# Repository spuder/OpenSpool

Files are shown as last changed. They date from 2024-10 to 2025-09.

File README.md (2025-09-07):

<p align=center>
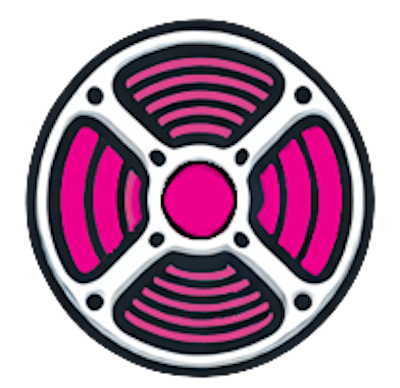
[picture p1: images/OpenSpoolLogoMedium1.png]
    
</p>

# OpenSpool
**Your filament wants to be free**


   

---

# 📖 [OpenSpool.io](https://openspool.io)

Checkout the official documentation on [https://openspool.io](https://openspool.io) 👈

---

<p align="center"> 
    Centered GIF 
</p>

Adhere NFC stickers on all your filament. Build an ESP32 OpenSpool reader and place it next to your printer. 
Touching the filament to the reader will automatically update your Bambu Printer filament settings. 
Almost as seamlessly as if you were using Bambu filament with an AMS. 

## 🖨️ Protocol

| Protocol  | Read | Write | Type |
| --- | --- | --- | --- |
| OpenSpool | ✅ | ✅ | NTAG 215/216 |
| TigerTag | 🚧 In progress | 🚧 In progress | NTAG 213 | 
| Bambu | 🚧 In progress | ❌ | MiFare Classic 1k |
| OpenTag3D | 🚧 In progress | 🚧 In progress | NTAG 213/215/216  |
| Creality  | 🗓️ Planned | 🗓️ Planned | MiFare Classic 1k |
| PrusaRFID | ❓ | ❓ | ❓ |
| Elegoo | 🔍 Researching | 🔍 Researching | ❓ | 
| Anycubic | 🔍 Researching | 🔍 Researching | ❓ | 

### 🧬 OpenTag3D Protocol

Many 3d printer filament companies are uniting around an open standard called `OpenTag3D`. It planned to be finalized in early-mid 2025. OpenSpool will support OpenTag formatted tags as soon as it is finalized. See [here](https://opentag3d.info) for more information.

### 🧬 OpenSpool Protocol

OpenSpool aims to use the simplest possible protocol for RFID tags. All you need is a [NTAG215/216](https://a.co/d/5ojDUNk) 

#### NDEF Record

Example record stored on NFC tag. 

```
type = `application/json`  
payload = 
{
    "protocol": "openspool",
    "version": "1.0",
    "type": "PLA",
    "color_hex": "FFAABB",
    "brand": "Generic",
    "min_temp": "220",
    "max_temp": "240"
}
```

<p align=center>
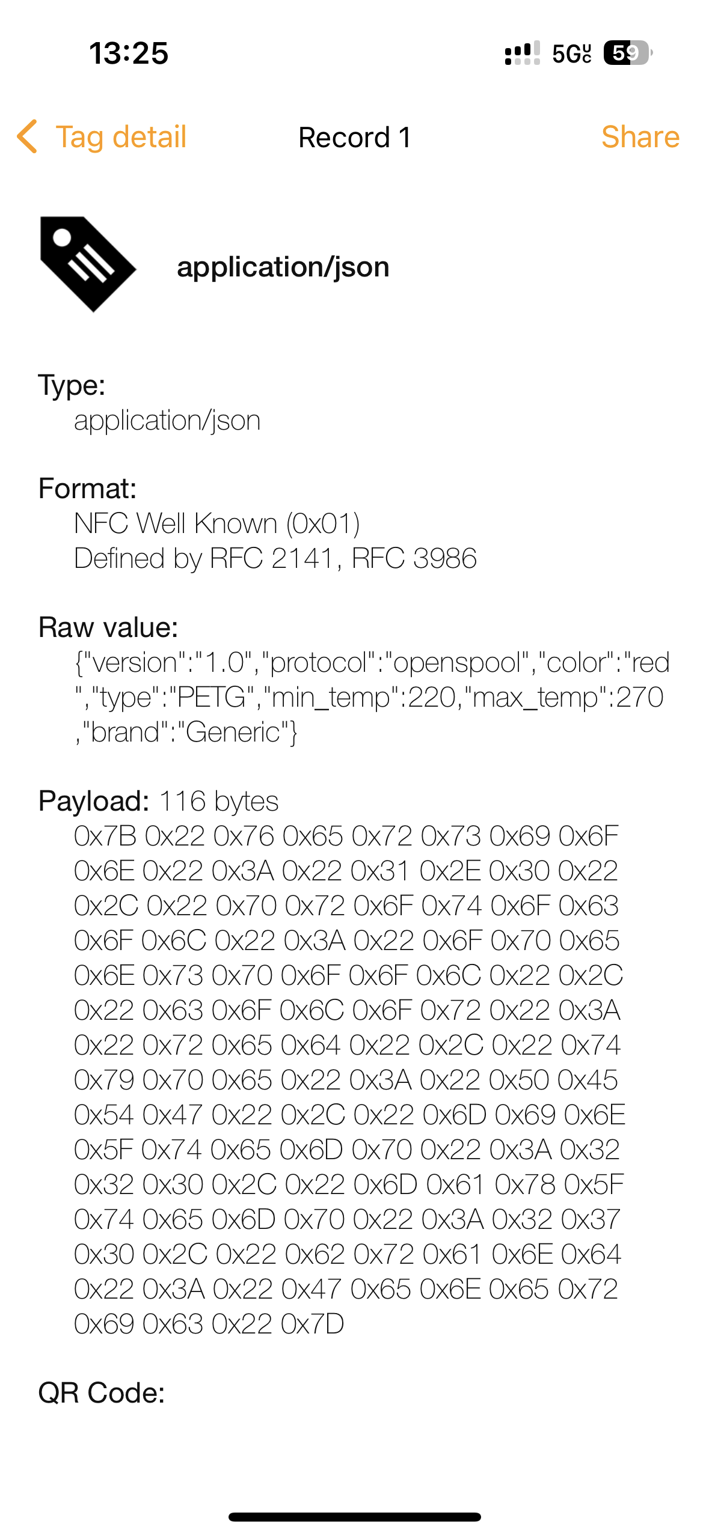
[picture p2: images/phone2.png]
    
</p>

#### Web Preview

Spool information can be seen using your phone.

<p align=center>
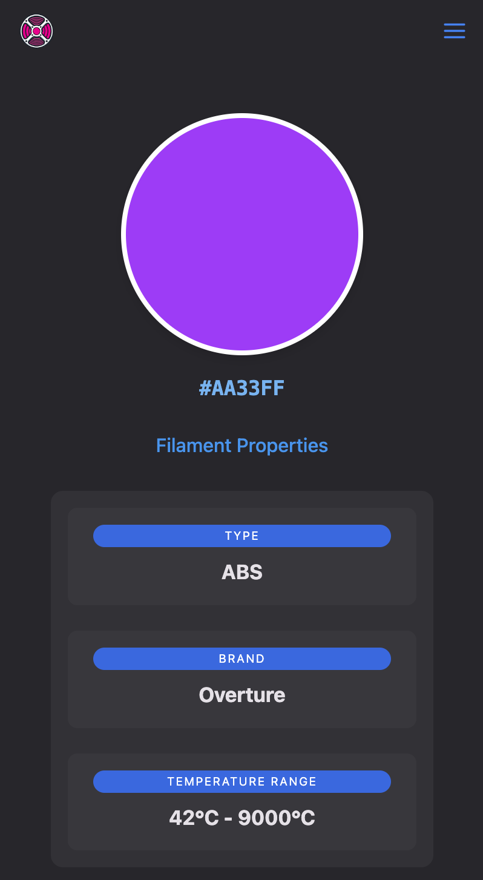
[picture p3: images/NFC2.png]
    
</p>

```
https://openspool.io/tag_info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
```

## 🐼 Integrations

Currently, OpenSpool works with Bambu printers over MQTT. Other integrations are planned. Pull Requests welcome

| Integration | Supported |
| --- | --- |
| Bambu | ✅ |
| OctoPrint | 🚧 In Progress |
| Prusa Connect | 🗓️ Planned |
| SpoolMan | 🗓️ Planned |
| Klipper / Moonraker | 🗓️ Planned |
| Anker | ❔ |

**Bambu**
Bambu X1C printers running `1.08.05.00` or newer must enable `LAN Mode` and `Developer Mode` for the OpenSpool reader to work. [Additional information](https://forum.bambulab.com/t/firmware-01-08-05-00-authorization-control-is-here/152239) on bambu's blog. 

All other Bambu Printers and X1C printers running firmware older than `1.08.05.xx` do not need to enable Developer Mode. 

## 🔧 Hardware

The OpenSpool schematics will always be free. If you don't want to source the parts yourself, you can [buy a kit on tindie.com](https://www.tindie.com/products/36746/).




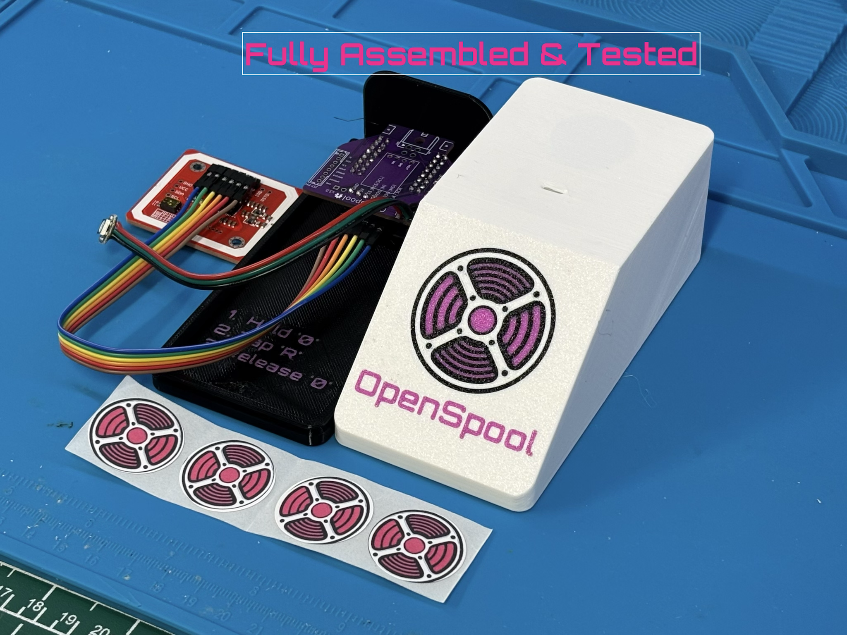
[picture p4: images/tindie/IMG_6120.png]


### Bill of Materials

| Image | Hardware | Link 1 | Link 2 |
| - | - | - | - |
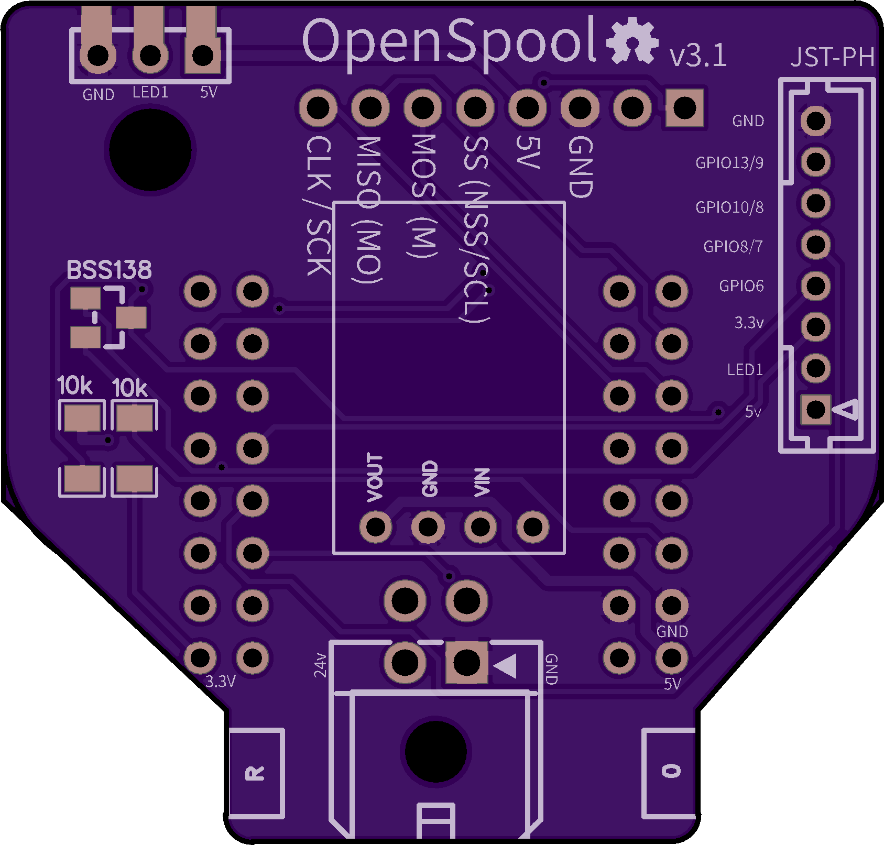
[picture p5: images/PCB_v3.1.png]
|  | OpenSpool Mini PCB v3.1 * | [Gerber Files](./hardware/openspool-mini/v3.1) | |
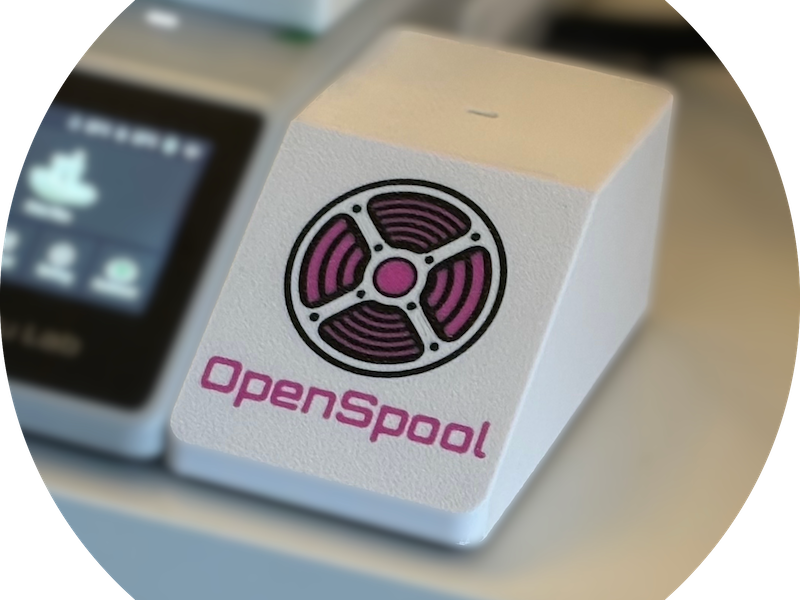
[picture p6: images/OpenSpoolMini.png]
|  | OpenSpool Mini Enclosure (3D Printed) | [MakerWorld](https://makerworld.com/en/models/944499-openspool-mini#profileId-910780) | |
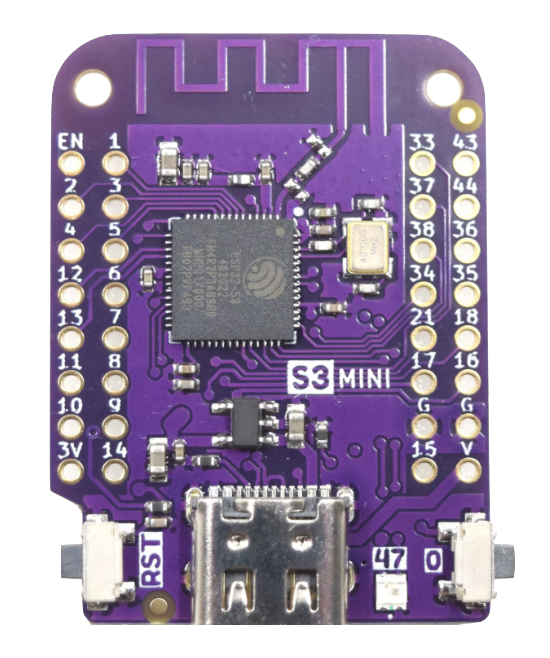
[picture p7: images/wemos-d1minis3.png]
|  | Wemos D1 Mini s3 |  | [AliExpress](https://www.aliexpress.us/item/3256805262904443.html?gatewayAdapt=glo2usa) |
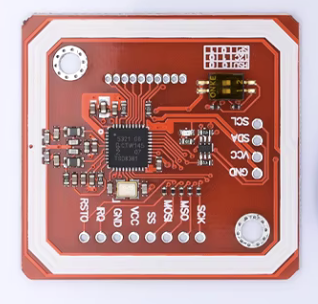
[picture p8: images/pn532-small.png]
|  | PN532 (Small)| [Amazon](https://amzn.to/4eoBz8s) | [AliExpress](https://www.aliexpress.us/item/3256805787598774.html) |
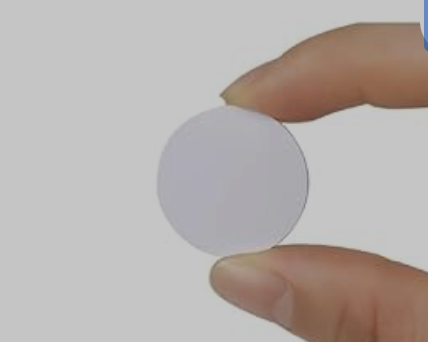
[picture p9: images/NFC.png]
|  | NTAG 215/216 (13.56Mhz NFC Tags >500 bytes) | [Amazon](https://amzn.to/4epJzpO) | |
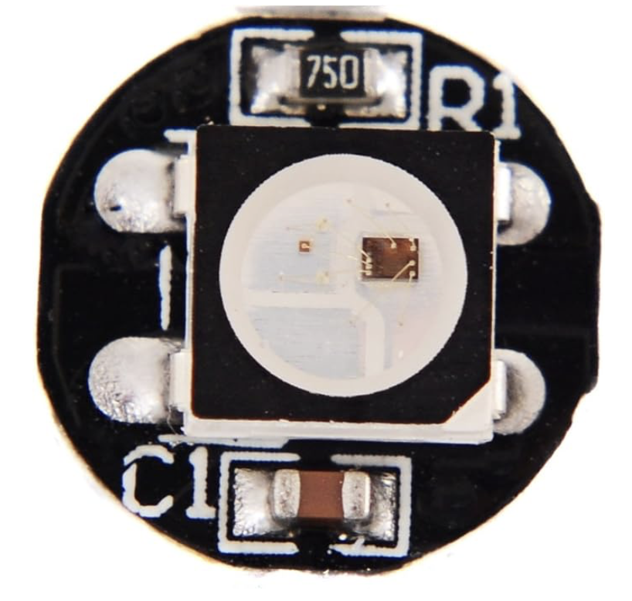
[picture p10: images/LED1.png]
|  | WS2812B LED | [Amazon](https://amzn.to/40FFOt5) | |
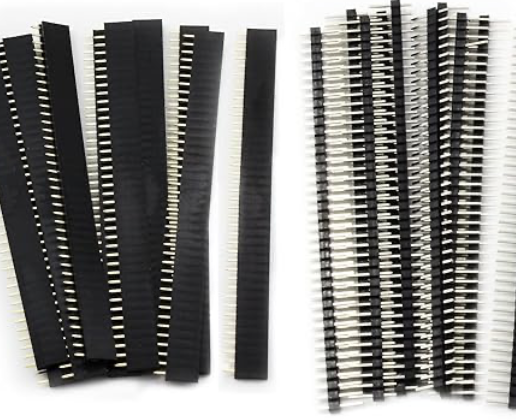
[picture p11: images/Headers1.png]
|  | 2.54mm Straight Headers | [Amazon](https://amzn.to/4en6138) | |
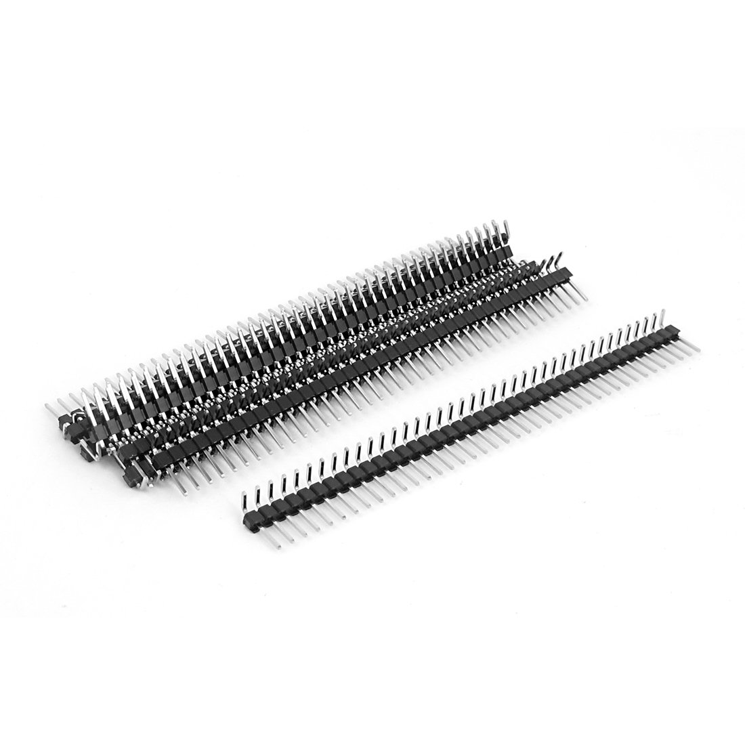
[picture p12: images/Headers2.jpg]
|  | 2.54mm Right-Angle Headers | [Amazon](https://a.co/d/8wWGSP4)  | |
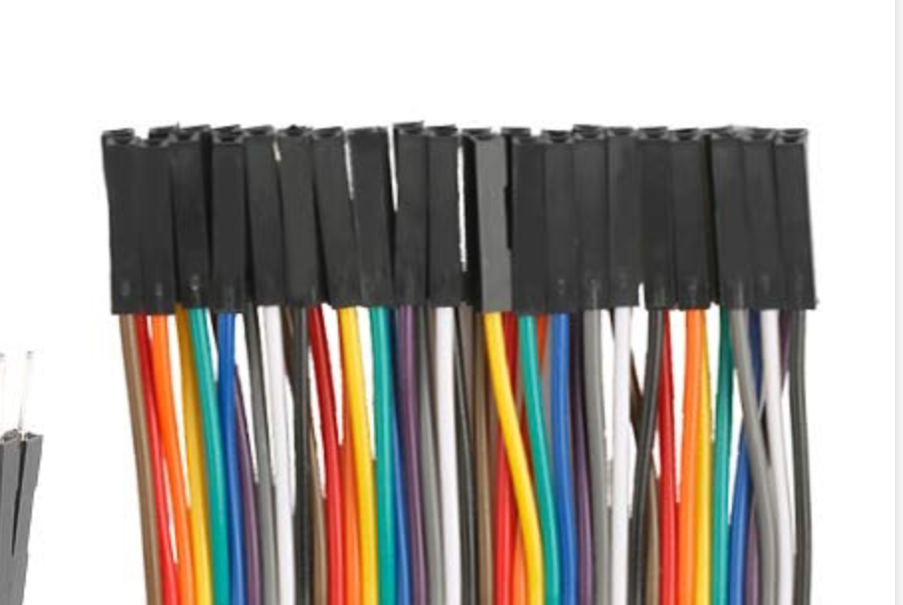
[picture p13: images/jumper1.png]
|  | Female-Female jumper wire | [Amazon](https://amzn.to/3AMwRDM) | |
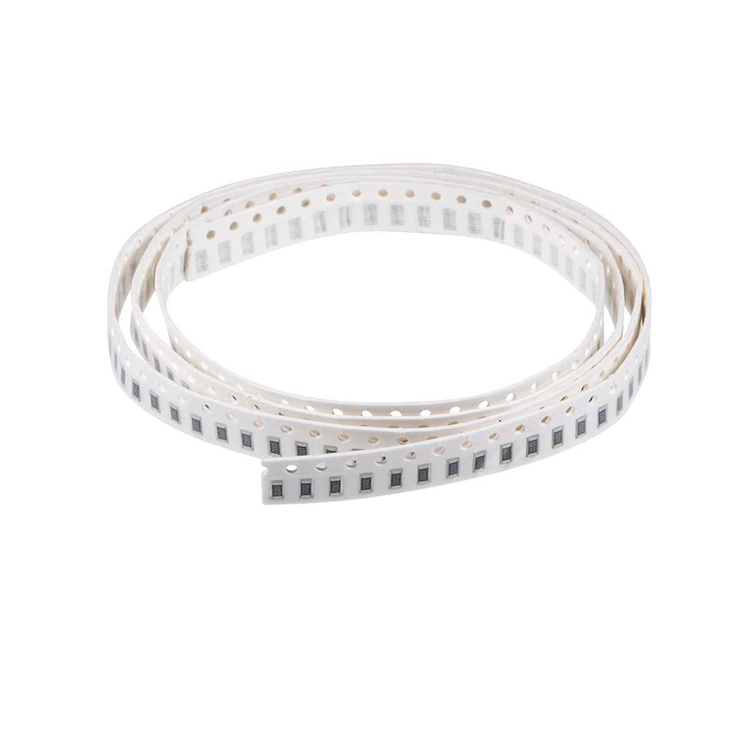
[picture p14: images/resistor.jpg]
|  | 1206 10k SMD Resistor * | [Amazon](https://a.co/d/if5dfrw)  | |
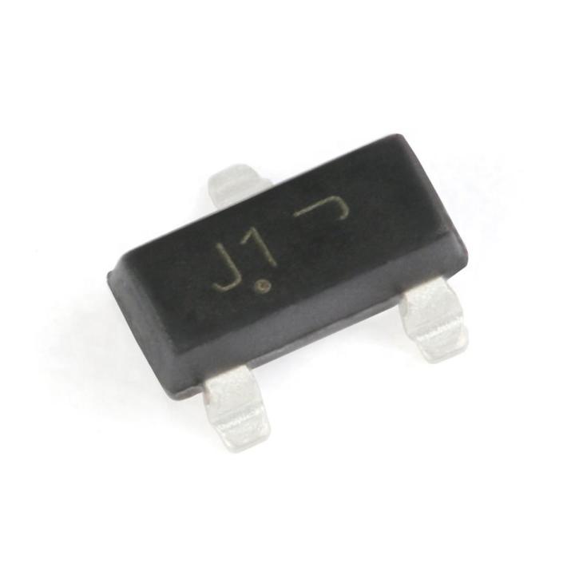
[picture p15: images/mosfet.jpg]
|  | BSS138 MOSFET * | [Amazon](https://a.co/d/3Gm1ZOv) | |

If you are unable to find a Wemos D1 Mini `s3`, you can still buy an `s2`, as it is pin compatable. However, be advised the `s2` has less memory and may experience occasional disconnects from the printer.

| Image  | Hardware  | Link 1  | Link 2 |
| --- | --- | --- | --- |
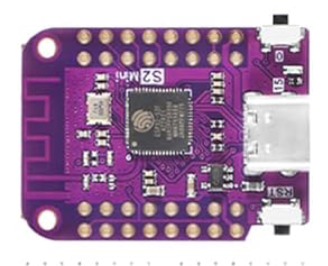
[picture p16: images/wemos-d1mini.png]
|  | Wemos D1 Mini S2 (Beware of Fakes!) | [Amazon](https://amzn.to/4fqq9m7) | [AliExpress](https://www.aliexpress.us/item/3256802958877264.html) |

---

It is recommend to assemble OpenSpool using the custom PCB. You can send the Gerber files included in this repository to a PCB fabricator, such as [OSH Park](https://oshpark.com/).

#### Without Custom PCB

OpenSpool can be assembled without fabricating the custom PCB. In place of the MOSFET and resistor, you will need the following components:

| Image | Hardware | Link 1 | Link 2 |
| - | - | - | - |
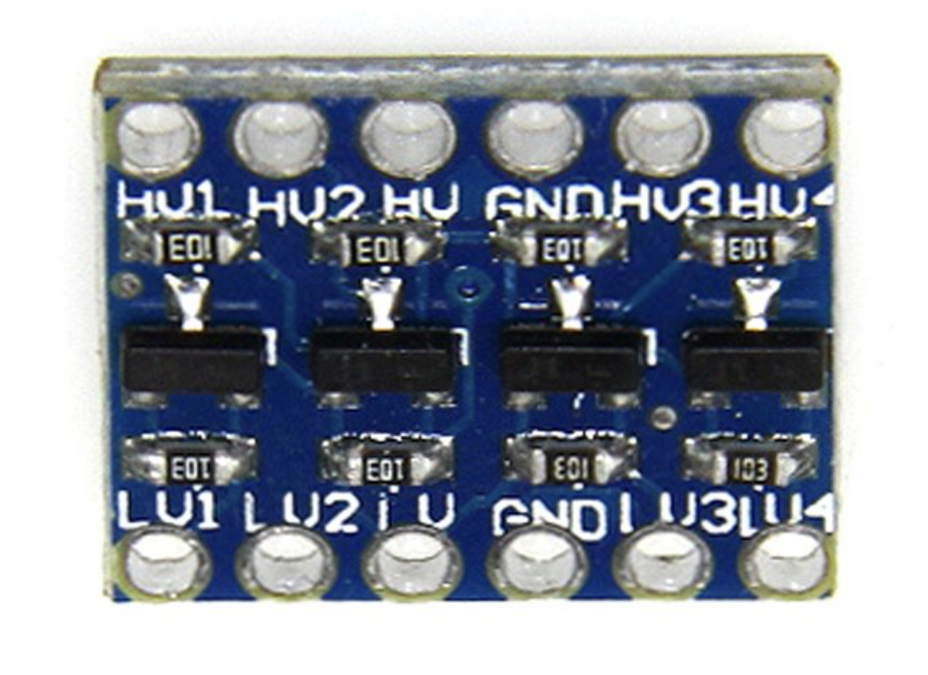
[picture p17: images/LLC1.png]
|  | 3.3v - 5v Logic Level Converter | [Amazon](https://amzn.to/3UMfMkp) | |
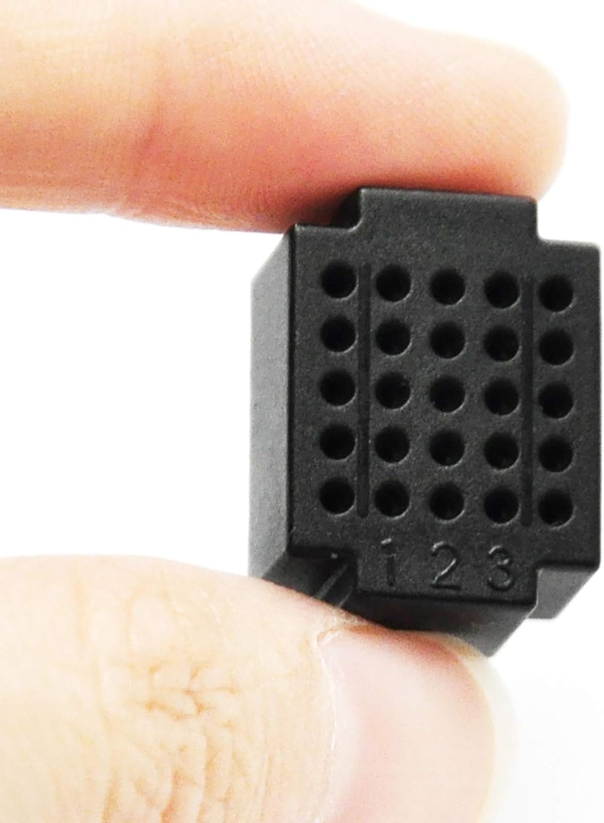
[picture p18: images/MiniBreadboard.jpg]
|  | Mini Breadboard | [Amazon](https://a.co/d/cF1jjVI) | |

You can use any breadboard or splicing tool to connect the wires, however the linked mini breadboard is recommended as it is small enough to fit inside the enclosure.

## 🛠️ Assembly

Once you have all of the parts, you can begin assembly.

### With Custom PCB

1. Solder the following components onto the PCB:
    1. Two 10k resistors
    2. One BSS138 MOSFET
    3. Four sets of 8 straight headers, into the two pairs of columns on the top of the PCB
    4. One set of 8 right-angle headers into the row of vias just below the OpenSpool logo on the BACK side of the PCB
    5. Three right-angle headers in the top-left corner of the PCB
2. Solder eight right-angle headers onto the top side of the PN532
3. Solder three straight headers onto the LED. Make sure to solder them onto the side with the "Din" pin
4. Place the Wemos D1 onto the headers and solder it on. The top of the Wemos D1 should face up, with the USB-C port facing the bottom of the PCB
5. Use jumper wires to connect both the PN532 and the LED to their respective headers
6. Flip the toggle switches on the PN532 to enable SPI mode (see image below)

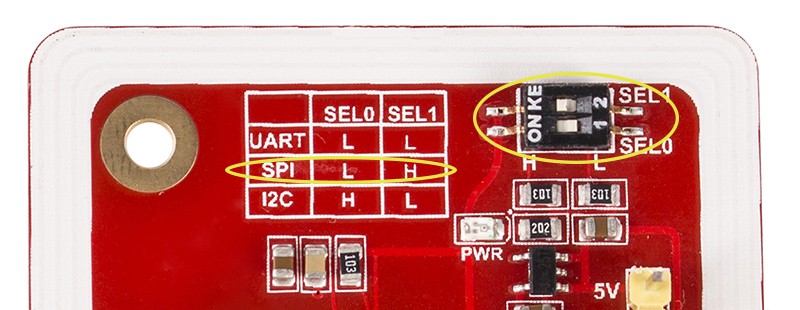
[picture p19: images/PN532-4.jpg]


### Without Custom PCB

If you are not using the custom PCB, you will need to connect the wires to each pin manually. Below is the wiring diagram:

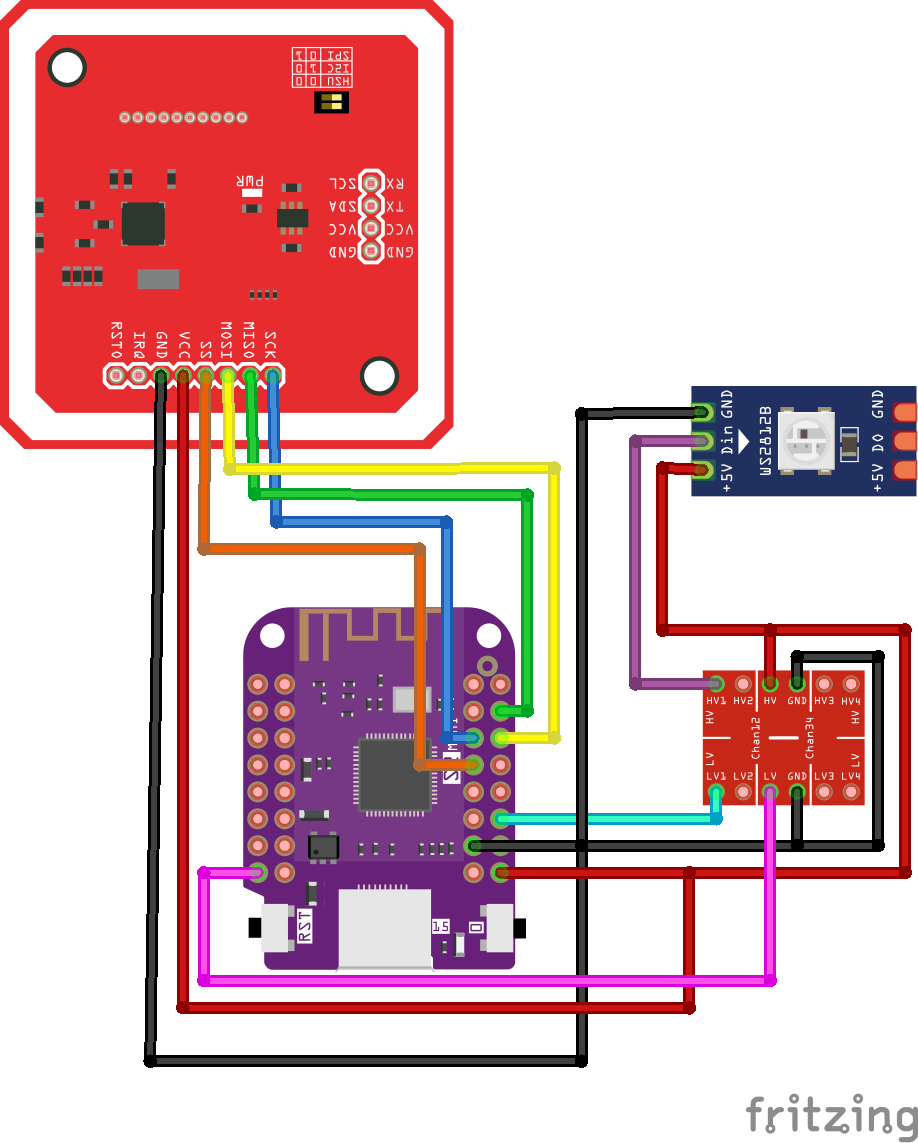
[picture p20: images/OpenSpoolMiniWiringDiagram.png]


## 🤖 Firmware

The recommended method to install firmware is by navigating to [openspool.io](https://openspool.io) in Chrome/Edge and using the web based programming tool. 

Alternatively the firmware can be installed with `make` commands as shown below. 

### OSX/Linux

```
brew install esphome

git clone https://github.com/spuder/OpenSpool
cd OpenSpool/firmware
```

Press and hold the D0 button while pressing the reset button on the Wemos D1 Mini.  
A new USB serial device will appear. 

```bash
ls /dev/cu*
```

Upload firmware and restart

```bash
USB_ADDRESS=/dev/cu.usbmodemXXXXX make lolin_s2_mini
```

or

```bash
USB_ADDRESS=/dev/cu.usbmodemXXXXX make lolin_s3_mini
```

## 🛜 First Time Configuration

A new Wi-Fi network will appear called `OpenSpool`, join the network, navigate to [192.168.4.1](http://192.168.4.1), insert your Wi-Fi credentials and reboot. 

You can then navigate to the web interface at `openspool-xxxxxx.local` or IP address. 

## 🎛️ Configuration

On first boot, you will need to specify your 3d printer IP Address, Serial Number and LAN Access Code. 

Do not put your printer into LAN Only Mode, it is not required. 

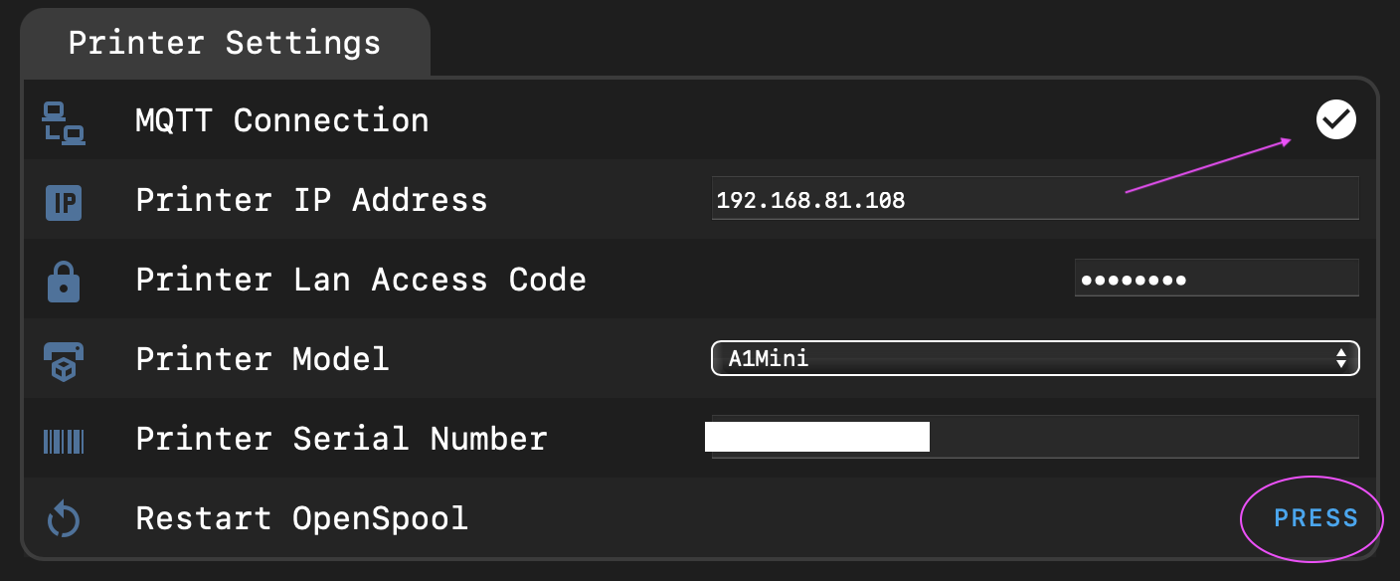
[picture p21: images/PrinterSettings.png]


After changing these 3 settings, you will need to reboot the ESP32. 
Upon successful connection to the 3d printer, you will observe a checkmark next to MQTT in the web interface.

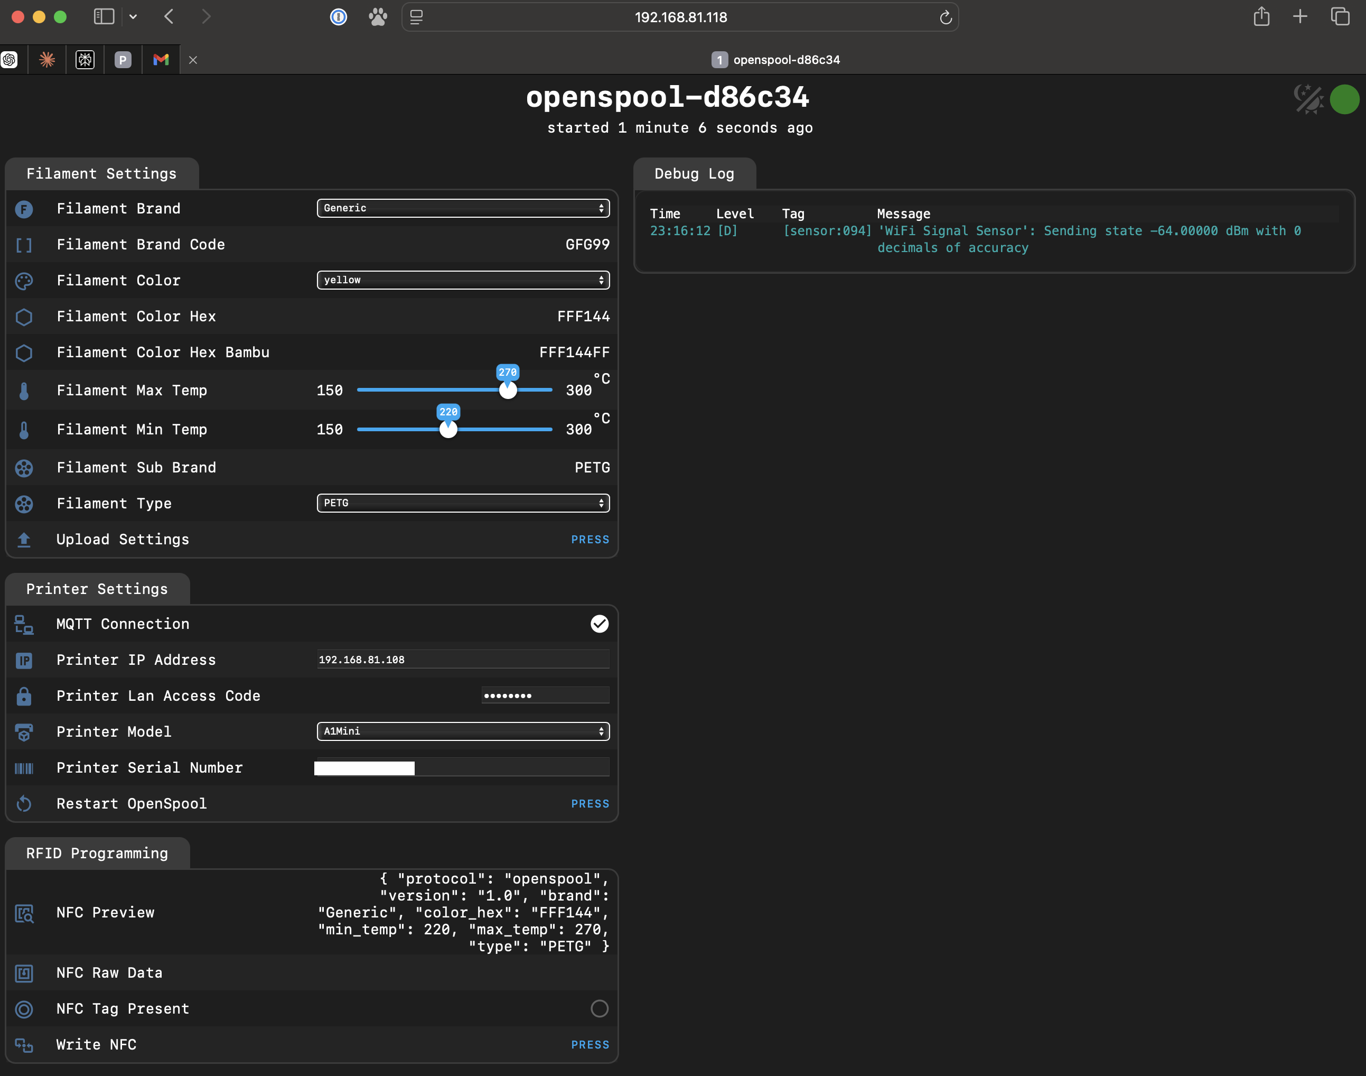
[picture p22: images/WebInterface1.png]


## Factory Reset

Press and hold the D0 button for 10 seconds. 
This will erase Wi-Fi credentials and Bambu access credentials from esp32. 

# 🔧 Troubleshooting

### LED is breathing blue
This means the OpenSpool is hosting a wireless access point called 'OpenSpool'. Connect to it then navigate to [192.168.4.1](http://192.168.4.1) to configure Wi-Fi. 

### LED is solid white
OpenSpool has successfully joined the Wi-Fi network and is ready to scan for RFID tags

### NFC Tags aren't reading reliably

If using the red NP5332 reader (smaller model), it detects tags best on the corners of the antenna. 

If using the blue PN532 reader (larger model), it detects tags best directly in the center of the antenna.   

Be sure you aren't using a [counterfeit PN532](https://forum.dangerousthings.com/t/success-pn532-is-not-easy-to-work-with/1108/10)

### MQTT Disconnects

The A1/P1 have a limit of 4 mqtt connections. If more than 4 connections are reached clients may be asked to disconnect. 

If a client attempts to write invalid data any mqtt topic, the printer will ask the client to disconnect. 
All ESPhome resources must use `state_topic:` with a null value to prevent ESPhome from broadcasting on any topic. 

### TLS Errors

Reach out to the discord for help to verify that the Root Certificate is correct. 

### Advanced Troubleshooting

Use the [MQTTX client](https://mqttx.app) to observe the messages that OpenSpool and Bambu Printer are sending. 

```bash
mqttx sub -t 'device/$SERIAL_NUMBER/report' -u bblp -P $LAN_ACCESS_CODE --mqtt-version 3.1.1 -h $IP_ADDRESS -p 8883 -l mqtts --insecure
```

## 🎥 Demo

(https://youtube.com/watch?v=ah7dm-dtQ5w)
(https://youtube.com/shorts/pWnvJc-8KLI?si=9-C1rhqrvL1i5CpR)
(https://www.youtube.com/shorts/kvVpRKFNU9k)

# 👥 Contributors

<!-- readme: contributors -start -->
<table>
	<tbody>
		<tr>
            <td align="center">
                <a href="https://github.com/spuder">
                    spuder
                    <br />
                    <sub><b>Spencer Owen</b></sub>
                </a>
            </td>
            <td align="center">
                <a href="https://github.com/raihei">
                    raihei
                    <br />
                    <sub><b>raihei</b></sub>
                </a>
            </td>
            <td align="center">
                <a href="https://github.com/EmberLightVFX">
                    EmberLightVFX
                    <br />
                    <sub><b>Ember Light</b></sub>
                </a>
            </td>
            <td align="center">
                <a href="https://github.com/queengooborg">
                    queengooborg
                    <br />
                    <sub><b>Queen Vinyl Da.i'gyu-Kazotetsu</b></sub>
                </a>
            </td>
            <td align="center">
                <a href="https://github.com/Tnthr">
                    Tnthr
                    <br />
                    <sub><b>Tnthr</b></sub>
                </a>
            </td>
            <td align="center">
                <a href="https://github.com/phillipthelen">
                    phillipthelen
                    <br />
                    <sub><b>Phillip Thelen</b></sub>
                </a>
            </td>
		</tr>
		<tr>
            <td align="center">
                <a href="https://github.com/thijstriemstra">
                    thijstriemstra
                    <br />
                    <sub><b>Thijs Triemstra</b></sub>
                </a>
            </td>
            <td align="center">
                <a href="https://github.com/thomasjpatterson">
                    thomasjpatterson
                    <br />
                    <sub><b>secprepper</b></sub>
                </a>
            </td>
		</tr>
	<tbody>
</table>
<!-- readme: contributors -end -->

# 📜 Certifications

<p align="center">
    <a href="https://certification.oshwa.org/us002704.html">
        
    </a>
</p>
<p align="center">
    <a href="https://certification.oshwa.org/us002704.html">
        
    </a>
</p>
<p align="center">
    <a href="https://certification.oshwa.org/us002704.html">OSHWA Certification: US002704</a>
</p>

<p align="center">
    <a href="https://devices.esphome.io/devices/OpenSpool">
        
    </a>
</p>
<p align="center">
    <a href="https://devices.esphome.io/devices/OpenSpool">ESPHome Device Listing</a>
</p>

# 🪪 License

<p align="left">
    <a href="https://oshwa.github.io/certification-mark-generator/facts">
        
    </a>
</p>

# Donations

All contributions to the project are welcome. Skills needed:

- Software Development
- Photography
- Videography
- Documentation
- Electrical Design
- Testing/Integration

You can also donate to support research and development costs

"Buy Me A Coffee" (https://www.buymeacoffee.com/openspool)


https://oshwlab.com/owenspencer/openspool-mini

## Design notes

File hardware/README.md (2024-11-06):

## Fritzing Library Credit

PN532: https://domoticx.com/module-pn532-rfid-nfc-transciever/

Wemos D1 Mini S2: https://forum.fritzing.org/t/esp32-s2-mini-part/18737/2

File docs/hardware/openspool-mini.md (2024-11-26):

---
layout: default
title: OpenSpool-Mini
parent: Hardware
nav_order: 1
---

# OpenSpool Mini

<p align=center>
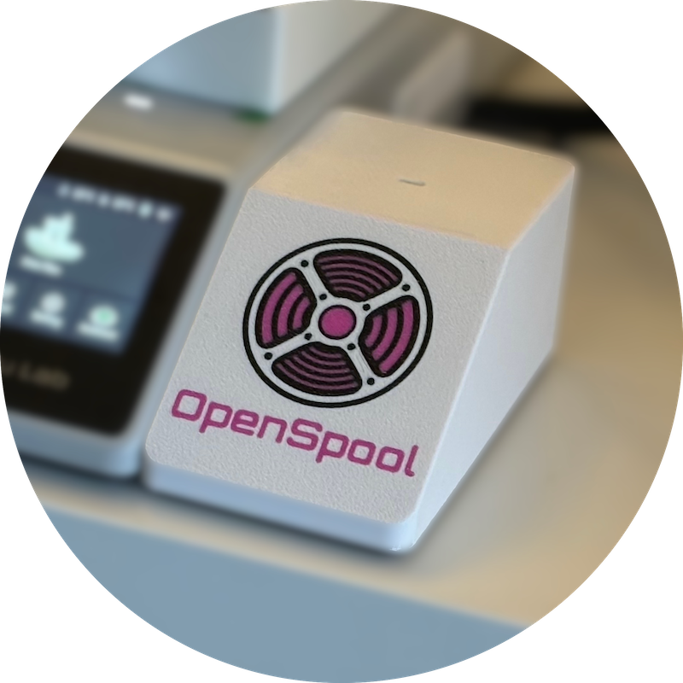
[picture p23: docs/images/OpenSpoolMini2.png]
    
</p>

## Links

| --- | --- |
| 3MF/STL Files | <span class="label label-yellow">Coming soon</span> | 
| Fusion360 CAD Files | <span class="label label-yellow">Coming soon</span>

## Wiring Diagram

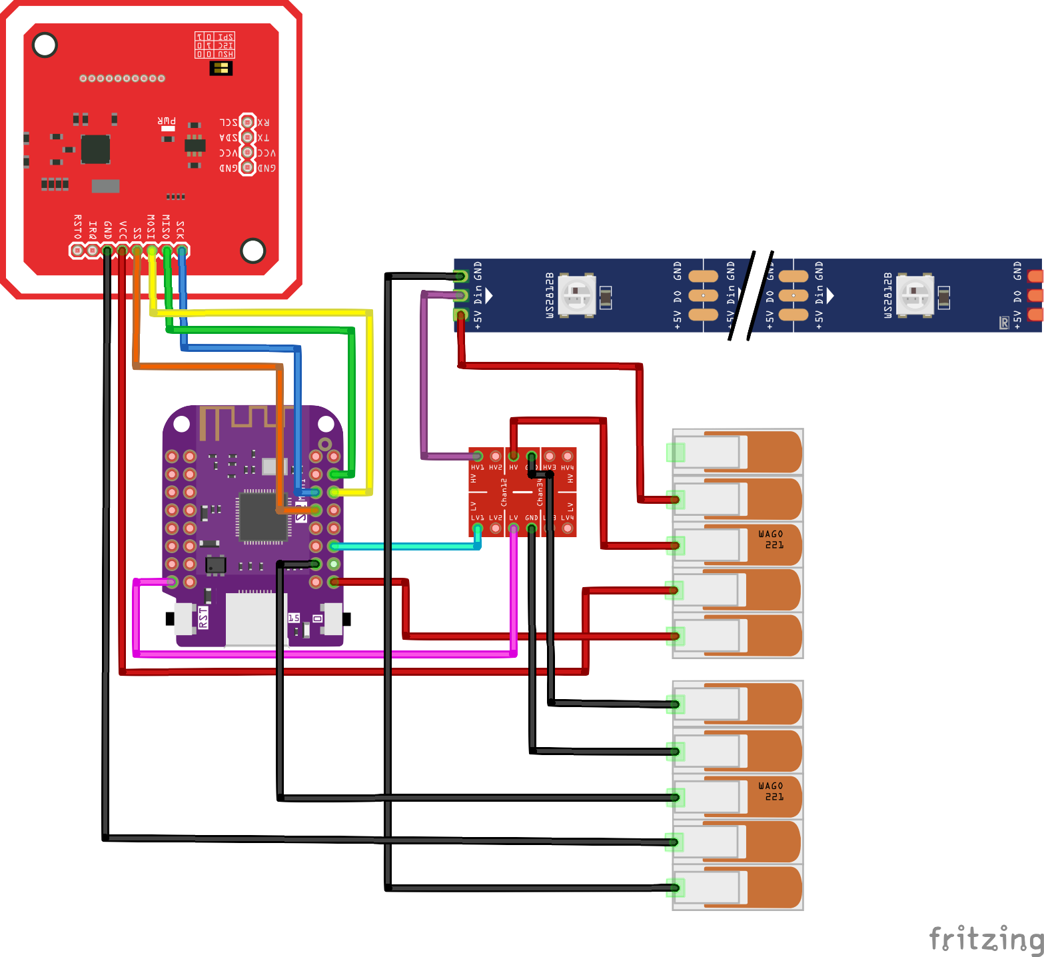
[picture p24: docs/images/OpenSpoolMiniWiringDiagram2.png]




## Assembly Video: 

Coming soon
{: .label .label-yellow }

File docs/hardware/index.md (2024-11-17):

---
title: Hardware
has_children: true
has_toc: true
nav_order: 3
---

<div class="image-container">
    <div class="image-item">
        <a href="{{ '/hardware/openspool-mini' | relative_url }}">
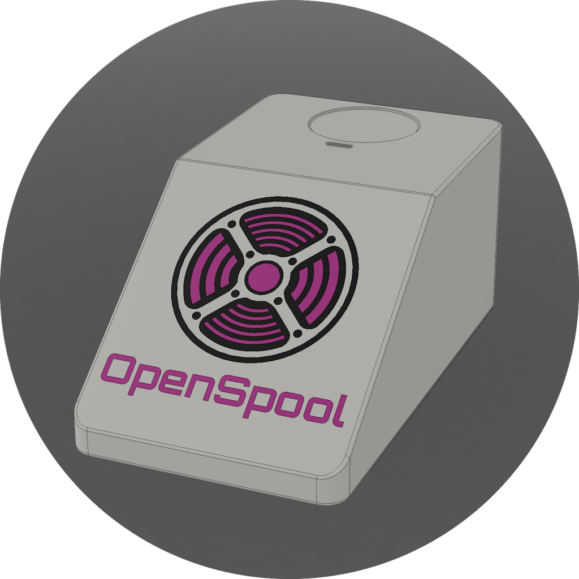
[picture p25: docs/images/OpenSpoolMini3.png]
OpenSpoolMini2
            
        </a>
        <a href="{{ '/hardware/openspool-mini' | relative_url }}">
            <button type="button" name="button" class="btn">OpenSpool Mini</button>
        </a>
    </div>
    <div class="image-item">
        <a href="{{ '/hardware/openspool-ams' | relative_url }}">
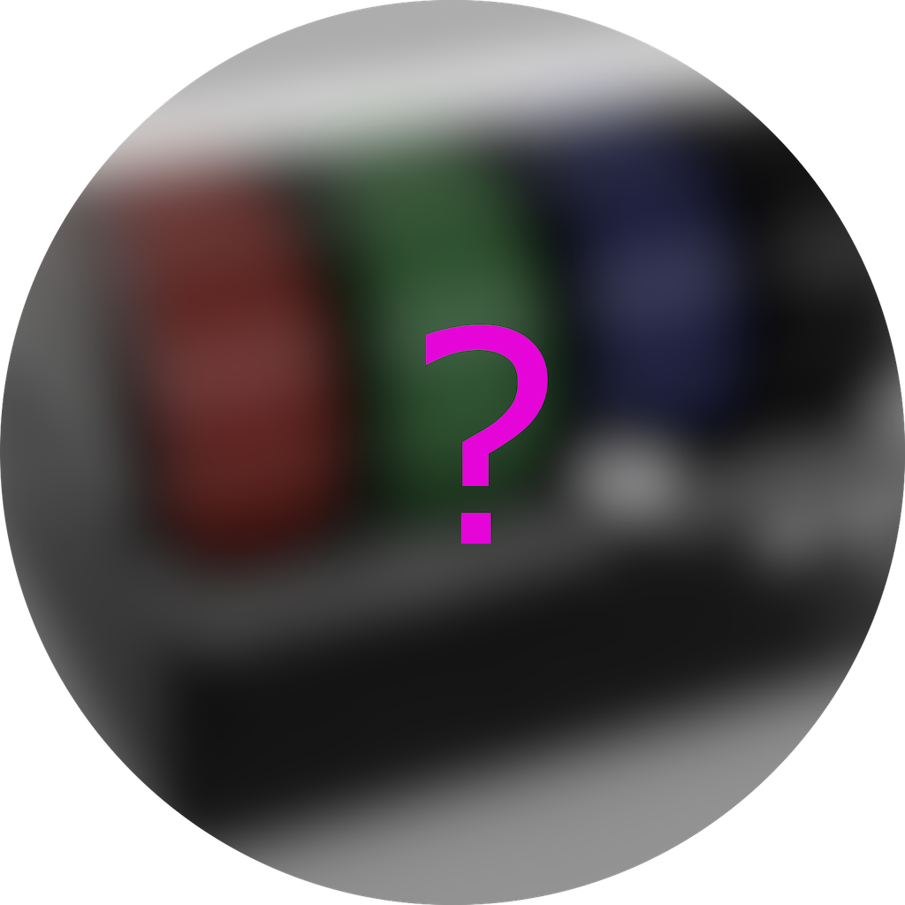
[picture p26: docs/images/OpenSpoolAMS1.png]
OpenSpoolAMS1
            
        </a>
        <a href="{{ '/hardware/openspool-ams' | relative_url }}">
            <button type="button" name="button" class="btn">OpenSpool AMS</button>
        </a>
    </div>
</div>

<style>
.image-container {
  display: flex;
  justify-content: center;
  align-items: flex-start;
  gap: 20px;
}

.image-item {
  display: flex;
  flex-direction: column;
  align-items: center;
}

.image-item img {
  max-width: 100%;
  height: auto;
  object-fit: cover;
  object-position: center;
}

.btn {
  margin-top: 10px;
}
</style>

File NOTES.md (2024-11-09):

#PN532

https://forum.dangerousthings.com/t/success-pn532-is-not-easy-to-work-with/1108

https://stackoverflow.com/questions/43563378/how-do-i-read-passive-nfc-rfid-units-with-pn532

Beware some PN532 are clones and don't work as well

https://forum.dangerousthings.com/t/success-pn532-is-not-easy-to-work-with/1108/10

# Filament Mappings
WolfWithSword identified these mappings
```
// "func": "// Bambu spools are not needed for translation if they have the rfid tags
// but this can be used to overwrite them for HA displaying only
// This only overwrites the tray_type and tray_sub_brands, if you want other fields overwritten you can add them
// e.g.  tray_diameter, tray_weight, temps etc

var PolyLite_PLA = {
    \"tray_info_idx\": \"GFL00\", 
    \"tray_type\": \"PLA\",
    \"tray_sub_brands\": \"PolyLite PLA\"
}

var PolyTerra_PLA = {
    \"tray_info_idx\": \"GFL01\",
    \"tray_type\": \"PLA\",
    \"tray_sub_brands\": \"PolyTerra PLA\"
}

var Bambu_ABS = {
    \"tray_info_idx\": \"GFB00\",
    \"tray_type\": \"ABS\"
}

var Bambu_PACF = {
    \"tray_info_idx\": \"GFN03\",
    \"tray_type\": \"PA-CF\"
}

var Bambu_PC = {
    \"tray_info_idx\": \"GFC00\",
    \"tray_type\": \"PC\"
}

var Bambu_PLA_Basic = {
    \"tray_info_idx\": \"GFA00\",
    \"tray_type\": \"PLA\",
    \"tray_sub_brands\": \"PLA Basic\"
}
var Bambu_PLA_Matte = {
    \"tray_info_idx\": \"GFA01\",
    \"tray_type\": \"PLA\",
    \"tray_sub_brands\": \"PLA Matte\"
}

var Support_G = {
    \"tray_info_idx\": \"GFS01\",
    \"tray_type\": \"Support\",
    \"tray_sub_brands\": \"Support G\"
}

var Support_W = {
    \"tray_info_idx\": \"GFS00\",
    \"tray_type\": \"Support\",
    \"tray_sub_brands\": \"Support W\"
}

var Bambu_TPU_95A = {
    \"tray_info_idx\": \"GFU01\",
    \"tray_type\": \"TPU\",
    \"tray_sub_brands\": \"TPU 95A\"
}

var Generic_ABS = {
    \"tray_info_idx\": \"GFB99\",
    \"tray_type\": \"ABS\",
    \"tray_sub_brands\": \"ABS\"
}

var Generic_ASA = {
    \"tray_info_idx\": \"GFB98\",
    \"tray_type\": \"ASA\",
    \"tray_sub_brands\": \"ASA\"
}

var Generic_PA = {
    \"tray_info_idx\": \"GFN99\",
    \"tray_type\": \"PA\",
    \"tray_sub_brands\": \"PA\"
}

var Generic_PACF = {
    \"tray_info_idx\": \"GFN98\",
    \"tray_type\": \"PA-CF\",
    \"tray_sub_brands\": \"PA-CF\"
}

var Generic_PC = {
    \"tray_info_idx\": \"GFC99\",
    \"tray_type\": \"PC\",
    \"tray_sub_brands\": \"PC\"
} 

var Generic_PETG = {
    \"tray_info_idx\": \"GFG99\",
    \"tray_type\": \"PETG\",
    \"tray_sub_brands\": \"PETG\"
}
var Generic_PLA = {
    \"tray_info_idx\": \"GFL99\",
    \"tray_type\": \"PLA\",
    \"tray_sub_brands\": \"PLA\"
}
var Generic_PLACF = {
    \"tray_info_idx\": \"GFL98\",
    \"tray_type\": \"PLA-CF\",
    \"tray_sub_brands\": \"PLA-CF\"
}
var Generic_PVA = {
    \"tray_info_idx\": \"GFS99\",
    \"tray_type\": \"PVA\",
    \"tray_sub_brands\": \"PVA\"
}
var Generic_TPU = {
    \"tray_info_idx\": \"GFU99\",
    \"tray_type\": \"TPU\",
    \"tray_sub_brands\": \"TPU\"
}

var Bambu_PETCF = {
    \"tray_info_idx\": \"GFT00\",
    \"tray_type\": \"PET-CF\"
}

var Bambu_PLA_Impact = {
    \"tray_info_idx\": \"GFA03\",
    \"tray_type\": \"PLA\",
    \"tray_sub_brands\": \"PLA Impact\"
}

var Bambu_PLA_Metal = {
    \"tray_info_idx\": \"GFA02\",
    \"tray_type\": \"PLA\",
    \"tray_sub_brands\": \"PLA Metal\"
}

var filament_library = {
    \"GFU99\": Generic_TPU,
    \"GFS99\": Generic_PVA,
    \"GFL98\": Generic_PLACF,
    \"GFL99\": Generic_PLA,
    \"GFG99\": Generic_PETG,
    \"GFC99\": Generic_PC,
    \"GFN98\": Generic_PACF,
    \"GFN99\": Generic_PA,
    \"GFB98\": Generic_ASA,
    \"GFB99\": Generic_ABS,
    \"GFU01\": Bambu_TPU_95A,
    \"GFS00\": Support_W,
    \"GFS01\": Support_G,
    \"GFA01\": Bambu_PLA_Matte,
    \"GFA00\": Bambu_PLA_Basic,
    \"GFC00\": Bambu_PC,
    \"GFN03\": Bambu_PACF,
    \"GFB00\": Bambu_ABS,
    \"GFL01\": PolyTerra_PLA,
    \"GFL00\": PolyLite_PLA
}

if (msg.payload.print.ams !== undefined) {
    for (var ams of msg.payload.print.ams.ams) {
        for (var tray of ams.tray) {
            if (tray.tray_info_idx !== undefined && tray.tray_info_idx !== \"\") {
                if(filament_library.hasOwnProperty(tray.tray_info_idx)) {
                    var match = filament_library[tray.tray_info_idx];
                    tray.tray_type = match.tray_type;
                    tray.tray_sub_brands = match.tray_sub_brands;
                    if (tray.tray_diameter == \"0.00\") {
                        tray.tray_diameter = \"1.75\";
                    }
                }
            }
        }
    }
}
if(msg.payload.print.vt_tray != undefined) {
    if (msg.payload.print.vt_tray.tray_info_idx != undefined) {
        if (filament_library.hasOwnProperty(msg.payload.print.vt_tray.tray_info_idx)) {
            var match = filament_library[msg.payload.print.vt_tray.tray_info_idx];
            msg.payload.print.vt_tray.tray_type = match.tray_type;
            msg.payload.print.vt_tray.tray_sub_brands = match.tray_sub_brands;
            if (msg.payload.print.vt_tray.tray_diameter == \"0.00\") {
                msg.payload.print.vt_tray.tray_diameter = \"1.75\";
            }
        }
    }
}

node.send(msg);",
```

https://github.com/EmileSpecialProducts/Turtle-ESP-mouse-jiggler

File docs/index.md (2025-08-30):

---
title: Home
layout: home
nav_order: 1
---

# 📟 OpenSpool Firmware Installation



<div class="install-container">
    <script type="module" src="https://unpkg.com/esp-web-tools@8.0.6/dist/web/install-button.js"></script>

    <h2> 🔩 Install the firmware</h2>
    
    <div class="button-row">
        <esp-web-install-button 
            manifest="https://openspool.io/firmware/manifest.json">
        <span slot="unsupported"> <b>Only  /  Supported</b> </span>

        <span slot="not-allowed">🔒 HTTPS Required 🔒 </span>
        </esp-web-install-button>
    </div>

    <div class="instructions">
        <h3>Installation Instructions</h3>
        <p>1. Connect your OpenSpool device via USB</p>
        <p>2. Press & Hold D0 Button</p>
        <p>3. Press RST Button</p>
        <p>4. Release both D0 and RST simultaneously</p>
        <p>5. Click the blue 'Connect' button above</p>
        <p>6. Follow the installation wizard</p>
    </div>
</div>

{: .caution }
If the above step fails, see the [README on github](https://github.com/spuder/OpenSpool) to upload manually with command `make lolin_s2_mini` or `make lolin_s3_mini`. 

# 🛠️ Configuration

Once the firmware is installed, You will need to join the RFID reader to the same network as your 3d printer. 

## 🛜 Wireless Configuration

1. Join the wifi network `OpenSpool`
2. Navigate to [192.168.4.1](http://192.168.4.1)
3. Enter your wifi credentials (take note of the mac address, you will need it to connect)
4. Reboot the RFID Reader

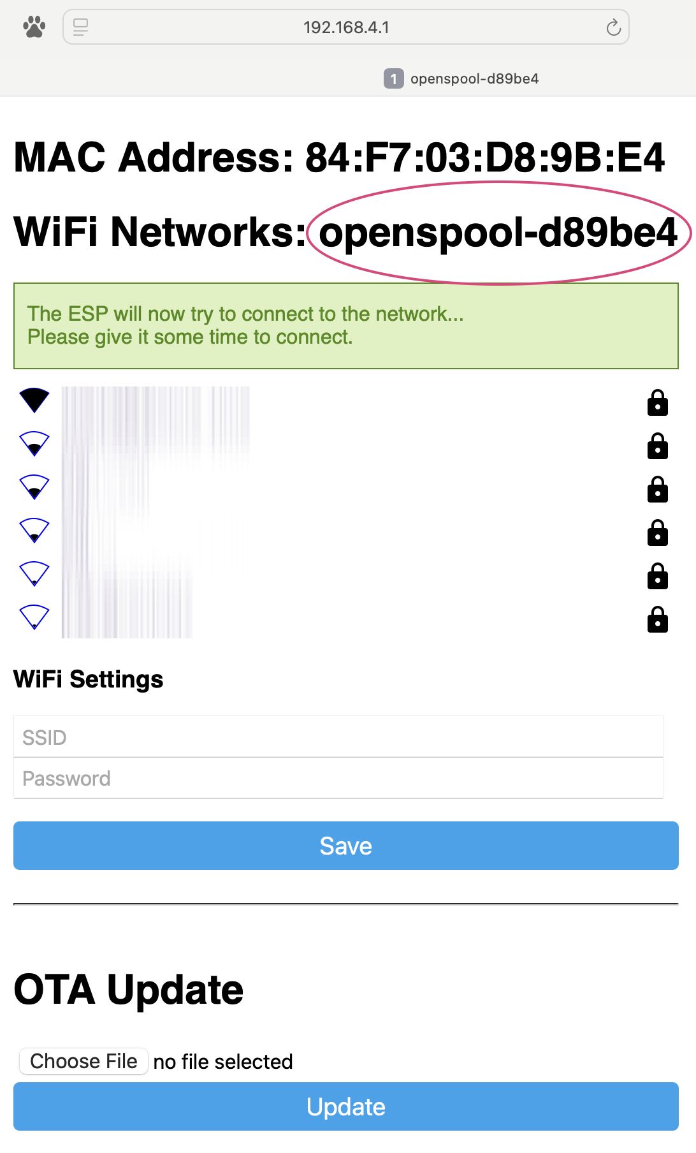
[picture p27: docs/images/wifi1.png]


After reboot connect to http://openspool-d89be4.local (where d89be is your specific mac address)

## 🖨️ Printer Configuration

Once openspool has joined your network, navigate to `openspool-xxxxxx.local`, or ip address (where xxxxxx are the last 6 digits of the mac address).

If you forgot the mac address, or if you computer is unable to resolve `.local` domains. You can always connect via ip address. To find the ip address, consult your router documentation, or search your arp table. Instructions below. 

{: .note-title } 
> Finding IP Address via ARP Tables
>
> Mac/Linux:  `arp -a | grep openspool`  
> Windows: `arp -a` 

Enter your Printer IP, LAN Access Code and Serial Number

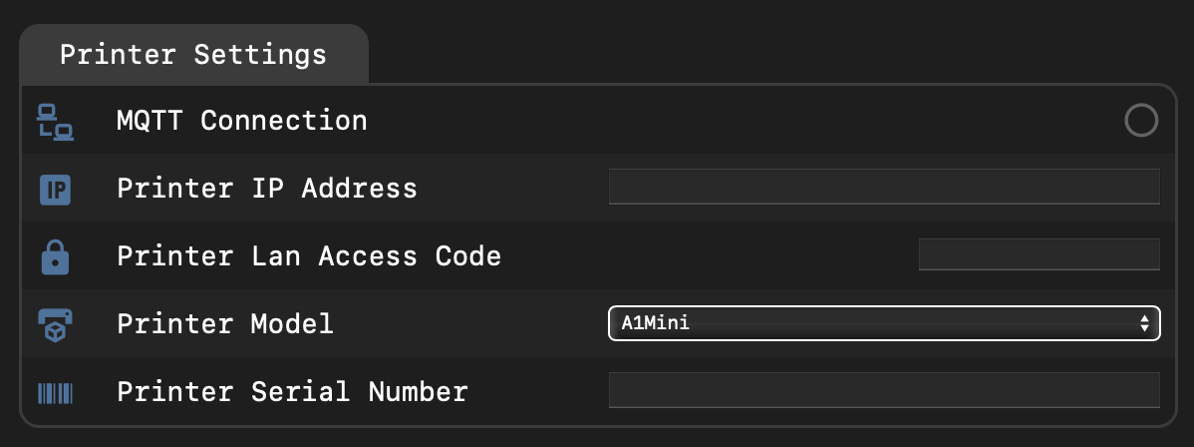
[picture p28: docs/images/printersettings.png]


{: .note-title }
> Security
>
> `Printer IP`, `Lan Access Code` and `Serial Number` are stored locally on the microcontroller and never leave the device. Do not share your Acces Code with anyone.

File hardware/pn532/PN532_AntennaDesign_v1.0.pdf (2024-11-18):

# Changes PN532_Breakout board

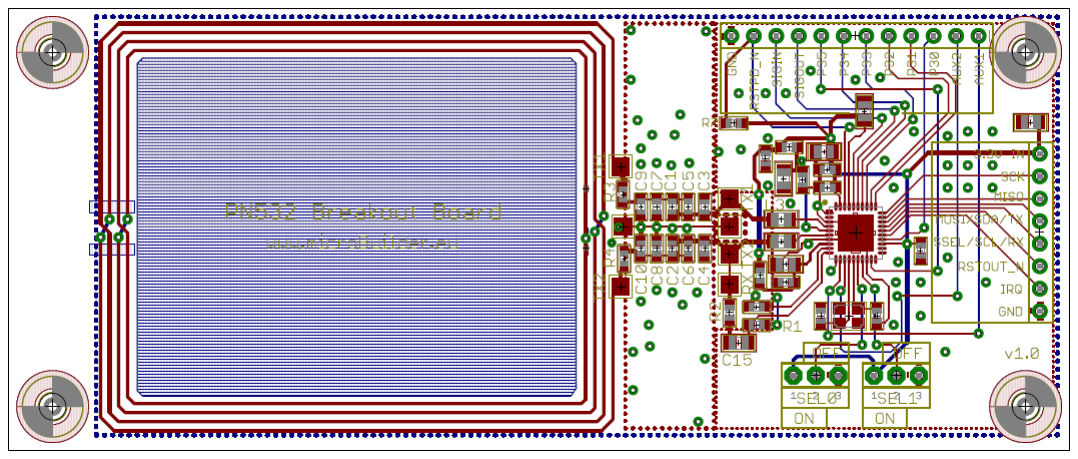
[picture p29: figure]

Document: | Changes PN532_Breakout board
Department / Faculty : | TechnoCentrum - Radboud University Nijmegen
Contact: | René Habraken
Date: | 17 May 2011
Doc. Version: | 1.0

## Contents

### 1. Introduction

The PN532_Breakout board contains the PN532 chip of NXP Semiconductors for contactless communication. Together with the pcb-antenna it forms an NFC reader for the ISO 14443 standard. To increase the communication range of the PN532_Breakout board the antenna had to be matched to the PN532 chip. Apart from that the signal coming back from the tag and picked up by the antenna had to be optimized. This document describes the measurements and improvements done on the PN532_Breakout board at the Techno Centrum of the Radboud University in Nijmegen.

Because the PN532 chip delivers a square wave of 13.56MHz a low-pass filter (see Figure ) follows the output pins to end-up with a clean sine wave. In the reader–antenna setup below, most power is send when the impedance of the antenna is matched to the impedance of the chip. The capacitors C1,2 transform the impedance of the antenna to a 50Ω impedance at the resonance frequency (13.56MHz in this case). In order to receive the modulated signal from the tag the quality-factor (Q-factor) of the antenna should not be too high. This factor is an indication how well the antenna performs at its resonance frequency. Normally it should be as high as possible because most power is radiated in that case. However, it acts like a filter and if the Q-factor is above 30 it cuts off the desired frequencies send back by the tag. Resistors RQ reduce the Q-factor to the optimal value.

The measurements described in this document are done with the Agilent 4396B Network/Spectrum analyzer. Together with the Agilent 16093A option it can be used to measure the impedance of an antenna and the other parameters that are necessary for the calculations. Besides the network analyzer a standard scope is used (Tektronix TDS3052) to measure the return signal from the antenna. Together with a low capacitance probe (Tektronix P6243 1MHz- 1GHz, <1pF) the desired signals could be measured with the necessary precision.

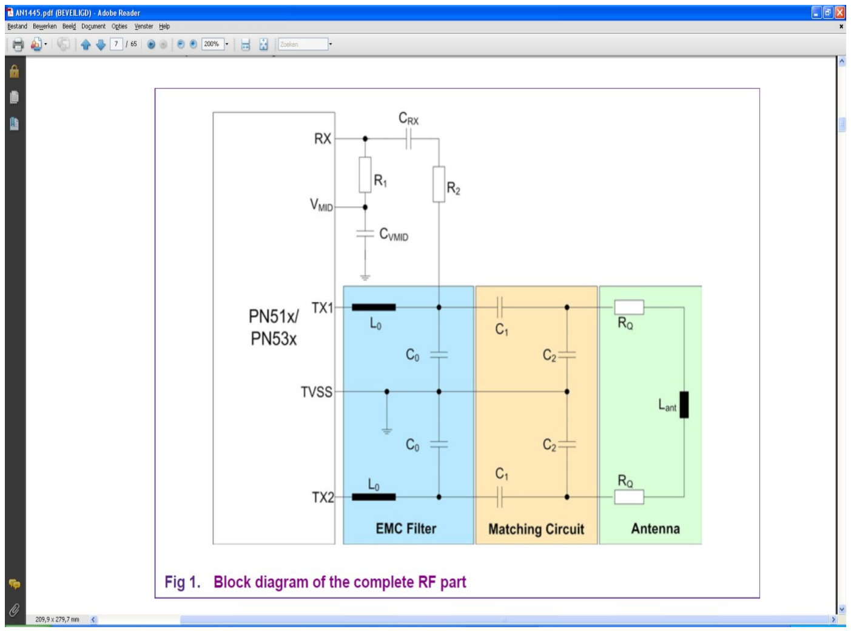
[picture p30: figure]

Figure : Reader-antenna setup

### 2. Matching components

### 2.1 Measurements

To tune the antenna and calculate the correct values for the components the following document is used: NFC Transmission Module Antenna and RF Design Guide (AN144511) from NXP Semiconductors. This document describes in detail the properties of the antenna for the PN532 chip and it comes with a spreadsheet to calculate the correct matching components. It can be found using the following link: http://www.nxp.com/#/page/content=[f=/dynamic/applicationnotes/all/data.xml]

As a start the inductance of the antenna is calculated and it results in an inductance of 1.91μH. Later on this value is confirmed by measurements done with the Agilent network analyzer. To calculate the components of the matching circuit two equivalent antenna circuits must be used. The value for resistor RQ (see: Figure ) follows from figure 2. The values of capacitors C1,2 can be calculated from the parallel circuit of figure 3

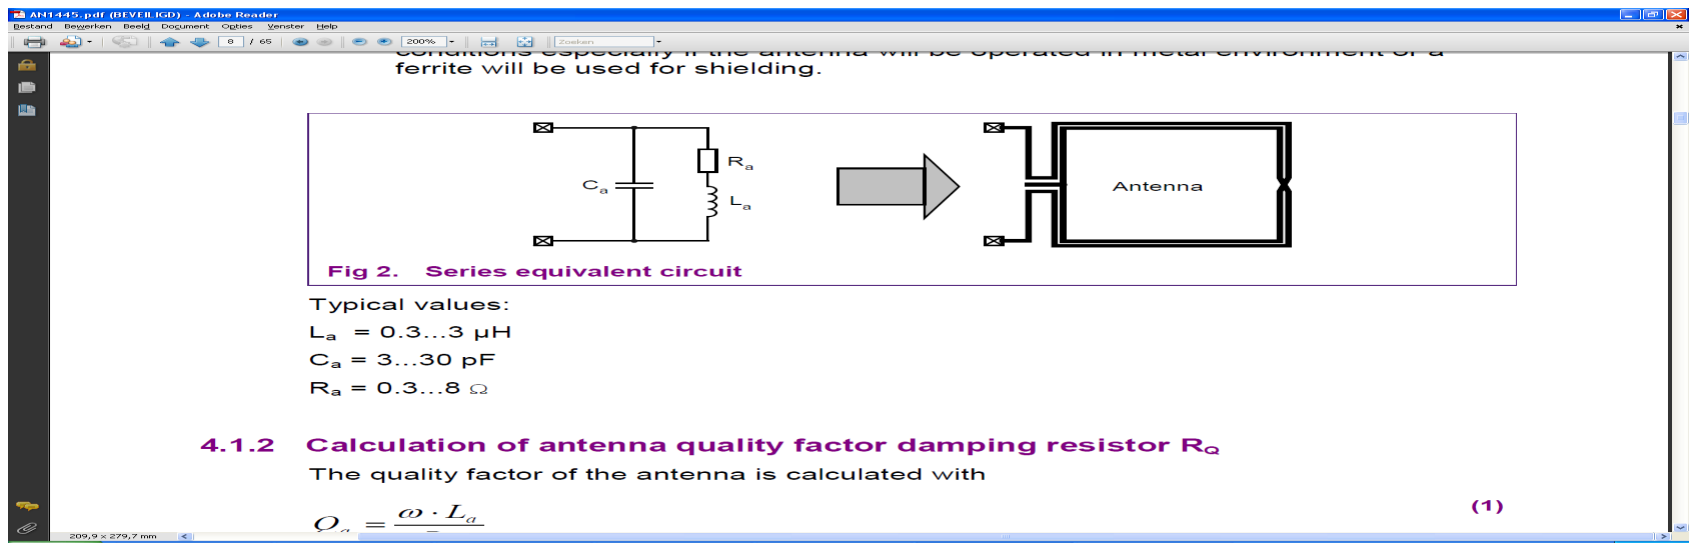
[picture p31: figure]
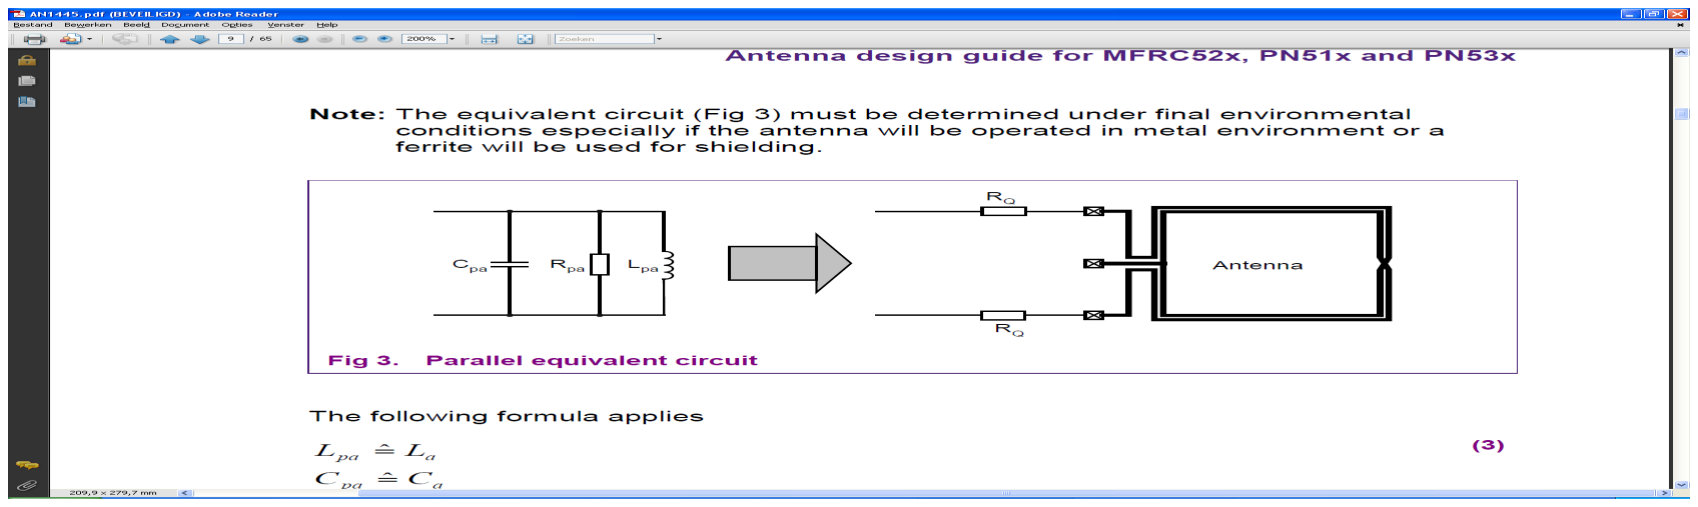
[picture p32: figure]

Figure : Series antenna circuit | Figure : Parallel antenna circuit

The measurements of the parameters that are necessary to obtain the component values are listed below.
Parameter | Value | Comment
La | 1.83μH | Series inductance
Ra | 1.42Ω | Series resistance
Rpa | 19.9kΩ | Resistance at fres
fres | 38.3MHz | Resonance frequency antenna
Table : Measurements without RQ
To reduce the Q-factor of the antenna two resistors (RQ) of 1.5Ω are placed in series with the antenna. The calculation of the final values for the matching network must be done after a second
measurement with the series resistors in place.
Parameter | Value | Comment
Lpa | 1.90μH | Series inductance
Ra | 4.46Ω | Series resistance
Rpa | 18.4kΩ | Resistance at fres
fres | 37.3MHz | Resonance frequency antenna
Table : Measurements with RQ
Using the parameters from Table 2 the component values for the matching circuit are: C0=220pF, C1=24pF and C2=103pF. (see: Figure : Reader-antenna setup). The closest available values in the market for the capacitors are 220pF, 22pF and 100pF respectively. These components should result in a matched antenna–reader system with a resonance frequency of 13.56MHz and a Q-factor of 30 or less. For the results see paragraph: Results Results.

### 2.2 Return signal from antenna

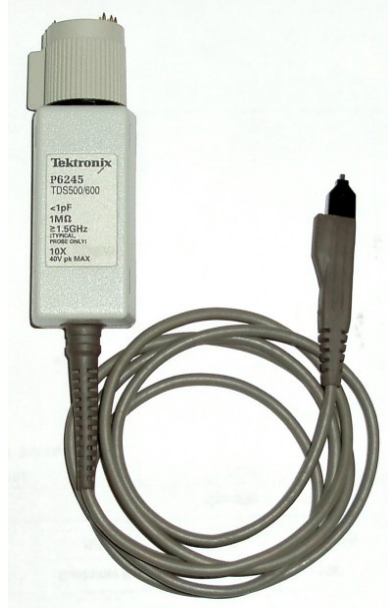
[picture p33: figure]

The chip is protected from an over voltage by means of a voltage divider (see: Figure : Reader-antenna setup). To calculate the necessary ratio the voltage on the antenna is measured with a low capacitance probe. If you use a regular probe the antenna is detuned and the results are not correct. The reason for this effect is mainly because of the added capacitance of the probe. For this purpose the P6243 probe of Tektronix is used with a capacitance of <1pF.

Figure : Tektronix probe
Several other probes are tried including a high frequency probe of Agilent that must be used together with the network analyzer. Also a standard scope probe is used with an added resistor to the probe tip to reduce the capacitance. However these measurements showed to be less stable and straightforward as was the case with the Tektronix probe.

Because the antenna generates an electromagnetic (EM) field continuously, it is important to keep a short connection to ground i.e. close to the point where the measurement is done. If the ground wire is in the EM-field a voltage is induced in the probe and the measurement becomes unreliable. Special care is taken to reduce this problem to a minimum.

According to the datasheet of the PN321 chip the maximum allowed voltage on the receive pin of the chip is AVDD +1V. The (analog) supply AVDD is 3.3V and this results in a maximum allowed voltage of 4.3V on pin RX (see: Figure : Reader-antenna setup). This must be valid for an RF-field that is switched on continuously and for a chip in communication mode. If the antenna is detuned by a tag the voltage increases on pin RX. Also in this situation the voltage may not exceed the 4.3V. To get to an optimal result an iterative process is used to reach the largest communication distance without exceeding the allowed voltage. Resistor R2 is varied from 1kΩ to 2k2Ω and the communication distance is measured. Unfortunately this did not increase the communication distance significantly. A difference from 74mm (2k2) to 77 (1k7) was found varying the resistor. In contrary to the specification with an Urx higher than 4.01V the sine clips and is deformed. Values for R2 of 1k5 or less influence the reading range negatively and should be prevented.

R2 [Ω] | Uc0 [V] | Urx [V] | Urx [V] (detuned)

Com. dist.
[mm]

2 nd | 1k | 4.60 | 2.97 | 4.05 | 75
3 rd | 1k5 | 4.75 | 2.68 | 4.01 | 75
4 th | 1k7 | 4.88 | 2.59 | 3.98 | 77
5 th | 2k | 4.90 | 2.55 | 3.71 | 75
1 st | 2k2 | 4.92 | 2.47 | 3.50 | 74
Table : Determination R2, resistor divider

### 2.3 Results

The most power is sent by the antenna when the input impedance is matched to 50Ω and the reactance is 0Ω at the resonance frequency. This is measured with the Agilent 4396B impedance analyzer and the reflexion coefficients from the antenna are displayed in a so-called Smith chart. Optimal power transfer takes place when the line goes through the middle of the chart at a frequency of 13.56MHz.

With the components, mentioned in the previous paragraphs, in place the following results are measured. At the resonance frequency of 13.56MHz the impedance is 41.8Ω and the reactance is 25.2Ω. (see: Figure Figure ) The reactance is too high for an optimal power transfer, however, if the antenna is detuned by a tag the Smith chart shifts to Figure . The impedance is 56.4Ω at 13.56MHz with a reactance of 1.5Ω.

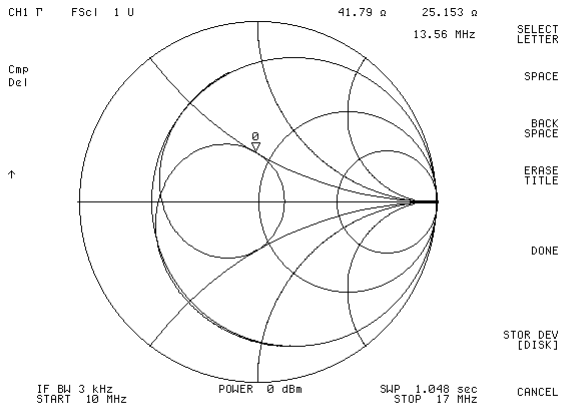
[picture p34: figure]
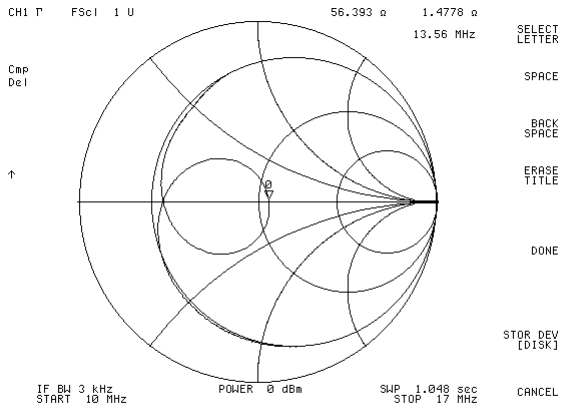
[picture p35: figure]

Figure : Antenna impedance | Figure : Antenna impedance, detuned by tag

Figures 7 and 8 are just for a reference to the original antenna design. Even though the matching is far from optimal communication is still possible but only if the card is practically laying on the antenna.

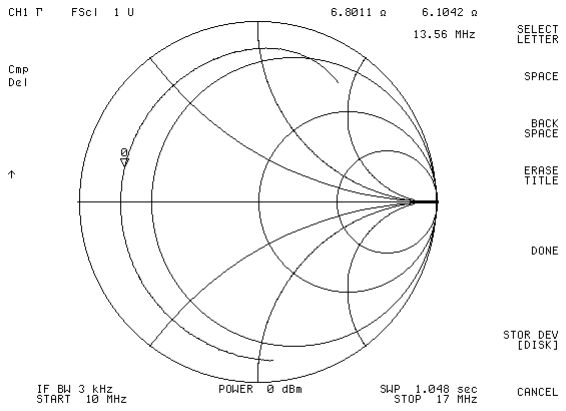
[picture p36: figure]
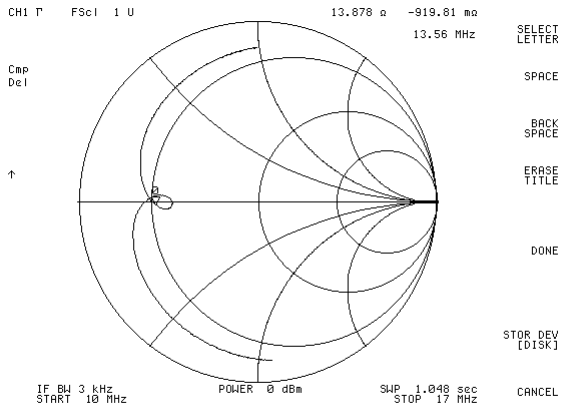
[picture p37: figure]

Figure : Original antenna impedance | Figure : Original antenna impedance, detuned by tag

### 3. Conclusion

Figure : Tag

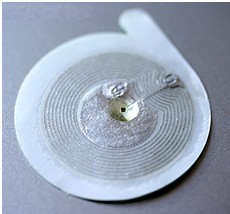
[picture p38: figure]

Several components from the original design are changed to optimize the complete reader-antenna system. This results in a doubled communication range for a standard card and even a factor of 3.8 for a small tag (Figure ).The biggest increase in communication distance results from the change of capacitors C7,8 and resistors R3,4 (see: Figure : Board schematic). The difference in communication range because of the other changed components is not significant and is just a fine tuning of the system. The capacitors C7,8 provide a better matching to the chip in order to deliver more power from the reader to the antenna. (Less power is reflected back.) The addition of R3,4 decreases the quality-factor of the antenna. This results in a better reception of the modulated signal coming from the tag.

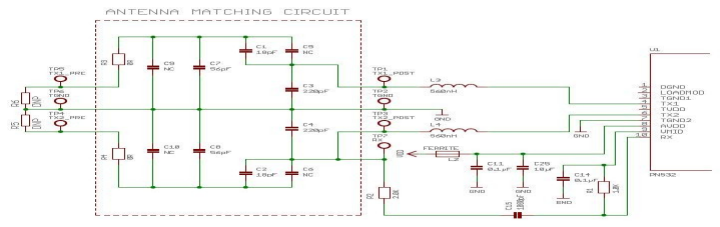
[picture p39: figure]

Figure : Board schematic V1.0
An overview of the changed components from the initial version 1.0 to version 1.5 is listed in Table .
Components | Version 1.0 | Version 1.5
C1 [pF] | 18 | 22
C2 [pF] | 18 | 22
C7 [pF] | 56 | 100
C8 [pF] | 56 | 100
R2 [Ω] | 2k | 1.7k
R3 [Ω] | 0 | 1.5
R4 [Ω] | 0 | 1.5
Table : Changed components
A comparison in range and parameters between the two versions can be found below.
Results | Version 1.0 | Version 1.5

Com. Range | Card | 38[mm] | 77[mm]
| Tag | 13[mm] | 50[mm]
Max. field strength | | <1[A/m] | 1[A/m]>max. field<1.5[A/m]
Q-factor antenna | | Unknown | 20.40
Table : Final results

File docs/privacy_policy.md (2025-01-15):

---
title: Privacy Policy
layout: default
permalink: /privacy_policy
---

# Privacy Policy

**Effective Date:** Jan 14, 2025

Thank you for using OpenSpool! Your privacy is important to us. This Privacy Policy explains how we handle your information when you use our software.

## Data Collection
OpenSpool does not collect, store, or process any personal data or identifiable information from its users. The software operates entirely on your device and does not transmit data to external servers or third-party services.

## Data Usage
Since we do not collect or store any data, there is no user data to use, analyze, or share.

## Third-Party Services
If the software integrates with third-party services (e.g., APIs or plugins), any data handled by those services is subject to their respective privacy policies. We encourage you to review the privacy policies of any third-party services you choose to use with OpenSpool.

## Open Source Nature
OpenSpool is open source, meaning its source code is publicly available and can be reviewed, modified, or contributed to by anyone. This transparency ensures that you can verify how the software operates and confirm that it does not collect or store data.

## User Responsibility
As an open-source project, OpenSpool provides tools that run locally on your device. You are responsible for maintaining the security and privacy of your device and any data you choose to process with the software.

## Changes to This Privacy Policy
We reserve the right to update this Privacy Policy to reflect changes in the software or legal requirements. Any updates will be clearly posted in the project's repository or official website.

## Contact Us
If you have any questions or concerns about this Privacy Policy, feel free to contact us:
- [https://github.com/spuder/openspool]

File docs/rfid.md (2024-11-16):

---
layout: default
title: RFID Tags
nav_order: 2
---

<p align=center>
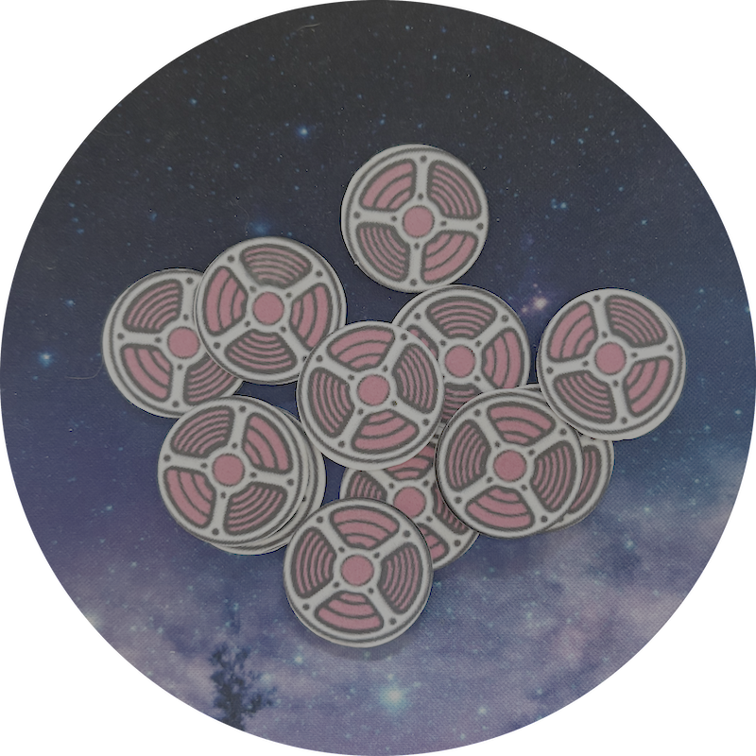
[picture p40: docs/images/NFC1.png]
    
</p>

# RFID Tags

At the heart of OpenSpool are the `NFC/RFID` tags that you will place on every spool you want to automate. The OpenSpool hardware works with a wide variety of High-Frequency tags (13.56Mhz)

{: .note-title }
> NFC vs RFID
> 
> `NFC` is to `RFID` like `Bluetooth` is to `Radio`.  
> All NFC Tags are RFID tags, but not all RFID tags are NFC tags. 

### Tag Selection

Purchase NTAG 215 or 216

[NTAG 215 - Amazon](https://a.co/d/5ojDUNk)  
[NTAG 215 - Aliexpress](https://www.aliexpress.us/item/3256806144939092.html)  

| Tag | Bytes | Supported |  
| --- | --- | --- |
| NTAG 213 | 144 bytes | ❌ | 
| NTAG 215 | 504 bytes | ✅ |  
| NTAG 216 | 888 bytes | ✅ | 

## Protocol

OpenSpool NFC tags create an NDEF message on the tag. NDEF messages are human readable and can be viewed from your phone.

[iPhone - NFC Tools app](https://apps.apple.com/us/app/nfc-tools/id1252962749)  
[Android - NFC Tools app](https://www.google.com/url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)  

The NDEF message is a single record of type `application/json`

```json
{
    "protocol": "openspool",
    "version": "1.0",
    "type": "PLA",
    "color_hex": "FFAABB",
    "brand": "Generic",
    "min_temp": "220",
    "max_temp": "240"
}
```

`color_hex` = 6 digit hex color. For best results it needs to be one of [the predefined values](https://github.com/bambulab/BambuStudio/blob/733531b1c68e755da991c9503a09c2206c2e4984/src/slic3r/GUI/AMSMaterialsSetting.cpp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) in bambu slicer.   
`type` = One of [the predfined values](https://github.com/bambulab/BambuStudio/blob/733531b1c68e755da991c9503a09c2206c2e4984/src/libslic3r/PrintConfig.cpp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) in bambu slicer.  
`brand` = One of `Generic`, `Overture` `PolyLite`, `eSun`, `PolyTerra`. The full list can be found [in bambuslicer](https://github.com/bambulab/BambuStudio/tree/master/resources/profiles/BBL/filament). If a filament is defined that is not in this list, it will be assumed to be `Generic`.  

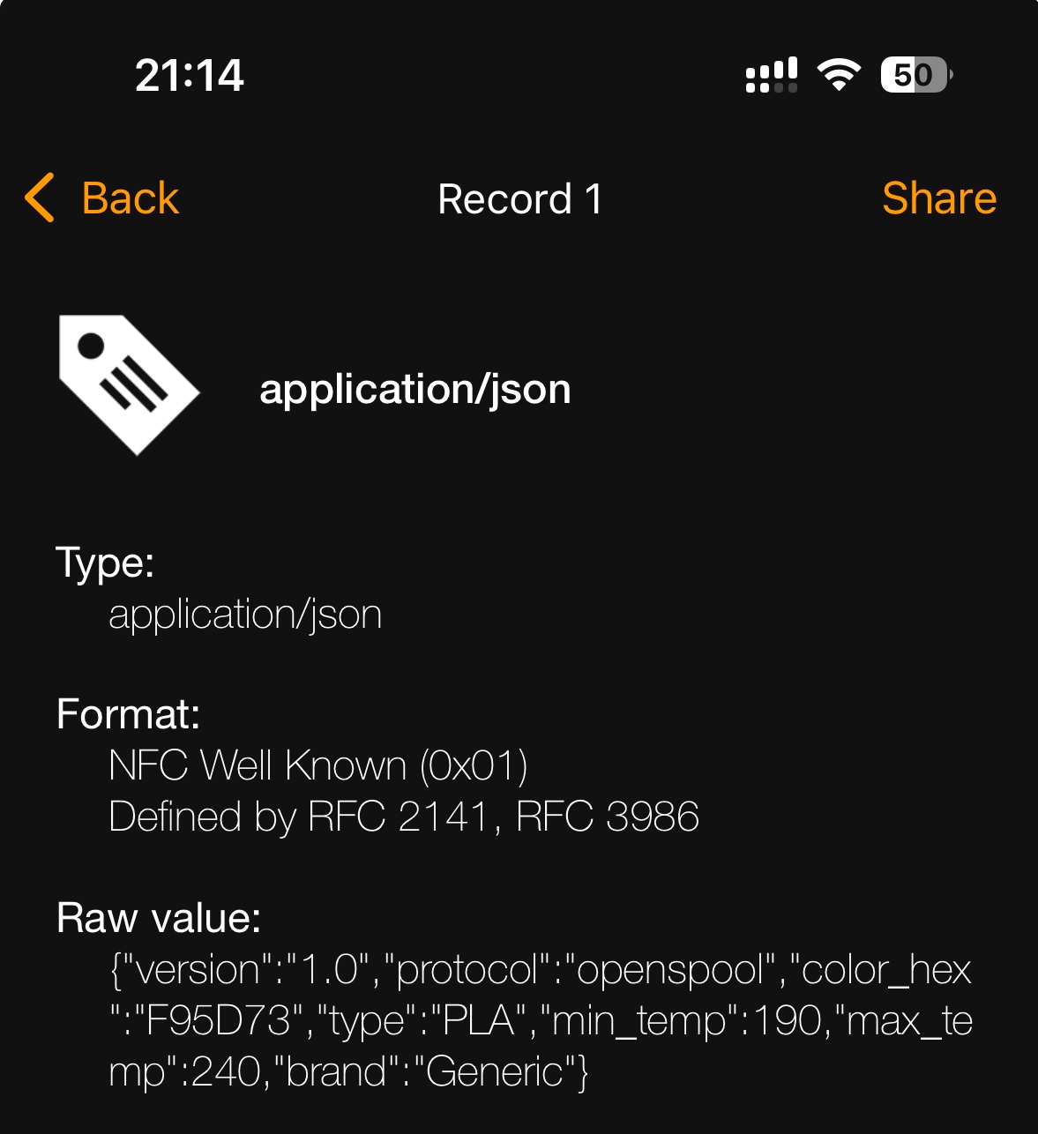
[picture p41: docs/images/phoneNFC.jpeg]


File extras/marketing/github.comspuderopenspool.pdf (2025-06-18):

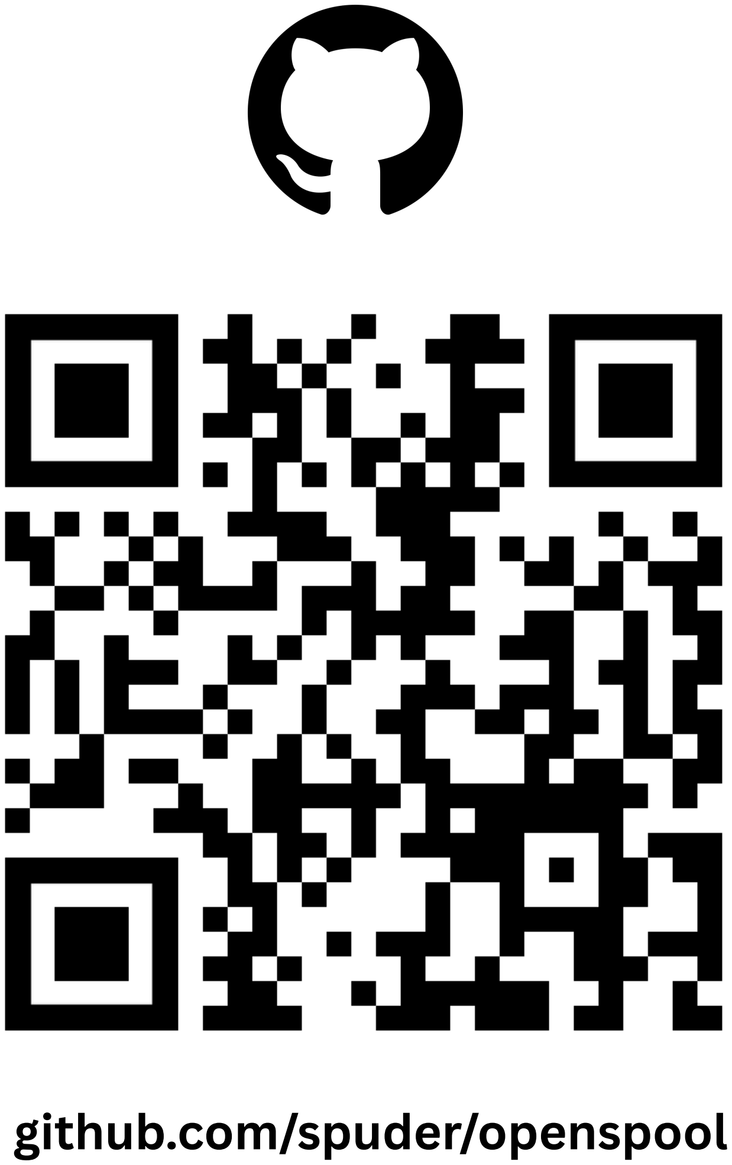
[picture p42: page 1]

github.com/spuder/openspool

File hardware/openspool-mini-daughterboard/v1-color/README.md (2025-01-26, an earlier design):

# V1 has a defect

The 3rd led is shorted because the ground pad got mistakenly filled with the signal wire

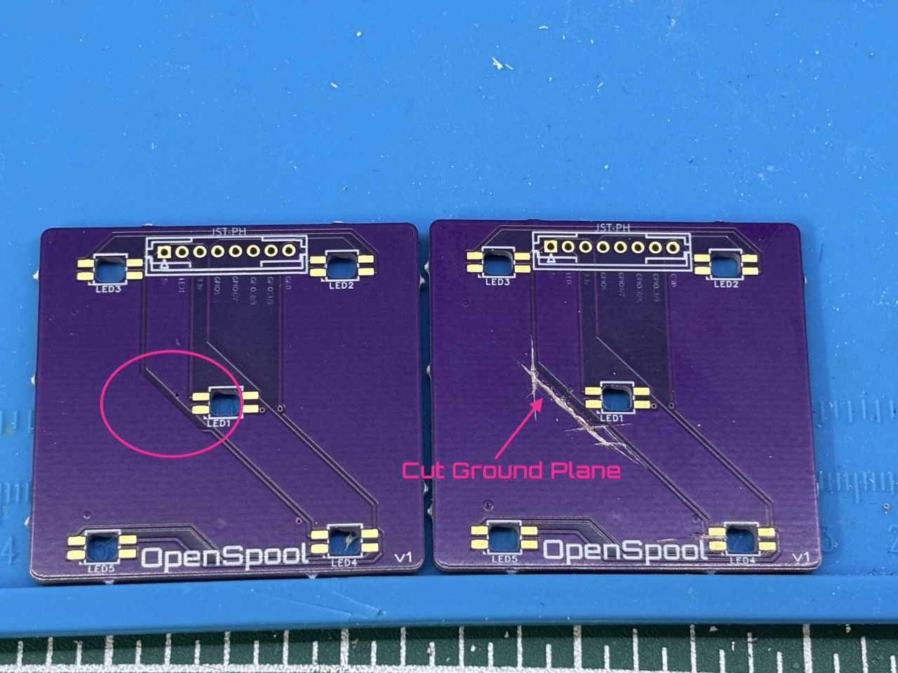
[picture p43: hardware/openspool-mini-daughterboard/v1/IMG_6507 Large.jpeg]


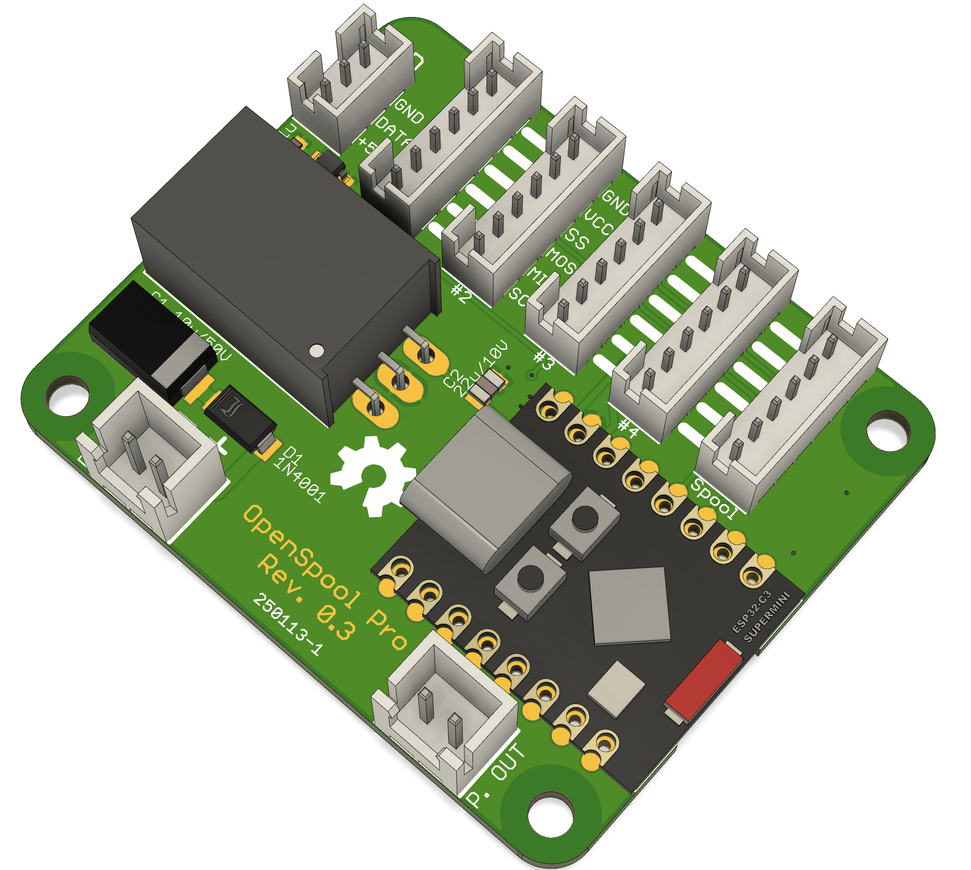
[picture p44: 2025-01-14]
hardware/openspool-pro/v0.3/Screenshot_2025-01-13_at_10.35.16_PM.png

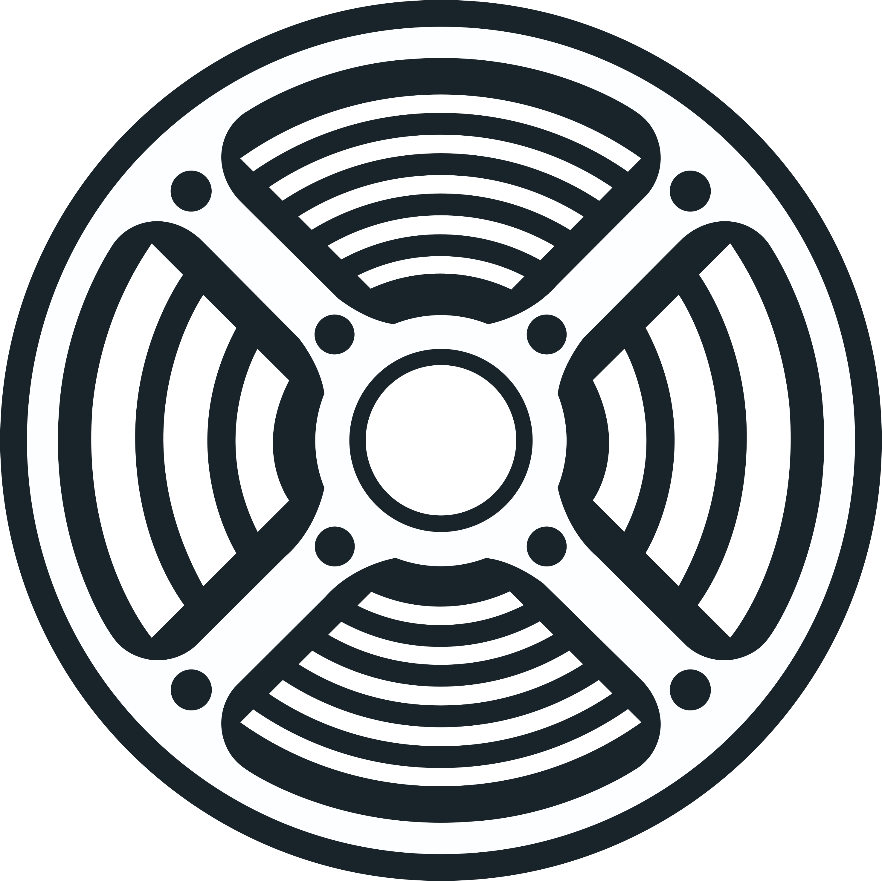
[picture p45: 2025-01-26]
images/openspool-transparent.png

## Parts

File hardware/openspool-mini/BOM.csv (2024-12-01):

Part Name | Quantity | Description | Link 1 | Link 2
Wemos D1 Mini S3 | 1 | ESP32-S3 Development Board | N/A | aliexpress.us/item/3256805262904443.html
PN532 Small | 1 | NFC/RFID Reader Module Compact Version | amazon.com (AMZ: 4eoBz8s) | aliexpress.us/item/3256805787598774.html
NTAG 215/216 | 1+ | 13.56Mhz NFC Tags >500 bytes | amazon.com (AMZ: 4epJzpO) | N/A
WS2812B LED | 1 | Addressable RGB LED | amazon.com (AMZ: 40FFOt5) | N/A
2.54mm Headers | 1 set | Pin Headers for Connections | amazon.com (AMZ: 4en6138) | N/A
Logic Level Converter | 1 | 3.3v to 5v Bi-directional Converter | amazon.com (AMZ: 3UMfMkp) | N/A
Jumper Wires F-F | 8 | Female to Female Jumper Cables | amazon.com (AMZ: 3AMwRDM) | N/A

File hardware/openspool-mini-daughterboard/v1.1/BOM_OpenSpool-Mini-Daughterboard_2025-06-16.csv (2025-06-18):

ID | Name | Designator | Footprint | Quantity | Manufacturer Part | Manufacturer | Supplier | Supplier Part | Price
1 | B8B-PH-K-S-(LF)(SN) | U5 | CONN-TH_B8B-PH-K-S-LF-SN | 1 | B8B-PH-K-S(LF)(SN) | JST | LCSC | C157974 | 0.081
2 | XL-6028RGBW-WS2812B | LED1,LED2,LED3,LED4,LED5 | LED-SMD_4P_XL-6028RGBW-WS2812B | 5 | XL-6028RGBW-WS2812B | XINGLIGHT(成兴光) | LCSC | C42163197 | 0.085
3 | Button-SMD-4x4x1.5 | B1,B2,B3,B4 | SW-SMD_4P-L5.2-W5.2-P3.70-LS6.5 | 4 | 4*4*1.5Copper head,260G, 0.25mm, | BBJ | LCSC | C71830

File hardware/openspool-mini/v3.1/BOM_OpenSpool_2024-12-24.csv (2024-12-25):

ID | Name | Designator | Footprint | Quantity | Manufacturer Part | Manufacturer | Supplier | Supplier Part | Price
1 | N-MOS+DIODBSS138(SOT23-3) | BSS138 | SOT23 | 1
2 | 10k | R1,R2 | R1206 | 2

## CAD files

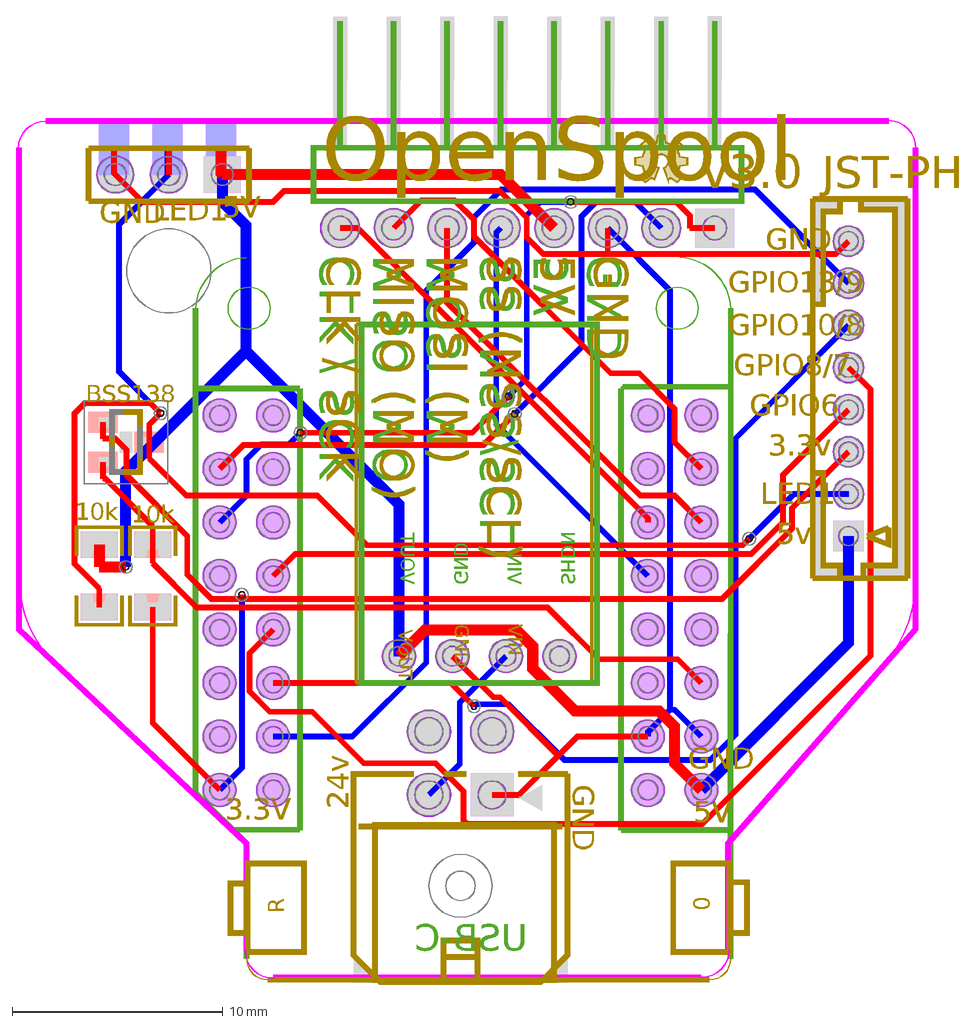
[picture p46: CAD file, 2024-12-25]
hardware/openspool-mini/v3.1/PCB_OpenSpool_2024-12-24.dxf
CLK / SCK
MISO (MO)
MOSI (M)
SS (NSS/SCL)
5V
GND
USB-C
LED1
OpenSpool
v3.0
3.3V
VOUT
VIN
5v
3.3v
GPIO6
GPIO8/7
GPIO10/8
GPIO13/9
JST-PH
24v
R
0
BSS138
SHDN
10k

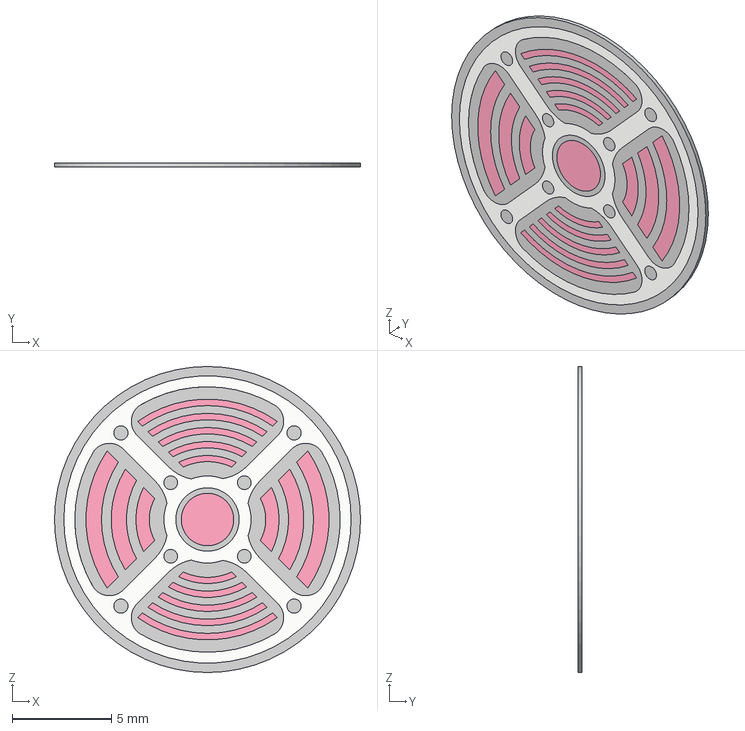
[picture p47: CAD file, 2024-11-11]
images/Logo v11.step
15.4 x 0.2 x 15.4 mm

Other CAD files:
hardware/openspool-pro/v0.3/OpenSpool Pro - v0.3 - 250113.f3d

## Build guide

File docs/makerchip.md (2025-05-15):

---
title: Maker Chip
layout: default
permalink: /makerchip
nav_exclude: true
---

## 🎉 Congratulations! 🎊 

### 🌟 You have acquired an exclusive OpenSpool Maker Chip! 🌟 

<div style="display: flex; justify-content: center; align-items: center;">
  <div class="tenor-gif-embed" data-postid="14441126" data-share-method="host" data-aspect-ratio="0.796875" data-width="300px"><a href="https://tenor.com/view/awesome-you-are-awesome-gif-14441126">Awesome You Are Awesome GIF</a>from <a href="https://tenor.com/search/awesome-gifs">Awesome GIFs</a></div>
</div>
<script type="text/javascript" async src="https://tenor.com/embed.js"></script>

#### 🏆 Welcome to the OpenSpool Maker community! 🚀

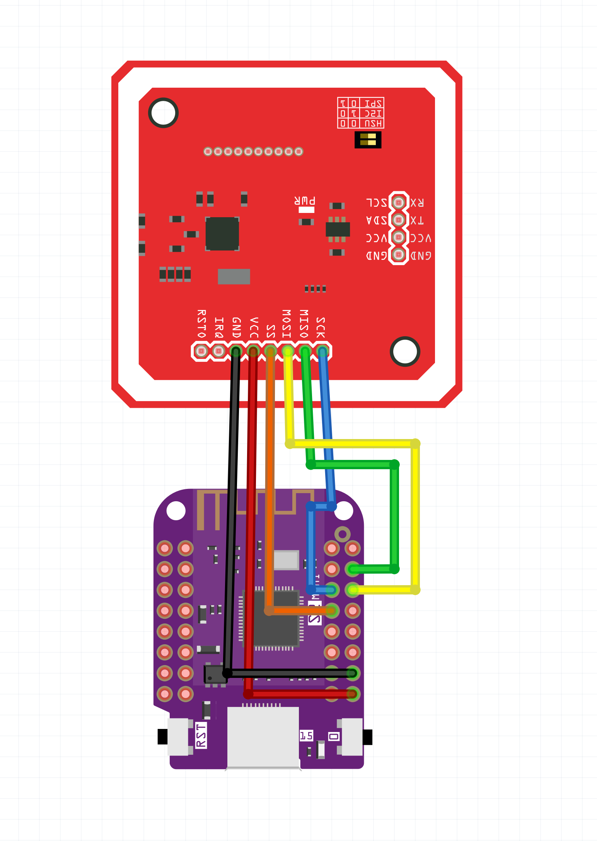
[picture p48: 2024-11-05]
images/WiringDiagram2.png

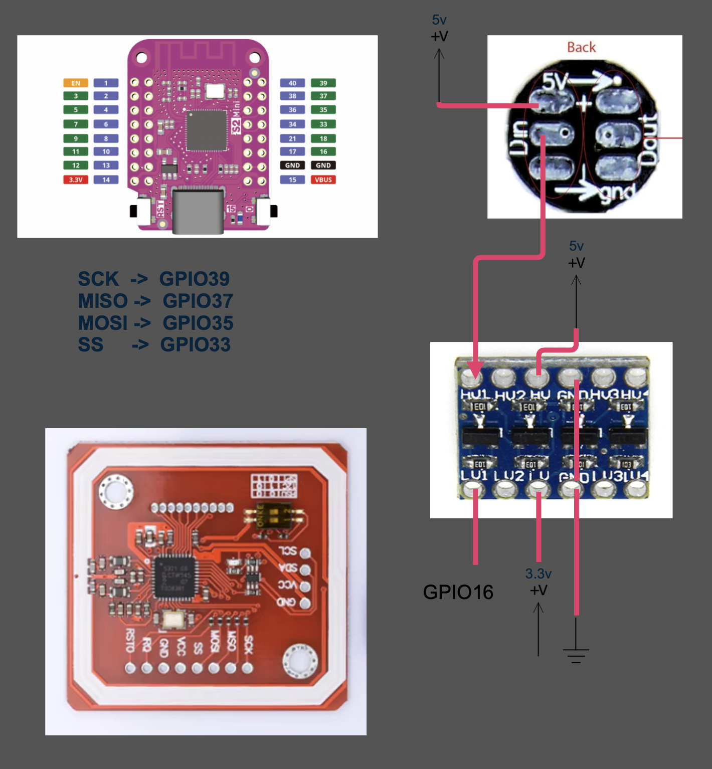
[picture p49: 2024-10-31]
images/WiringDiagram1.png

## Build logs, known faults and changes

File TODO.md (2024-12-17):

- [ ] Polylite manufacture codes
- [ ] Setup static page with improv-serial
    See dutch developer site for example
    ```
    <esp-web-install-button manifest="https://raw.githubusercontent.com/DutchDevelop/BLLEDController/main/firmware/manifest.json" install-supported=""></esp-web-install-button>
    ```

- [x] OpenSpool listed on improv website https://www.improv-wifi.com
- [x] Setup static tag validator page
- [x] Fix error when writing tags, worked in 0.1.41, but broken in master
- [x] Add BambuRFID creator button
- [x] Add openspool-xxxx.local creator button
- [x] Fix wifi blinking blue
- [x] Enable OTA updates on D1 mini
- [x] Add breathing animation
- [x] Add rainbow breathing
- [ ] Add magenta blinking
- [ ] Increase all 512 json docs to 1024 in prep for OpenTag standard
- [ ] MQTT reboots afeter x minutes if not connected
- [x] Add esp32-s3 support to manifest.json

# Hardware

- [x] Add 3mm offset to led light pipe
- [x] Print final version of mini
- [ ] Upload mini to MakerWorld so I start earning points
- [x] Make PCB v2 for mini
- [ ] Make PCB for Pro/AMS
- [ ] Test aluminum Tape
- [ ] Test RFID antennas

# Social

- [ ] Share on tiktok
- [ ] Share RFID Tag video
- [ ] Send 10 units to youtubers
- [ ] Host on etsy shop
- [ ] Host on tindie.com

# Pipeline
- [ ] Create releases with .bin files so people can install old versions

# Bug
- [x] Fix app crashing when writing tags
  - 0.1.36 ✅ (with and without mqtt)
    note: it did take a couple of tries and the tag needed to be on the reader when pushing the write button
  - 0.1.42 ❌ broken because I started trying to pass object into script
  - Upgrade esp-web-tool to latest once this is fixed: https://github.com/esphome/esp-web-tools/issues/515#issuecomment-2525463852

# Features

- [ ] Add nominal diameter to protocol
- [ ] Add 'weight' data to nfc tag
- [ ] Read bambu tags
- [ ] Read creality tags
- [ ] Support simultanious RFID tags on pn532

# Misc
- [ ] Enable status LED on s3 boards when mqtt connected
- [ ] Bambu support
- [ ] Octoprint support
- [ ] Klipper support

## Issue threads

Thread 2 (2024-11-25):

AMS?

officiallymarky, 2024-11-25:
Does this have the ability to work with an AMS and different slots?
I'm wondering if this could be integrated to a system like the Python AMS.

spuder, 2024-11-25:
Prototype is currently in the works for AMS.

ser-attachments/assets/c3e97f24-3913-42aa-bcdb-ac4aa30701e8)

andysmithfal, 2024-11-25:
Interesting! I was imagining a separate unit to scan the material and select which AMS slot you're loading it into, but a fully integrated solution would be really tidy.

spuder, 2024-11-25:
The openspool mini is done but I have a few software bugs to finalize before I upload it to makerworld

koffienl, 2024-12-04:
Looks really promising. Just ordered the hardware parts. Can't wait for the AMS adapter :)

raihei, 2025-01-03:
Looks great.

A second/alternate solution came to my mind, which needs less hardware and installation in AMS:
Just 5 (touch) buttons on the mini to select, in which AMS slot (5th button for manual feeding) the spool will be put in. You can maybe even use only one button and press it multiple times to select the desired slot.

Workflow:
- Select desired slot by touching the corresponding button on the mini. -> LED confirmation (n flashes for the selected slot)
- Scan the spool -> LED will turn green and then pulse in a special color (e.g. yellow) until spool is installed and button is pressed again (or timeout after ~60-120 seconds)
- Put the spool into the AMS (or the manual feed)
- Press the corresponding button again to confirm, after AMS has finished loading -> LED confirmation
- Spool data will be transfered to the printer.

I don't have many experience with esphome, would that be even possible?

mytechguyri, 2025-01-08:
Would be great to develop something that works with Python and Hydra AMS as well.

koffienl, 2025-01-09:
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

I hope that this would only be an extra option. If I have to do all these manual steps I could just use the screen of my pandatouch.
I was in the understanding that for a AMS 2 readers would be enough, but looking at the render I would need 4?
The ESP should already be aware of which slot is being load based on the MQTT info.

This weekend my buddy and I will attempt to assemble the components for the AMS, excited to wait how it will turn out.

spuder, 2025-01-09:
> I was in the understanding that for a AMS 2 readers would be enough

Bambu only uses 2 readers. The 2 readers are enough if the spools are placed perfectly, as it can figure out which slot is being loaded.

The problem arrises when two adjacent spools both have an RFID tag next to the reader. Bambu does something clever and moves the motors until one of the RFID tags disappears. You may notice this occasionally when loading your AMS.

Since we don't have the ability to control the motors directly, using 4 readers is a compromise.
Also while the PN532 is physically capable of reading 2 tags at once, the esphome library doesn't support that yet.

raihei, 2025-01-09:
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

Ah, that makes perfect sense. I was already wondering, why you planned to use 4 readers.

koffienl, 2025-01-11:
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

Where can I find wiring schematics to build the AMS version with 4 readers?

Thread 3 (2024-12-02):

Brand field

mytechguyri, 2024-12-02:
I see the current specification says "brand = One of Generic, Overture PolyLite, eSun, PolyTerra. The full list can be found [in bambuslicer](https://github.com/bambulab/BambuStudio/tree/master/resources/profiles/BBL/filament). If a filament is defined that is not in this list, it will be assumed to be Generic"

Is there any way this can pass the brand defined in the tag regardless, instead of Generic, so that if the end user has a filament profile defined for that brand, Bambu Studio can match to it?.... i.e. I have a custom filament profile configured in Bambu Studio for Flashforge PETG   So if I load a filament of type PETG and brand Flashforge.... if that gets passed instead of "generic", it could select the correct filament profile?   Or is this a limitation of the Bambu firmware, and it not accepting anything but Generic, Overture, Polylike, eSun, and PolyTerra via the MQTT protocol?

spuder, 2024-12-02:
The brand gets mapped to an internal number that bambu printers expect in the mqtt message. For example Generic PLA has a code like GA99 but Bambu PLA is something like B398

So for now filament must be one of those predefined values so the codes can be looked up in a table.

You do bring up a good point about user defined fields. As of right now there isn't a way to sync openspool with any slicer. But if there were, being able to provide a specific filament would be useful.

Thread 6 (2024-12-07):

Both 5V and 3V are hooked up?

RobThree, 2024-12-07:
I'm confused. Why is **both** 3V and 5V hooked up to the ESP32-S3 in [your diagram](https://github.com/spuder/OpenSpool/blob/26bc6550290323e55f7e9be442d46adbeaa9df4e/images/OpenSpoolMiniWiringDiagram2.png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)?

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

Isn't it enough to hook up just 5V? It would save a levelshifter (or even a 4-levelshifter module that could be a single levelshifter module).

spuder, 2024-12-07:
The level shifter is only for the data line of the led. Since the LED needs 5v logic but the esp32 GPIOs only provide 3.3v some LEDS are unreliable with the lower voltage.

On the PCB version, the 4 line shifter has been replaced with a single transistor and 2 resistors.
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

RobThree, 2024-12-07:
> The level shifter is only for the data line of the led. Since the LED needs 5v logic but the esp32 GPIOs only provide 3.3v some LEDS are unreliable with the lower voltage.

I wasn't asking what the levelshifter is for. In the diagram you're hooking up **both** 5V (bottom right) and 3V (bottom left) to the Wemos D1, See the arrows. That doesn't make sense. And _that_ makes the "second" levelshifter redundant.

RobThree, 2024-12-07:
Wait, wait, wait... I'm a dumbass....

You're correct. You need to get the 3V from somewhere. It's coming FROM the Wemos TO (feed) the levelshifter....

Jeez. My bad.

spuder, 2024-12-07:
The quad level shifter is overkill.
The single level shifters I found on amazon were actually more expensive than the quads so I linked the cheaper versions.

Here is the schematic I'm using. It seems to work, but if it can be improved I'll gladly change it.

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

Closed 2024-12-07.

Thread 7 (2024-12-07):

Integrate with Bambu Farm - Track weight of Spool

lcava000, 2024-12-07:
It would be nice to integrate Open Spool with the Bambu Farm solution (https://github.com/TFyre/bambu-farm)

In addition to this, I find it very convenient to also manage how many grams of filament remain per spool in Open mode.

If you need a hand, or for the assembly of kits for Italy I am here! Thanks for your fantastic work

spuder, 2024-12-07:
Thanks for the link. I've not heard of Bambu-farm before.

Several people have asked about keeping track of remaining filament. The actual implementation requires some research (for example should metadata be stored on the tag or in a database?, is the slicer or the printer the source of truth for remaining grams?). These questions will be evaluated and this feature will be added to the backlog.

Everything is growing quite quickly. I'll keep you in mind for growing internationally. Thank you.

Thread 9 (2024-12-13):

support for spoolman

thijstriemstra, 2024-12-13:
would love to use this with my spoolman-powered printers.

I'm ordering parts and hopefully be able to use it in 2025.. 😀

thijstriemstra, 2024-12-13:
see https://www.printables.com/model/798929-elechouse-pn532-v3-nfc-holder-for-voron-for-spoolm for some useful info and software utilities

spuder, 2024-12-13:
Thanks for sharing! I'll look into how they are doing it.

cbrherms, 2024-12-16:
It could also be useful if an adding could be made for qr code scanning, for those of us who print labels?

alessiobrendt, 2025-03-31:
news for this request?

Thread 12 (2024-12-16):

FR: Spool SN field

GunbleR, 2024-12-16:
Havent tried yet, may be usefull to add optional serial number to tag to differanciate between old and new simmilar spools.
Mainly for spool managers if they decide to implement support for it

spuder, 2024-12-16:
Thanks for the idea.

As I don't have much experience with spool-man or any other databases, what might this look like?

Is a serial number unique per spool or unique per rfid tag?

The tags already have a UID that could be used.

AA-BB-CC-DD (mifare classic)
AA-BB-CC-DD-EE-FF (ultralight/NTAG)

bofh69, 2024-12-18:
In Spoolman you create a filament and then from the filament you can create one or more spools. Each filament and each spool get their own ID (just an integer right now). When you use Spoolman with OctoPrint or Klipper & Moonraker you need to tell them which spool is in use by using Spoolman's spool ID. They then use it to report the filament usage to Spoolman.

Spoolman has a REST API that can do almost everything the web interface can do. You can configure Spoolman with custom fields for both its filament and spool records as needed.

With nfc2klipper, I first create new spools in Spoolman, then create the tags from Spoolman's data. The tags only contain the filament and spool IDs. The filament ID is used in my gcode to verify the right filament is used and ask me to change spool if the wrong filament is loaded (thus I can change to new spools with the same material and the verification still passes).

If you create the tags first, you can lookup the filament id in Spoolman (or create it if missing with the data from the tag. You would need to find the vendor/manufacturer too for that), then create a spool and there use a custom field for the UID.

You can't search in Spoolman via custom fields, but you can get all spools matching a certain filament name, material, vendor/manufacturer, or simply get all spools and then search for it in that way.

thijstriemstra, 2025-02-04:
Duplicate of #9

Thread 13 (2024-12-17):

3DFilamentProfiles.com as source

domwrap, 2024-12-17:
I thought I found somewhere the data feed you were using for the source input to choose brand/filament but now can't find it.

Would love to see integration from https://3dfilamentprofiles.com/ which has profiles for most filaments (and is where a lot of use to print QR codes for filament storage and organization) so could be used to populate the options on the tag config screen. Even if Bambu doesn't currently recognize or have profiles for many of them, this could at least be used as the source data to write the tags, and when reading the tag and updating the Bambu printer re-map it at that stage if necessary.

Absolutely love this project, following along closely and will probably be trying to build a kit in the new year. Kudos. 👍

spuder, 2024-12-18:
Thanks for sharing https://3dfilamentprofiles.com/. This is a great resource. People have asked me if there is a centralized location for profiles and this likely is the best location.

As far as pulling this resource automatically into openspool it might be a bit tricky as the esp32 needs a significant amount of PSRAM to establish https connections. An esp32-s3 should be able to do it, but an esp32-s2 likely won't.

There is also the issue that bambu uses an internal mapping of hex values and color names. If providing a value that isn't in their predefined list, it will show a blank color on the screen.

OpenSpool plans to expand out to printers outside of bambu, so for non bambu printers this likely will be very useful..

markcarroll, 2024-12-20:
Hi @spuder I am the developer of the 3D Filament Profiles site.  Let me know if you want to discuss best path to integration.

spuder, 2024-12-21:
👋 Hi @markcarroll Thanks for reaching out.

Yes I would be interested in discussing more how we could use your site as a single source of truth for filaments.
The esp32 has only 320k of ram so trying to parse the entire database might not be feasible.

Is there a way to export the "My Spools" feature to a json file or pull from a rest api?

I envision a text box on the openspool web interface where a user could enter an apikey or credential. It then downloads that users "My Spools" selection and adds them to a dropdown box they could choose from.

huizebruin, 2024-12-21:
Hello @spuder and @markcarroll .

Why not to make a combination of three.
i am no programmer, but i think this would bee the best to do, because the memory inside a esp32 isnt very big.

The openspool connected to spool manager and thisone gets also the data form 3dfilamentprofiles?
becase the spoolman has also a api https://donkie.github.io/Spoolman/#operation/
i dont no if this is possible but than you have a big and strong setup i think.

https://github.com/Donkie/Spoolman and https://github.com/Disane87/spoolman-homeassistant
thatone works also inside home assistant as a addon,and works with [OctoPrint](https://octoprint.org/) and [Klipper](https://www.klipper3d.org/)/[Moonraker](https://moonraker.readthedocs.io/en/latest/). for connecting to your printer.

markcarroll, 2024-12-21:
@huizebruin I am working on HA and printer integration to 3DFP's My Spools too, but don't want to go off topic here.

@spuder what if I put a link on the 3DFP filament details page that downloads the data you need to create a tag?  Or I can give you an API that gives you that same data. Given the size of the database now, doing the choosing on the web site end would probably be more efficient.  Or maybe we can go to the filament selector page and then do a callback with the JSON.

Without one of your devices I am not super clear on how the mechanics of your side works.  Given some more insight into your system I can happily help work out a good integration. You can get me on Reddit: u/SirThunderCloud or Discord: @sir.thunder.cloud if you want to chat.

koffienl, 2025-01-22:
I was thinking, how about an API link from the 3dfilaments filament details website to the openspool GUI on the ESP?
You open a specific filament on the 3dfilaments site and where the QR code is there is also a link to callback to the OpenSpool GUI to POST or GET the info in JSON.
The GUI opens, with all the necessary info and all you have to do is click write tag.
Alternative you could do it through the openspool.io site, but a quick search tell me writing NFC on mobile through a website has some security issues.

Roving-Ronin, 2025-01-22:
Why not use the OpenSpool application, it has an API you can call that sends back info from its OpenspoolDB (filaments.json).
Easy as to add new filaments via its GitHub.

DocJ-GA, 2025-05-17:
I am working on a spoolman to orcaslicer console app that syncs spoolman spools to orcaslicer filaments.  I would love to look at developing an addon to spoolman to sync extra settings from 3dfilamentprofiles to spoolman via an api.

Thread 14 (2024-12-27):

MQTT limit

demonkazuya, 2024-12-27:
Is there a way we can have this integrated with home assistant? I read that the machine can handle a certain amount of MQTT. I think the reason why I get disconnected is because I have several devices connected (Home Assistant, Xtouch). Not sure if that's the reason for disconnection. I know this is too much of an ask, but it would be great it can be added. Thanks!

spuder, 2024-12-27:
I see you are having disconnects. When you do get a disconnect are there any messages in the logs?

What processor are you using? esp32-s2 or esp32-s3?

What printer type? (A1 Mini, A1, P1P, P1S, X1)

If running the s2, note that it has less memory than the s3 so disconnects are a side effect. Consider upgrading to an s3 board.

I've not yet confirmed but supposedly certain printers allow less MQTT subscribers than others. (Allegedly the limit is 4, but higher on the X1 models).

As far as HomeAssistant, it should be possible to setup as a MQTT Bridge where HA talks to the printer and all your devices talk to HA.

demonkazuya, 2024-12-27:
it's random actually. I'm using the S2.. will try to use S3 and test. It's random actually was not able to have the logs. My printer is a P1S

Also thank you for the suggestion will look at the MQTT bridge to see if that would help. Thanks!

Will keep you posted with the testing

demonkazuya, 2024-12-27:
Here are the logs

`01:10:06
[W]
[mqtt:340]
MQTT Disconnected: TCP disconnected.
01:10:06
[I]
[mqtt:250]
Connecting to MQTT...
01:10:21
[V]
[mqtt.idf:121]
Event dispatched from event loop event_id=7
01:10:21
[V]
[mqtt.idf:124]
MQTT_EVENT_BEFORE_CONNECT
01:10:22
[V]
[mqtt.idf:121]
Event dispatched from event loop event_id=0
01:10:22
[E]
[mqtt.idf:162]
MQTT_EVENT_ERROR
01:10:22
[E]
[mqtt.idf:164]
Last error code reported from esp-tls: 0x8017
01:10:22
[E]
[mqtt.idf:165]
Last tls stack error number: 0x7f00
01:10:22
[E]
[mqtt.idf:166]
Last captured errno : 0 (Success)
01:10:22
[V]
[mqtt.idf:121]
Event dispatched from event loop event_id=2
01:10:22
[V]
[mqtt.idf:133]
MQTT_EVENT_DISCONNECTED
01:10:22
[I]
[main:764]
Disconnected from printer!
01:10:22
[W]
[mqtt:340]
MQTT Disconnected: TCP disconnected.
01:10:22
[I]
[mqtt:250]
Connecting to MQTT...
01:10:36
[V]
[mqtt.idf:121]
Event dispatched from event loop event_id=7
01:10:36
[V]
[mqtt.idf:124]
MQTT_EVENT_BEFORE_CONNECT
01:10:36
[V]
[mqtt.idf:121]
Event dispatched from event loop event_id=0
01:10:36
[E]
[mqtt.idf:162]
MQTT_EVENT_ERROR
01:10:36
[E]
[mqtt.idf:164]
Last error code reported from esp-tls: 0x8017
01:10:36
[E]
[mqtt.idf:165]
Last tls stack error number: 0x7f00
01:10:36
[E]
[mqtt.idf:166]
Last captured errno : 0 (Success)
01:10:36
[V]
[mqtt.idf:121]
Event dispatched from event loop event_id=2
01:10:36
[V]
[mqtt.idf:133]
MQTT_EVENT_DISCONNECTED
01:10:36
[I]
[main:764]
Disconnected from printer!
01:10:36
[W]
[mqtt:340]
MQTT Disconnected: TCP disconnected.
01:10:36
[I]
[mqtt:250]
Connecting to MQTT...
01:10:51
[V]
[mqtt.idf:121]
Event dispatched from event loop event_id=7
01:10:51
[V]
[mqtt.idf:124]
MQTT_EVENT_BEFORE_CONNECT
01:10:52
[V]
[mqtt.idf:121]
Event dispatched from event loop event_id=0
01:10:52
[E]
[mqtt.idf:162]
MQTT_EVENT_ERROR
01:10:52
[E]
[mqtt.idf:164]
Last error code reported from esp-tls: 0x8017
01:10:52
[E]
[mqtt.idf:165]
Last tls stack error number: 0x7f00
01:10:52
[E]
[mqtt.idf:166]
Last captured errno : 0 (Success)
01:10:52
[V]
[mqtt.idf:121]
Event dispatched from event loop event_id=2
01:10:52
[V]
[mqtt.idf:133]
MQTT_EVENT_DISCONNECTED
01:10:52
[I]
[main:764]
Disconnected from printer!
01:10:52
[W]
[mqtt:340]
MQTT Disconnected: TCP disconnected.
01:10:52
[I]
[mqtt:250]
Connecting to MQTT...
01:11:06
[V]
[mqtt.idf:121]
Event dispatched from event loop event_id=7
01:11:06
[V]
[mqtt.idf:124]
MQTT_EVENT_BEFORE_CONNECT
01:11:06
[V]
[mqtt.idf:121]
Event dispatched from event loop event_id=0
01:11:06
[E]
[mqtt.idf:162]
MQTT_EVENT_ERROR
01:11:06
[E]
[mqtt.idf:164]
Last error code reported from esp-tls: 0x8017
01:11:06
[E]
[mqtt.idf:165]
Last tls stack error number: 0x7f00
01:11:06
[E]
[mqtt.idf:166]
Last captured errno : 0 (Success)
01:11:06
[V]
[mqtt.idf:121]
Event dispatched from event loop event_id=2
01:11:06
[V]
[mqtt.idf:133]
MQTT_EVENT_DISCONNECTED
01:11:06
[I]
[main:764]
Disconnected from printer!
01:11:06
[W]
[mqtt:340]
MQTT Disconnected: TCP disconnected.
01:11:06
[I]
[mqtt:250]
Connecting to MQTT...`

so I notice it connects on start up but does this after sometime

Maxklos, 2025-03-10:
Hey, I get the same error and OpenSpool won't connect to my printer:

> A1Mini
> ESP32-S3

```18:19:06[I][mqtt:250]Connecting to MQTT...
18:19:06[V][mqtt.idf:121]Event dispatched from event loop event_id=7
18:19:06[V][mqtt.idf:124]MQTT_EVENT_BEFORE_CONNECT
18:19:06[V][mqtt.idf:121]Event dispatched from event loop event_id=0
18:19:06[E][mqtt.idf:162]MQTT_EVENT_ERROR
18:19:06[E][mqtt.idf:164]Last error code reported from esp-tls: 0x8017
18:19:06[E][mqtt.idf:165]Last tls stack error number: 0x7f00
18:19:06[E][mqtt.idf:166]Last captured errno : 0 (Success)
18:19:06[V][mqtt.idf:121]Event dispatched from event loop event_id=2
18:19:06[V][mqtt.idf:133]MQTT_EVENT_DISCONNECTED
18:19:06[I][main:781]Disconnected from printer!
18:19:06[W][mqtt:340]MQTT Disconnected: TCP disconnected.
```

The A1Mini is connected to the Bambu App & Home Assistant nothing else.

serkan887, 2025-03-14:
Same here. p1s connected just homeassistant, and esp32-s2 board.

`21:56:47
[I]
[mqtt:250]
Connecting to MQTT...
21:57:02
[V]
[mqtt.idf:121]
Event dispatched from event loop event_id=7
21:57:02
[V]
[mqtt.idf:124]
MQTT_EVENT_BEFORE_CONNECT
21:57:02
[V]
[mqtt.idf:121]
Event dispatched from event loop event_id=0
21:57:02
[E]
[mqtt.idf:162]
MQTT_EVENT_ERROR
21:57:02
[E]
[mqtt.idf:164]
Last error code reported from esp-tls: 0x8017
21:57:02
[E]
[mqtt.idf:165]
Last tls stack error number: 0x7f00
21:57:02
[E]
[mqtt.idf:166]
Last captured errno : 0 (Success)
21:57:02
[V]
[mqtt.idf:121]
Event dispatched from event loop event_id=2
21:57:02
[V]
[mqtt.idf:133]
MQTT_EVENT_DISCONNECTED
21:57:02
[I]
[main:781]
Disconnected from printer!
21:57:02
[W]
[mqtt:340]
MQTT Disconnected: TCP disconnected.
21:57:02
[I]
[mqtt:250]
Connecting to MQTT...`

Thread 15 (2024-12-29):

Would it be possible to use the I2C interface instead of the SPI interface?

pzw001, 2024-12-29:
Hello,

I am very interested in your project, and am currently looking at the creation of a PCB which will include everything needed in a nice organized manner. My goal would be at this moment to use the project for my 2 AMS units, so I would need 8 (4 if I can get them to read at both sides ;-) ) or 9 (5) readers. I see that the current solution is to use designated IO pins for the CS signals, which is the easiest / quickest way. But there might be easier options using the I2C interface instead. (Especially with 8 or more readers connected). The goal I set for myself is to get the PCB to fit in one of the openings in the AMS enclosure, so it looks like a nice finished unit.

I would be happy to share my PCB design with the community, once all the possible issues have been resolved.

It might be best to discuss this in an email message instead. Please let me know.

Thanks
Paul

spuder, 2024-12-29:
Hi thanks for reaching out.

So I understand you have 2 AMS and you want to design a PCB that supports 8 readers.

Your help would be greatly appreciated. Here is the current status:

PCB

I have a hand soldered prototype that supports 5 readers. It uses a more powerful esp32-s3. I've also sourced the exact molex connectors that the AMS uses so it could be powered from the 24v from the printer instead of USB.
Designs are in EasyEda. I can invite you to the project.

3d prints

There is an experimental 3d printed insert that fits inside an AMS. It uses DuPont connectors but likely it should be changed to JST connectors. Appropriate cables would need to be sourced

SPI/i2c

I2c is a good idea, however it's not feasible for the project for a couple of reasons.
1. Every pn532 that is sourced has a hard coded 0x42 address with no way to change it without a hardware multiplexer.
2. Clock stretching
I tried for many days to get i2c working with no luck. I found lots of several of people having the same problems. Those who did get it working found it unreliable. The pn532 uses clock stretching which the Esphome library doesn't support.

Since the p1/x1 support up to 17 spools, the preferred design will probably be to have 1x esp32 _per AMS_ and use a CANBUS or wireless link between them, where one of them. Since the P1 (and possibly the x1) have a limit of 4 mqtt clients. More prototypes are needed.

You can reach me in the discord channel as user @spuder and we can chat more if you like.

spuder, 2024-12-29:
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

spuder, 2024-12-29:
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

koffienl, 2025-01-01:
> ![image](https://private-user-images.githubusercontent.com/242382/399180060-76f0ffc1-7729-49f7-b4bf-a2c6b0e53558.jpeg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)

Any chance this would be available for download any time soon?

ManuelW77, 2025-02-01:
> Since the p1/x1 support up to 17 spools, the preferred design will probably be to have 1x esp32 _per AMS_ and use a CANBUS or wireless link between them, where one of them is the dedicated mqtt client since the P1 (and possibly the x1) have a limit of 4 mqtt clients.

You can use a simple mqtt proxy for that. the proxy connects to the printer and copys the channels read/write. So you can connect as many clients you want to the proxy.

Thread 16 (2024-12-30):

Component pn532 is marked FAILED

CyberFreek, 2024-12-30:
Hi, I am trying to setup an OpenSpool Mini and purchased the components and connected everything as per the diagram on the site. My issue is that it seems to be giving me an error related to the PN532 RFID reader, but it doesn't really say what the error is for. Is there any  way I can get a more detailed error?

There is a solid red led illumined on the PN532, but I have no indication what it means.

I am using a Wemos D1 Mini s3.

Here are my logs -

```
ESP-ROM:esp32s3-20210327
Build:Mar 27 2021
rst:0x15 (USB_UART_CHIP_RESET),boot:0x8 (SPI_FAST_FLASH_BOOT)
Saved PC:0x4037bd4e
SPIWP:0xee
mode:DIO, clock div:1
load:0x3fce2810,len:0x178c
load:0x403c8700,len:0x4
load:0x403c8704,len:0xc10
load:0x403cb700,len:0x2dc0
entry 0x403c88fc
I (26) boot: ESP-IDF 5.3.1 2nd stage bootloader
I (27) boot: compile time Dec 14 2024 20:33:11
I (27) boot: Multicore bootloader
I (27) boot: chip revision: v0.1
I (27) boot.esp32s3: Boot SPI Speed : 80MHz
I (27) boot.esp32s3: SPI Mode       : DIO
I (28) boot.esp32s3: SPI Flash Size : 4MB
I (28) boot: Enabling RNG early entropy source...
I (28) boot: Partition Table:
I (28) boot: ## Label            Usage          Type ST Offset   Length
I (29) boot:  0 otadata          OTA data         01 00 00009000 00002000
I (29) boot:  1 phy_init         RF data          01 01 0000b000 00001000
I (29) boot:  2 app0             OTA app          00 10 00010000 001c0000
I (30) boot:  3 app1             OTA app          00 11 001d0000 001c0000
I (30) boot:  4 nvs              WiFi data        01 02 00390000 0006d000
I (31) boot: End of partition table
I (31) esp_image: segment 0: paddr=00010020 vaddr=3c0e0020 size=46724h (288548) map
I (83) esp_image: segment 1: paddr=0005674c vaddr=3fc9a600 size=04918h ( 18712) load
I (87) esp_image: segment 2: paddr=0005b06c vaddr=40374000 size=04fach ( 20396) load
I (92) esp_image: segment 3: paddr=00060020 vaddr=42000020 size=d6b28h (879400) map
I (250) esp_image: segment 4: paddr=00136b50 vaddr=40378fac size=11640h ( 71232) load
I (276) boot: Loaded app from partition at offset 0x10000
I (276) boot: Disabling RNG early entropy source...
I (277) cpu_start: Multicore app
I (286) cpu_start: Pro cpu start user code
I (286) cpu_start: cpu freq: 160000000 Hz
I (286) app_init: Application information:
I (286) app_init: Project name:     openspool
I (286) app_init: App version:      2024.11.3
I (287) app_init: Compile time:     Dec 14 2024 20:32:23
I (287) app_init: ELF file SHA256:  ad730b13f...
I (287) app_init: ESP-IDF:          5.3.1
I (287) efuse_init: Min chip rev:     v0.0
I (287) efuse_init: Max chip rev:     v0.99
I (287) efuse_init: Chip rev:         v0.1
I (288) heap_init: Initializing. RAM available for dynamic allocation:
I (288) heap_init: At 3FCA39B8 len 00045D58 (279 KiB): RAM
I (288) heap_init: At 3FCE9710 len 00005724 (21 KiB): RAM
I (289) heap_init: At 3FCF0000 len 00008000 (32 KiB): DRAM
I (289) heap_init: At 600FE100 len 00001EE8 (7 KiB): RTCRAM
I (290) spi_flash: detected chip: generic
I (290) spi_flash: flash io: dio
W (291) rmt(legacy): legacy driver is deprecated, please migrate to `driver/rmt_tx.h` and/or `driver/rmt_rx.h`
I (293) sleep: Configure to isolate all GPIO pins in sleep state
I (293) sleep: Enable automatic switching of GPIO sleep configuration
I (294) main_task: Started on CPU0
I (295) main_task: Calling app_main()
I (407) main_task: Returned from app_main()
[I][logger:171]: Log initialized
[C][safe_mode:079]: There have been 2 suspected unsuccessful boot attempts
[I][app:029]: Running through setup()...
[V][app:030]: Sorting components by setup priority...
[D][template.select:014]: Setting up Template Select
[D][template.select:017]: State from initial: ABS
[W][main:304]: Unknown temperatures for ABS:
[D][template.select:014]: Setting up Template Select
[D][template.select:017]: State from initial: Basic
[W][main:304]: Unknown temperatures for ABS:
[D][template.select:014]: Setting up Template Select
[D][template.select:017]: State from initial: Generic
[D][template.select:014]: Setting up Template Select
[D][template.select:017]: State from initial: beige
[D][main:126]: Color beige
[D][template.select:014]: Setting up Template Select
[D][template.select:029]: State from restore: X1C/X1E
[D][template.text:016]: Setting up Template Text Input
[D][text:016]: 'Printer IP Address': Sending state 192.168.1.177
[D][main:114]: Missing Bambu Credentials, skipping mqtt connect
[D][template.text:016]: Setting up Template Text Input
[D][template.text:016]: Setting up Template Text Input
[D][text:013]: 'Printer Lan Access Code': Sending state [redacted]
[I][main:082]: Missing Bambu Credentials, skipping mqtt connect
[I][pn532_spi:015]: PN532Spi setup started!
[I][pn532_spi:020]: SPI setup finished!
[C][pn532:018]: Setting up PN532...
[W][pn532:022]: Error sending version command, trying again...
******************************************************[E][pn532:024]: Error sending version command********************************
******************************************************[E][component:119]: Component pn532 was marked as failed.*****************
******************************************************[E][component:164]: Component pn532 set Error flag: unspecified*************
[W][component:157]: Component wifi set Warning flag: scanning for networks
[I][wifi:540]: - 'Skynet' [redacted]▂▄▆█
[I][wifi:540]: - 'Skynet' [redacted]▂▄▆█
[I][wifi:313]: WiFi Connecting to 'Skynet'...
[I][wifi:617]: WiFi Connected!
[C][web_server:100]: Setting up web server...
[C][mqtt:037]: Setting up MQTT...
[I][app:062]: setup() finished successfully!
[W][component:170]: Component wifi cleared Warning flag
[I][app:100]: ESPHome version 2024.11.3 compiled on Dec 14 2024, 20:32:17
[I][app:102]: Project spuder.openspool version 1.14.0
[C][logger:185]: Logger:
[C][logger:186]:   Level: VERBOSE
[C][logger:188]:   Log Baud Rate: 115200
[C][logger:189]:   Hardware UART: USB_SERIAL_JTAG
[C][logger:193]:   Level for 'sensor': INFO
[C][logger:193]:   Level for 'pn532': DEBUG
[C][logger:193]:   Level for 'pn532_spi': DEBUG
[C][logger:193]:   Level for 'spi': INFO
[C][logger:193]:   Level for 'nfc': DEBUG
[C][logger:193]:   Level for 'i2c': INFO
[C][logger:193]:   Level for 'mqtt': DEBUG
[C][logger:193]:   Level for 'mqtt.component': DEBUG
[C][logger:193]:   Level for 'mqtt.client': DEBUG
[C][logger:193]:   Level for 'wifi': INFO
[C][logger:193]:   Level for 'wifi_esp32': INFO
[C][logger:193]:   Level for 'esp-tls': DEBUG
[C][logger:193]:   Level for 'esp-tls-mbedtls': DEBUG
[C][logger:193]:   Level for 'http_client': INFO
[C][logger:193]:   Level for 'http_request': INFO
[C][logger:193]:   Level for 'scheduler': INFO
[C][logger:193]:   Level for 'text_sensor': INFO
[C][logger:193]:   Level for 'esp32_rmt_led_strip': INFO
[C][logger:193]:   Level for 'debug': INFO
[C][logger:193]:   Level for 'web_server': DEBUG
[C][logger:193]:   Level for 'light': INFO
[C][logger:193]:   Level for 'api': INFO
[C][logger:193]:   Level for 'improv_serial': VERBOSE
[C][logger:193]:   Level for 'json': INFO
[C][logger:193]:   Level for 'esp32.preferences': INFO
[C][logger:193]:   Level for 'esp-idf': DEBUG
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
CyberFreek, 2025-01-02:
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

I used this diagram: https://github.com/spuder/OpenSpool/blob/main/images/OpenSpoolMiniWiringDiagram2.png

I took a look at that YAML file and the pins look correct.

Ha!  Well I guess i was overcomplicating what it takes to check the crystal!

Here's the original PN532:
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

And here is the second one:
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

Both of which indicate 27.120 mhz. It was a good thought though!

I did notice something else though, even though I enter my Bambu credentials, I noticed this in that same logfile above:
[D][main:114]: Missing Bambu Credentials, skipping mqtt connect

When I go back and check, they appear to be saved in there correctly, it doesn't seem to be trying them for some reason. Also, in this screenshot, it doesn't show MQTT as enabled - nor can I click on the circle to enable it.
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

Do you have any idea what might be going on here? I wouldn't think this is related to the PN532, but I'm not 100% sure.

Thanks again for the assistance!

spuder, 2025-01-02:
Is the serial number populated? That is also required for MQTT connections.

There might be an ordering dependency that mqtt won't succeed if mqtt is failing. I've not tested that. I would first focus on getting past the `Component pn532 is marked FAILED` error.

It seems unlikely that you got 2 counterfeit PN532 in a row. I have 100 of them in stock, I'll sell you a verified working one at cost if you want as I would really like to see you have a working kit.

CyberFreek, 2025-01-03:
> Is the serial number populated? That is also required for MQTT connections.
>
Actually, I did not have the serial number entered. I did add it and reboot and appears to be looping. plus, the MQTT Connection is still uncheckable as seen below...
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

> There might be an ordering dependency that mqtt won't succeed if mqtt is failing. I've not tested that. I would first focus on getting past the `Component pn532 is marked FAILED` error.
>

Much of this is new ground for me and being in IT for as many decades as I have I have come to learn that sometimes completely unrelated things are connected. I figured if that error was a simple fix, it wouldn't hurt to resolve it - but if you think their might be some dependency on the PN532 loading correctly then we can put that one on the back burner for now.

> It seems unlikely that you got 2 counterfeit PN532 in a row. I have 100 of them in stock, I'll sell you a verified working one at cost if you want as I would really like to see you have a working kit.

Yea, my gut tells me the same thing - that it is highly unlikely that both PN532's are bad - especially since the second one I tried seems to be something of a brand - at least enough to have a website with downloadable manuals [here](https://www.elechouse.com/elechouse/images/product/PN532_module_V3/PN532_%20Manual_V3.pdf).

Still, if your gut is telling you that this feels more like a PN532 issue than a S3-mini issue, then sure I don't mind giving one of yours a try. How should I contact you for payment, address, etc?

CyberFreek, 2025-01-04:
BTW, I just noticed you posted to model out on Makerworld and you are already getting some love, which is awesome!

spuder, 2025-01-04:
If you join the discord and message me I'll send you a board.

https://discord.gg/4EaXHu9CEj

User name is `@spuder`

CyberFreek, 2025-01-09:
So I picked up one of [these](https://www.amazon.com/gp/product/B0CT5DJK7H/ref=ppx_yo_dt_b_asin_title_o00_s00?ie=UTF8&psc=1) from Amazon and realized that the default PIN layout wasn't going to work. So I pulled a copy of the OpenSpool repo, updated a couple of file (in the OpenSpool folder of the ZIP, the Makefile and the YAML that included new GPIO pins as well as support for the WinShare ESP32-S3-Zero card). Then i realized I needed to recompile the firmware.
[esp32-s3-zero.zip](https://github.com/user-attachments/files/18354433/esp32-s3-zero.zip)
So then I fired up a docker container with ESPHome on it and updated the PlatformIO.ini file in the root of the docker image as well as the new board JSON in the .PlatformIO folder located in the home folder and was able to successfully compile and flash the firmware!

It turns out the PN532 board were all fine. The issue was with the S3-Mini. I'm not sure if I just burned it with the soldering iron or what but as you can see here, it found my PN532 and I have been able to write and scan NFC tags with it.
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

Honestly, I"m not sure if I did all that the right way or not but it got my board working!

I don't suppose there is some way to integrate these updated files with what's on Openspool.io? That way when new firmware is released it will be a bit easier for me to update.

spuder, 2025-01-09:
Awesome! So glad to hear. Very strange that your board didn't work.

Closed 2025-01-09.

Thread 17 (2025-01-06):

Web Interface facelift

spuder, 2025-01-06:
# Problem
As a user, I want to see an improved web interface
So that interactions with the esphome web UI provides a friction free user experience

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

# Objective

Research feasibility of creating a new web interface theme that runs on the esp32

# Information

The esphome library currently uses the v3 implementation of the web server component

https://esphome.io/components/web_server.html

# Constraints

Requirements:
- Run on an esp32-s3 board with 2-4MB PSRAM
- Have all `includes` compiled into the firmware (no internet required, see [esphome advanced usage docs](https://esphome.io/components/web_server.html#advanced-usage_)

Optional:
- Run on an esp32-s2 board with 0MB PSRAM (early adopters got s2 boards, it would be good to upgrade them if possible)
- Include the OpenSpool Logo (svg/png is included in the `images` folder.

# Resources
- 3rd party esphome web interface: https://esp.veli.ee
- esphome web interface documentation: https://esphome.io/components/web_server.html

# Additional Notes

I previously did research into using a native ESPHOME color picker, however ran into problems because the filament type is an 'led' object with `ColorCapability::BRIGHTNESS` hard coded.

To get a color picker either the web interface javascript would need to be modified, or a custom component would need to be made. See branch [color-picker](https://github.com/spuder/OpenSpool/tree/color-picker)

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

https://discord.com/channels/429907082951524364/524177279270780928/1299942698664333385

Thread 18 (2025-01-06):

Filament color temperatures are not intuitive

spuder, 2025-01-06:
As a user who wants to program a tag
It is confusing that fields which can't be selected (Filament Color Hex) are next to fields that must be selected ( temperature, type)

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

## Requested Changes

Re-group the "Filament Settings" section so that user specified fields are at the top, and informational fields are below

- Filament Brand
- Filament Color
- Filament Max Temp
- Filament Min Temp
- Filament Type

---

- Filament Color Hex
- Filament Color Hex Bambu (maybe just remove this line entirely)

The "Upload Settings Button" and "Write NFC" Buttons should probably be moved to be more intuitive.

raihei, 2025-01-12:
Do you want to create a new group for the the informational fields? I think, moving them down already makes it far more clearer without "wasting" more space for an additional group header. I prefer, to have all 4 drop down menus at the top, and then the sliders for the temperature. It looks more clean, and makes no difference in sense.
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

spuder, 2025-01-12:
> Do you want to create a new group for the the informational fields?

I like your idea. A new group is probably overkill. Simply re-sorting the fields like you have shown would be cleaner if that is possible.

I haven't sorted entities within a group but it looks like the web server component allows sorting by both group and entity.

https://esphome.io/components/web_server.html#entity-sorting

raihei, 2025-01-12:
Thanks.
Yes, that is how I have done it, I have just added a sorting_weight to each entity.
I can create a pull request, if wanted.

spuder, 2025-01-12:
> I can create a pull request, if wanted.

Yes please.

We are going to record a tutorial video this week of how to use the interface, so your timing is perfect. I this gets merged in before the next couple of days then we will include your changes in the video.

spuder, 2025-01-12:
Released in v1.15.0

Closed 2025-01-12.

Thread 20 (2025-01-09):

Enhancement Request:  Pass alpha channel in RGB code to allow for transparent filaments

mytechguyri, 2025-01-09:
I see in the Bambu MQTT API, that they actually support the alpha channel in the MQTT message as shown here

`{
    "print": {
        "sequence_id": "0",
        "command": "ams_filament_setting",
        "ams_id": 0, // Index of the AMS
        "tray_id": 0, // Index of the tray
        "tray_info_idx": "", // Probably the setting ID of the filament profile
        _**"tray_color": "00112233", // Formatted as hex RRGGBBAA (alpha is always FF)**_
        "nozzle_temp_min": 0, // Minimum nozzle temp for filament (in C)
        "nozzle_temp_max": 0, // Maximum nozzle temp for filament (in C)
        "tray_type": "PLA" // Type of filament, such as "PLA" or "ABS"
    }
}`

Sending the alpha channel as 00 instead of FF tells Bambu Studio its actually a transparent filament, which is preferable to clear filament showing as white.

spuder, 2025-01-09:
Great observation.

This is the line of code where transparency is hard coded to `ff`

https://github.com/spuder/OpenSpool/blob/main/firmware/bambu.h#L131

This will need to be changed to a variable for alpha.

I took a quick look at Bambu Studio and I see the way they are handling it is by making a new filament with name 'translucent'.
It appears they currently only support PETG, there is no translucent PLA/ABS for example. Transparent PETG has its own code GFG01

https://github.com/bambulab/BambuStudio/blob/c1b3cc0bf1c6c9be26ffdaa772da5a2716751677/resources/profiles/BBL/filament/Bambu%20PETG%20Translucent%20%40base.json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

mytechguyri, 2025-01-14:
The thing is... I believe BambuStudio accepts the Alpha channel variable... You're passing FF as default according to the logs in the mqtt data...
17:09:16
[I]
[mqtt:148]
Publishing {"print":{"sequence_id":"0","command":"ams_filament_setting","ams_id":255,"tray_id":254,"tray_color":"E27A2BFF","nozzle_temp_min"

which is fine.. but if the end user passes an alpha channel value in the NFC tag, Openspool chokes on it and logs the following error "17:11:28
[E]
[bambu:122]
Invalid color_hex length (expected 6 characters)"

Better  would be... if len = 6  (i.e. E27A2B) then append FF and pass E27A2BFF in the mqtt data
if len = 8 then pass the 8 digits as is in the mqtt data, which should pass the alpha channel value.

There are cases in Bambu Studio where it allows you to select transparent filament, without choosing the "Translucent" type... have you ever seen where the folor shows as a grey and white checkboard?   That's because BambuStudio somehow has a 00 alpha channel value for the color... They don't make it easy to input, but the software does handle it just fine if the value is set to 00

raihei, 2025-01-17:
> There are cases in Bambu Studio where it allows you to select transparent filament, without choosing the "Translucent" type... have you ever seen where the folor shows as a grey and white checkboard? That's because BambuStudio somehow has a 00 alpha channel value for the color... They don't make it easy to input, but the software does handle it just fine if the value is set to 00

Somehow I set it to transparent in the past for my transparent filament, but now I don't know anymore, how I did that. Can you give me a hint, how to set it in BambuStudio?

raihei, 2025-01-20:
@spuder I prepared a commit to include creation of tags with filament color alpha channel, if wanted I can create a pull request

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

spuder, 2025-01-21:
Yes please

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

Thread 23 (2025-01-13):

Support TPU for AMS

spuder, 2025-01-13:
Add support for TPU for AMS

The filament ID  is `GFU02`

## Resources

https://github.com/bambulab/BambuStudio/blob/5780410c2f3af09af5dfea46ac8967cd57645b66/resources/profiles/BBL/filament/Bambu%20TPU%20for%20AMS%20%40base.json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

https://github.com/bambulab/BambuStudio/blob/5780410c2f3af09af5dfea46ac8967cd57645b66/resources/profiles/BBL/filament/Bambu%20TPU%2095A%20HF%20%40base.json

spuder, 2025-01-13:
Fixes in https://github.com/spuder/OpenSpool/pull/25

Closed 2025-01-13.

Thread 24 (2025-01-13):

Proper RFID Programming

usajet, 2025-01-13:
What are the proper steps to program the RFID Tags for Bambu Labs X1C? Just having issues with the programming.

spuder, 2025-01-13:
Sorry to hear you're having trouble programming tags.

Is it unreliable or what is the problem you were finding?

Program a tag you go into the web interface at http://openspool-xxxxxx.local or http://192.168.x.x

Then you need to select the filament type filament color and filament brand and filament temperature range.

After you said that press the right NFC button and then touch tag to the reader. It works best in the corners of the reader, hold it for one to two seconds.

If there's a problem writing, it will light up red and you'll see an error in the logs

usajet, 2025-01-13:
Okay that is what I needed. Wasn't sure. I try to scan the rfid on my phone and no info shows up. I have a android phone.

usajet, 2025-01-13:
Can we add our own filament to the program?

spuder, 2025-01-13:
Currently, it only supports a select, subset of bambu recognized codes. If it's not a filament that is currently recognized just select generic.

There are plans to improve this and pull from other databases, but for now it's only the bambu codes

mytechguyri, 2025-01-14:
If we put a brand (because I use the NFC tags for more than just scanning to the printer, I use them to inventory my filament as well)   So, if I put brand as "Jayo" or "Flashforge" or "Reprapper"... will the device just treat that as generic or will it error because its not one of the defined brands?

spuder, 2025-01-15:
get_bambu_code()

It will return an empty string which the printer will probably ignore (unverified).

Would you be willing to open a feature request to change that behavior? We could make it fall back to `generic` instead of failing silently.

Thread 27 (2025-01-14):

Internal LED pinout is backwards

spuder, 2025-01-14:
The internal led lights up the wrong colors (red and green are swapped)

Also it should probably be hidden from the UI as it is not used

raihei, 2025-01-15:
I was already wondering, for what the internal LED was used, because I couldn't find any references in the sources.
On my board (Waveshare ESP32-S3-Zero) the colors are correct. On which board did you discover that issue?

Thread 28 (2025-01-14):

X1 has wrong temperature

spuder, 2025-01-14:
Feedback from discord

> Seems the "Upload Settings" button is sending some strange data to my X1C.

> I've tried several combinations (but not all) and the most glaring issue is that the Min Temp and Max Temp are all very wrong!
In the webapp, I selected Min to be 190C and the Max to be 240,  Generic PLA, missletoe_green and on the printer display the Min temp comes up as 65470 C and the Max comes up as 65520 C! OUCH!

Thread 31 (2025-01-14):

Suppress url encoding warnings messages in logs

spuder, 2025-01-14:
The user interface repeatedly displays this warning when interacting with the UI.
These warnings should be suppressed. Check esphome documentation for how to do this.

```
[15:17:34][W][web_server_idf:070][httpd]: Only application/x-www-form-urlencoded supported for POST request
[15:17:36][W][web_server_idf:070][httpd]: Only application/x-www-form-urlencoded supported for POST request
```

## Ideas

1. Most likely it could be turned off in the logger.yaml with something like this:

```
logger:
  logs:
    web_server.idf: ERROR
 ```

raihei, 2025-04-11:
With the current esphome version that bug seems to be gone.

For that esphome version it is required to comment out "rmt_channel: 0" in "led-external.yaml" to compile successfully.

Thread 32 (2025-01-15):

Everything seems to be working (I think), but printer is not updated.

mytechguyri, 2025-01-15:
Running 1.16 firmware.... it scans the NFC tag, publishes the change.... nothing changes on the printer
A1 Mini

(you need a support email address :) )
`19:20:06
[D]
[pn532:367]
Mifare ultralight
19:20:06
[D]
[NFC:064]
Payloa
19:20:06
[D]
[NFC:131]
Input strin
19:20:06
[I]
[mqtt:150]
Publishing {"print":{"sequence_id":"0","command":"ams_filament_setting","ams_id":255,"tray_id":254,"tray_color":"FFFFFFFF","nozzle_temp_min":205,"nozzle_temp_max":215,"tray_type":"PLA","setting_id":"","tray_info_idx":"GFL99"}}
19:20:06
[D]
[pn532:200]
Found new tag '04-AD-D4-6C-BB-2A-81'
19:20:06
[D]
[pn532:204]
NDEF formatted records:
19:20:06
[D]
[pn532:206]
application/json
19:20:06
[D]
[pn532:379]
Waiting to read next tag
19:20:06
[W]
[component:237]
Component pn532 took a long time for an operation (198 ms).
19:20:06
[W]
[component:238]
Components should block for at most 30 ms.
19:20:08
[D]
[NFC:128]
Input string is empty`

mytechguyri, 2025-01-15:
A1 Mini with firmware 1.04.00.00

raihei, 2025-01-15:
You can connect to the printer via MQTT Explorer and check what it reports:

https://mqtt-explorer.com/

Please use the settings shown here to connect:

https://forums.homeseer.com/forum/lighting-primary-technology-plug-ins/lighting-primary-technology-discussion/mcsmqtt-michael-mcsharry/1601281-how-to-integrate-bambu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

Password to connect is the access code, can be found in the printer menu.

Wait until a very long report is shown, then you can stop the updating (pause button in the upper bar in MQTT explorer) and on the right side, you can see the contents of the report.

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

spuder, 2025-01-15:
Likely culprit: https://github.com/spuder/OpenSpool/issues/28

The "upload settings" button is intended for debugging and it looks like it is sending the temperature values incorrectly.
The nfc tag works as expected.

mytechguyri, 2025-01-16:
Okay, wasn't sure if it was a problem with my NFC tag or what... so tag is working as expected.... other than its not updating the printer as expected, so there's that.. lol.   just out of curiousity... Are you attempting the updates via local MQTT on the printer, or CLOUD MQTT with Bambu?    If I'm not mistaken, Bambu has essentially disabled local MQTT on cloud connected printers, and requires you send through the Bambu Cloud MQTT server...  Perhaps that's why its not updating?

mytechguyri, 2025-01-16:
Well.... I don't know what I did, but today its working as it should... scan the tag, color changed on the printer.   All i can figure is perhaps (and this is a complete wild ass guess)... Between Bambu Handy, an instance of Bambu Studio, an instance of Orca Slicer,  and the Panda Touch all being connected and operating, we reached the connection limit for the printer?   I dunno, but its working.

spuder, 2025-01-16:
Great! Glad to hear.

We don't know where the limit is yet. It might be 4 MQTT connections, but haven't confirmed that yet. It's entirely possible it was getting rejected.

Closed 2025-01-16.

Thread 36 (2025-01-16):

Firmware Update Introducing New Authorization Control System

koffienl, 2025-01-16:
https://blog.bambulab.com/firmware-update-introducing-new-authorization-control-system-2/

As part of our ongoing commitment to enhance the overall security of our products, we are introducing an authorization and authentication protection mechanism for the connection and control of Bambu Lab 3D printers. This step is a significant security enhancement to ensure only authorized access and operations are permitted.

Critical Operations That Require Authorization
The following printer operations will require authorization controls:

Binding and unbinding the printer.
Initiating remote video access.
Performing firmware upgrades.
Initiating a print job (via LAN or cloud mode).
Controlling motion system, temperature, fans, **AMS settings**, calibrations, etc.

mytechguyri, 2025-01-16:
This is NOT good... Don't update to this new firmware.... I expect its to break Panda Touch, as well as OpenSpool.... and they add another layer to OrcaSlicer, so you can no longer seemlessly send your prints, you have to save the gcode, then use Bambu Connect software to send the gcode to the printer.... Make your dissatisfaction with this known to Bambu (I'm also thinking of lodging a complaint with the FTC about this anti-competitive tactic that Bambu is introducing under the false premise of "security")

spuder, 2025-01-16:
I've already been in contact with Bambu's development group, I'm waiting to hear back.

While this is an unfortunate setback, it's not the end of the road for OpenSpool. There are still multiple paths forward. Some involve software changes, others involve hardware changes.

When Bambu made changes to disable the LAN mode, they took the feedback to heart and backpedaled so that LAN mode is still an option. I'm optimistic they will do the same here.

The list of current options

1. Document users should not update firmware (P1/A1 are not enforcing yet)
2. Leverage Bambu Connect as mqtt proxy. This might be a good option anyway since there is a device limit. By leveraging the Bambu Connect as a REST to MQTT proxy, 3rd party devices might still be supported
3. Work with bambu to get TLS signing certificate pipeline for firmware. This might prevent end users from compiling their own unsigned esphome configs, but there likely will be a path forward here.
4. Resdesign the hardware to plug directly into the AMS interface CANBUS. While tricky, it is doable and would be really hard for them to block.

In the mean time I'm leveraging all the channels I have to talk with Bambu about how this will hurt 3rd party products like OpenSpool, X-Touch, Panda Touch, BLLED, HomeAssistant

mytechguyri, 2025-01-16:
Well, to help them "backpedal" I filed my complaint with the FTC about their anti-competitive tactic disquised as "security" (its already secure through use of the access token system, which is only available on the printer itself... they know this is not about security, its about shutting down third party devices.

FTC Report Number
182500022

xperiments, 2025-01-17:
@spuder Please contact me at xperiments@gmail.com

darkorb, 2025-01-18:
> this anti-competitive tactic that Bambu is introducing under the false premise of "security"

100% this is a false thing from them, there is zero need to do this on LAN. I couldn't care less if they tightend up the cloud side of things (which they probably should do, if what they say about the number of unappreoved requests is true) but targeting local network use is just using insane nonsense arguments like "well your network is also insecure because trojans" sigh. Like, if my network had a trojan and someone wanted to target the printer, they'd just abuse the machine that connect is on (not to mention, they'd rather that they just snaffle your banking/online account creds instead tbh).

You can also open support cases under `Complaints and Suggestions -> Complaints -> Product issues` and see if they listen. Doubt it though.

Schrolli91, 2025-01-20:
There are some clarifications from Bambu Lab now
https://blog.bambulab.com/updates-and-third-party-integration-with-bambu-connect/

spuder, 2025-01-20:
Thanks for the link.

The new developer mode will likely be the best path forward.
We are also looking at a design that uses a different interface. Holding
off on details until a prototype exists.

On Mon, Jan 20, 2025 at 5:41 AM Bastian Schroll ***@***.***>
wrote:

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

luckyzor, 2025-01-22:
Sorry by asking this here, but I cant find any information.
What is the last firmware supported by openspool for a X1C?
Is it the 1.0.8?

I want to know so I can downgrade and lock internet access do the printer.
Thank you

spuder, 2025-01-22:
The latest firmware that came out last week 1.08 breaks the MQTTAPI for X one users.

X one users will either need to downgrade to 107 or wait for the new developer mode that will be coming later this year From bambu labs

akagalford, 2025-01-22:
I'm currently running Openspool 1.17 with Firmware 1.08.02.00 on my X1c and
the NFC scan for updating my 5th spool settings change on my X1c is working
for me. What part is having issues?

On Wed, Jan 22, 2025 at 3:12 PM Spencer Owen ***@***.***>
wrote:

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

luckyzor, 2025-01-22:
> The latest firmware that came out last week 1.08 breaks the MQTTAPI for X1 users.
>
> X1 users will either need to downgrade to 1.07 or wait for the new developer mode that will be coming later this year from bambu labs

I'm using orca slicer and Home assistant with 1.08.02 and thats why I asked this question, because I saw in the "buy kit" page the last firmware supported was 1.07...

luckyzor, 2025-01-23:
> The latest firmware that came out last week 1.08 breaks the MQTTAPI for X1 users.
>
> X1 users will either need to downgrade to 1.07 or wait for the new developer mode that will be coming later this year from bambu labs

Can you confirm this? I really want to use this project.

koffienl, 2025-01-23:
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

As far as I know is the firmware still in Beta.
The beta firmware with the security 'feature' is 01.08.03.00
The latest stable/public firmware version is 01.08.02.00 and does not have this issue.

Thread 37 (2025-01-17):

SUGGESTION:  Revision to data fields, an openspool 1.1 if you will

mytechguyri, 2025-01-17:
What has been created with OpenSpool is so much more than just a way to update color on the printer, its also an easy way to document key data about each filament.   With the custom of re-spooling, or using "universal" spools, the information that was on the original spool is often lost once the cardboard spool ends are peeled off and discarded, making it nearly impossible to go back and buy the same color or shade when you run out, and hex colors aren't at all accurate when you've got things like tri-color silk filaments.  For that reason, I would like to suggest some minor changes to the json data structure, adding a couple key data points, and in addition keeping some consistency with what Bambu Studio uses

version: 1.x
protocol: openspool
color_hex: RRGGBBAA    (add optional alpha channel data to be passed to the host machine, 00 = translucent color FF= solid color)
color_name: vendor's color name, i.e. "Burnt Titanium" or "
type: PLA (types listed in Bambu slicer)
min_temp:
max_temp:
brand: PolyLite (i.e. PolyLite, PolyTerra, Fiberon, Bambu, Flashforge, Voxel, Jayo, Inslogic, Sunlu, eSun, Generic) this is the value passed to the printer allow anything here, the printer should take anything it doesn't recognize as "Generic"
vendor: Polymaker    (This seems redundant, but with brands such as Voxelab, one wouldn't know the actual vendor is Flashforge for example)
serial:  basic, matte, silk, galaxy, glow, marble, HS, HF, Rapid (this is the field name designated in Bambu Studio for this info)
misc: miscellaneous data the end user wishes to record, could be amount on spool, drying temps and times, bed temp, volumetric flow rate, etc.

Obviously one could keep going on what data you wanted to record, but with only 492 bytes on most NFC chips, it obviously has to have some limits,

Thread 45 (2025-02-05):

Feature: Need an indication that Write Tag is finished

Rich-b1, 2025-02-05:
OpenSpool version: 1.18.0

1. Using Sliders and Selections input Filament tag data.
2. Press 'Write NFC" (I suggest this should be something more friendly, perhaps "Create Tag" or "Write Tag")
3. Notice, that unless a user is watching the log window in their browser, there is no indication on the OpenSpool device that the write was performed.

I suggest an LED color or sequence that's different than others. Perhaps two yellow blinks? One at start of the write sequence, and then other blink at the finish of the write sequence, this is to alert the user to wait until the write is finished.

If a failure to write for some reason, perhaps blink yellow-red-yellow?

After the tag is removed, the LED can return to the normal color (white)

Closed 2025-04-08.

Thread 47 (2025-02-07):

Add new matte colors

spuder, 2025-02-07:
Add support for the new Matte colors

https://www.reddit.com/r/BambuLab/comments/1ik2eq8/new_pla_matte_colors/

mytechguyri, 2025-02-19:
Just my two cents on this, but I really don't see the value to spending time on this one.... Okay, Bambu has released a bunch of matte colors.... but Bambu filament already has RFID encoding of those colors, so you're not going to actually use any of these on the Bambu matte color filaments.... and if you're going to use these colors on 3rd party filament, the device already fully supports RGB hex colors, so you can literally configure any color in the rainbow by simply programming the correct RGB color code on the tag.

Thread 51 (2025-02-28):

hardware:  Add a piezo beeper

mytechguyri, 2025-02-28:
one minor annoyance when using the OpenSpool Lite device... when you're scanning a spool of filament, you can't see the green light, because there's a spool of filament in the way.

would be nice to add a piezo beeper to the unit.... green led, 1 beep    red led, 2 beeps.

Then there's some audio feedback to a successful scan.

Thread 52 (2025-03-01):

Support for TigerTag

spuder, 2025-03-01:
Add support for Tiger Tag

https://tigertag.io

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

TigerTag-Project, 2025-07-16:
Hi @spuder ,

Thanks for your interest in integrating TigerTag!

To get started, you can refer to the official TigerTag RFID Guide available here:
📘 https://github.com/TigerTag-Project/TigerTag-RFID-Guide

The most important step is to include the TigerTag ID database, which allows decoding the tag data properly:
📁 https://github.com/TigerTag-Project/TigerTag-RFID-Guide/tree/main/database
This database can be used locally or accessed via a free and anonymous REST API.

We’re fully available to support this integration — feel free to reach out anytime, we’re happy to help!

— TigerTag Team

goeland86, 2025-08-05:
@spuder I'm happy to try and take a crack at implementing this. I have TigerTag NFCs and a USB NFC reader. I'll get my hands on a PN532 as well shortly.

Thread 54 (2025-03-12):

Feature Request

legotrain333, 2025-03-12:
Touchscreen Printer Selection: Add a touchscreen to the NFC reader, allowing users to manually select which printer the filament is being used on. This ensures accurate tracking across multiple machines and prevents mismatched filament usage.

mytechguyri, 2025-06-28:
A touchscreen would be fantastic.... Check out how SpoolEase did it
https://github.com/yanshay/SpoolEase

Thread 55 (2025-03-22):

Connection to A1 MQTT not possible

Ciredm, 2025-03-22:
Hi!
I've big issue to use OpenSpool, I'm unable to connecte to MQTT:

```

[I][mqtt:250]: Connecting to MQTT...
[V][mqtt.idf:121]: Event dispatched from event loop event_id=7
[V][mqtt.idf:124]: MQTT_EVENT_BEFORE_CONNECT
[V][mqtt.idf:121]: Event dispatched from event loop event_id=0
[E][mqtt.idf:162]: MQTT_EVENT_ERROR
[E][mqtt.idf:164]: Last error code reported from esp-tls: 0x8017
[E][mqtt.idf:165]: Last tls stack error number: 0x7f00
[E][mqtt.idf:166]: Last captured errno : 0 (Success)
[V][mqtt.idf:121]: Event dispatched from event loop event_id=2
[V][mqtt.idf:133]: MQTT_EVENT_DISCONNECTED
[I][main:783]: Disconnected from printer!
[W][mqtt:340]: MQTT Disconnected: TCP disconnected.
[I][mqtt:250]: Connecting to MQTT...
[V][mqtt.idf:121]: Event dispatched from event loop event_id=7
[V][mqtt.idf:124]: MQTT_EVENT_BEFORE_CONNECT
[V][mqtt.idf:121]: Event dispatched from event loop event_id=0
[E][mqtt.idf:162]: MQTT_EVENT_ERROR
[E][mqtt.idf:164]: Last error code reported from esp-tls: 0x8017
[E][mqtt.idf:165]: Last tls stack error number: 0x7f00
[E][mqtt.idf:166]: Last captured errno : 0 (Success)
[V][mqtt.idf:121]: Event dispatched from event loop event_id=2
[V][mqtt.idf:133]: MQTT_EVENT_DISCONNECTED
[I][main:783]: Disconnected from printer!
[W][mqtt:340]: MQTT Disconnected: TCP disconnected.

```

I can connect to A1 MQTT directly using MQTT Explorer, access code are correct.
This error seems to be known (https://esp32.com/viewtopic.php?t=28325). Bambu Lab public key is not include in OpenSpool code?

Thanks for your help.

spuder, 2025-03-22:
Sorry to hear it isn't working. OpenSpool has been tested on multiple A1 Mini and P1S.

What MCU (esp32-s2/ esp32-s3) ?
What firmware version of A1 ?

Others have reported occasional issues connecting to printers, but it usally is resolved by disconnecting all MQTT clients and then rebooting the printer.

Lastly double check the serial number and LAN Access code are correct (Including case sensitive).

Ciredm, 2025-03-22:
Hi, thank for your very quick answer!
 I use an ESP32-S2. My A1printer have 01.04.00.00 firmware version.

For access code and LAN access, I've retry lot of time since 3 days (and it is working using MQTT Client to connect to printer).
I've reboot twice my printer, I'l try with my panda knomi disconnected.

spuder, 2025-03-27:
What firmware version are you using?

The esp32-s2 barely has enough memory to establish TLS connections.
Also there are fake esp32-s2 boards which do not have PSRAM which make this problem more pronounced.
Firmware 1.19 removed some features to free up a few bytes on the s2 boards.

While you probably don't want to upgrade, the s3 boards have sufficient memory and are more reliable at connecting. All new openspool boards from the store have switched to the s3 for that reason.

Do you see in the web interface how much heap is available?

I'll borrow an A1 printer to test and see if I can reproduce.

Ciredm, 2025-03-29:
Hi,
I've clean all my config and re-install esphome and openspool yesterday (28/03/25)
ESPHome 2025.3.2 and main branch for openspool git (identified in code  by v1.19.1)

Only change in source code is: led-external.yaml @line 13: commented due to compiling error ESP-IDF 5.
`
$esphome run lolin_s2_mini.yaml
INFO ESPHome 2025.3.2
INFO Reading configuration lolin_s2_mini.yaml...
WARNING The selected ESP-IDF framework version is not the recommended one. If there are connectivity or build issues please remove the manual version.
WARNING GPIO0 is a strapping PIN and should only be used for I/O with care.
Attaching external pullup/down resistors to strapping pins can cause unexpected failures.
See https://esphome.io/guides/faq.html#why-am-i-getting-a-warning-about-strapping-pins
WARNING The selected ESP-IDF framework version is not the recommended one. If there are connectivity or build issues please remove the manual version.
INFO Generating C++ source...
INFO Updating https://github.com/espressif/esp-protocols.git@mdns-v1.8.0
INFO Compiling app...
Processing openspool (board: lolin_s2_mini; framework: espidf; platform: platformio/espressif32@6.9.0)
---------------------------------------------------------------------------------------------------------
HARDWARE: ESP32S2 240MHz, 320KB RAM, 4MB Flash
 - framework-espidf @ 3.50301.0 (5.3.1)
 - tool-cmake @ 3.16.4
 - tool-ninja @ 1.7.1
 - tool-riscv32-esp-elf-gdb @ 12.1.0+20221002
 - tool-xtensa-esp-elf-gdb @ 12.1.0+20221002
 - toolchain-esp32ulp @ 2.35.0-20220830
 - toolchain-riscv32-esp @ 13.2.0+20240530
 - toolchain-xtensa-esp-elf @ 13.2.0+20240530
Reading CMake configuration...
Dependency Graph
|-- ArduinoJson @ 6.18.5
Compiling .pioenvs/openspool/src/main.cpp.o
Linking .pioenvs/openspool/firmware.elf
RAM:   [=         ]  11.2% (used 36844 bytes from 327680 bytes)
Flash: [=======   ]  69.2% (used 1270339 bytes from 1835008 bytes)
Building .pioenvs/openspool/firmware.bin
Creating esp32s2 image...
Successfully created esp32s2 image.
esp32_create_combined_bin([".pioenvs/openspool/firmware.bin"], [".pioenvs/openspool/firmware.elf"])
SHA digest in image updated
Wrote 0x1463b0 bytes to file /home/mederic/OpenSpool/firmware/.esphome/build/openspool/.pioenvs/openspool/firmware.factory.bin, ready to flash to offset 0x0
esp32_copy_ota_bin([".pioenvs/openspool/firmware.bin"], [".pioenvs/openspool/firmware.elf"])
===================================== [SUCCESS] Took 31.21 seconds =====================================
INFO Successfully compiled program.
Found multiple options for uploading, please choose one:
  [1] /dev/ttyACM0 (ESP32-S2)
  [2] Over The Air (openspool.local)
(number): 1
esptool.py v4.8.1
Serial port /dev/ttyACM0
Connecting...
Chip is ESP32-S2FNR2 (revision v1.0)
Features: WiFi, Embedded Flash 4MB, Embedded PSRAM 2MB, ADC and temperature sensor calibration in BLK2 of efuse V2
Crystal is 40MHz
MAC: cc:8d:a2:82:12:f0
Uploading stub...
Running stub...
Stub running...
Changing baud rate to 460800
Changed.
Configuring flash size...
Auto-detected Flash size: 4MB
Flash will be erased from 0x00010000 to 0x00146fff...
Flash will be erased from 0x00001000 to 0x00006fff...
Flash will be erased from 0x00008000 to 0x00008fff...
Flash will be erased from 0x00009000 to 0x0000afff...
Compressed 1270704 bytes to 846916...
Wrote 1270704 bytes (846916 compressed) at 0x00010000 in 9.4 seconds (effective 1086.7 kbit/s)...
Hash of data verified.
SHA digest in image updated
Compressed 22400 bytes to 13786...
Wrote 22400 bytes (13786 compressed) at 0x00001000 in 0.3 seconds (effective 665.3 kbit/s)...
Hash of data verified.
Compressed 3072 bytes to 134...
Wrote 3072 bytes (134 compressed) at 0x00008000 in 0.0 seconds (effective 552.5 kbit/s)...
Hash of data verified.
Compressed 8192 bytes to 31...
Wrote 8192 bytes (31 compressed) at 0x00009000 in 0.1 seconds (effective 801.6 kbit/s)...
Hash of data verified.

Leaving...
INFO Upload with baud rate 460800 failed. Trying again with baud rate 115200.
esptool.py v4.8.1
Serial port /dev/ttyACM0
Connecting....
Chip is ESP32-S2FNR2 (revision v1.0)
Features: WiFi, Embedded Flash 4MB, Embedded PSRAM 2MB, ADC and temperature sensor calibration in BLK2 of efuse V2
Crystal is 40MHz
MAC: cc:8d:a2:82:12:f0
Uploading stub...
Running stub...
Stub running...
Configuring flash size...
Auto-detected Flash size: 4MB
Flash will be erased from 0x00010000 to 0x00146fff...
Flash will be erased from 0x00001000 to 0x00006fff...
Flash will be erased from 0x00008000 to 0x00008fff...
Flash will be erased from 0x00009000 to 0x0000afff...
Compressed 1270704 bytes to 846916...
Wrote 1270704 bytes (846916 compressed) at 0x00010000 in 9.4 seconds (effective 1085.2 kbit/s)...
Hash of data verified.
SHA digest in image updated
Compressed 22400 bytes to 13786...
Wrote 22400 bytes (13786 compressed) at 0x00001000 in 0.3 seconds (effective 671.3 kbit/s)...
Hash of data verified.
Compressed 3072 bytes to 134...
Wrote 3072 bytes (134 compressed) at 0x00008000 in 0.0 seconds (effective 616.9 kbit/s)...
Hash of data verified.
Compressed 8192 bytes to 31...
Wrote 8192 bytes (31 compressed) at 0x00009000 in 0.1 seconds (effective 791.9 kbit/s)...
Hash of data verified.

Leaving...
Error: ESP32-S2FNR2 (revision v1.0) chip was placed into download mode using GPIO0.
esptool.py can not exit the download mode over USB. To run the app, reset the chip manually.
To suppress this note, set --after option to 'no_reset'.
`

Error is still here!

Ciredm, 2025-05-10:
Hi,

Using S3 mini, no more issue. I suppose (but not tested), issue is due to Bambu A1 mqtt connexion limit (near 4 clients) with long long time release (hours, maybe 1 day).

1) Home Assistant
2) Panda Knomi
3&4) Bambu Studio (2 computers, depend of my location)

I cannot connect Openspool... But when received S3 board an try it without open bambu studio, OpenSpool's mqtt  work.
And one bambu studio return -1 error when try to contact A1.

I havn't performed more tests.

Bye.

Closed 2025-07-03.

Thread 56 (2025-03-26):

Simple Docs

mworsnop, 2025-03-26:
I've got my openspool preassembled and tested, so I didn't have to mess up making it work. I got it on the network. Everything's great.
But I'm old and I guess I just don't understand every single step here. It manages to read an RF ID and I can see that. It connected to my bambu X1C printer. Now I'm trying to figure out exactly what I can use it for and how to use it. I would've loved to sent a message to Support or something, but I have no idea how to contact anybody. Maybe somebody can give me an email address or a support form or something. Sorry for the stupid questions.

spuder, 2025-03-27:
I'm glad to hear you got an openspool and have it connected to your Bambu X1C.

As far as usage there are multiple ways to use it.

The intended use case is to put the stickers on the spools then either use the openspool mini or the iPhone/android app to read the tags.

Were you are likely getting hung up is by the AMS. The current firmware only works with the external spool, but there is code in works to make it also work with an AMS aswell.

mworsnop, 2025-03-27:
I assume that I use the open spool app to write the information to the
stickers. Is that correct?

And the information that gets written is what is on the first part of the
app.

mworsnop, 2025-03-30:
Would it be possible to add a field up at the top that would be like an ID or something that I could enter manually before I create a tag. Then later, when I grab the spool, I can scan it and make sure that number is the number that's matching in my database. Does that make sense? Is that possible?

Thing maybe you could clear up I don't understand what they do. In the filament settings at the top, there is a button to upload settings. Where is it uploading it too and what is the purpose of it?

Then down at the bottom in the extra section, there is a bamboo handy create tag button. What does it do? And I assume the open school create tag will write to a blank tag or something. I'm not sure. I'm sorry I'm really blind here trying to figure this out. Sure would appreciate some help. Thank you.

raihei, 2025-04-11:
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
The "Upload settings" button uploads the currently selected filament settings to the printer. That button is for testing only and might not work 100% (There were/are problems with the temperatures)
The "Write NFC" button will write a tag with the currently selected filament settings.

> Then down at the bottom in the extra section, there is a bamboo handy create tag button. What does it do? And I assume the open school create tag will write to a blank tag or something. I'm not sure. I'm sorry I'm really blind here trying to figure this out. Sure would appreciate some help. Thank you.

The "BambuHandy Create Tag" will write a tag, that, when scanned with a mobile device, opens BambuHandy on that device (if installed)

The "OpenSpool Create Tag" will write a tag, that, when scanned with a mobile device, opens the browser with the website of your openspool device.

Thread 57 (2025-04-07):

Wrong filament codes for Sunlu and missing code

raihei, 2025-04-07:
Filament codes for Sunlu should be GFSNL03 (PLA+) and GFSNL08 (PETG).

Current codes are SNL02 (PLA matte) and SNL08 (PETG) without leading "GF"

Also, in automation.yaml code for Sunlu filaments is missing.

Will create a pull request which also fixes #45

Closed 2025-04-08.

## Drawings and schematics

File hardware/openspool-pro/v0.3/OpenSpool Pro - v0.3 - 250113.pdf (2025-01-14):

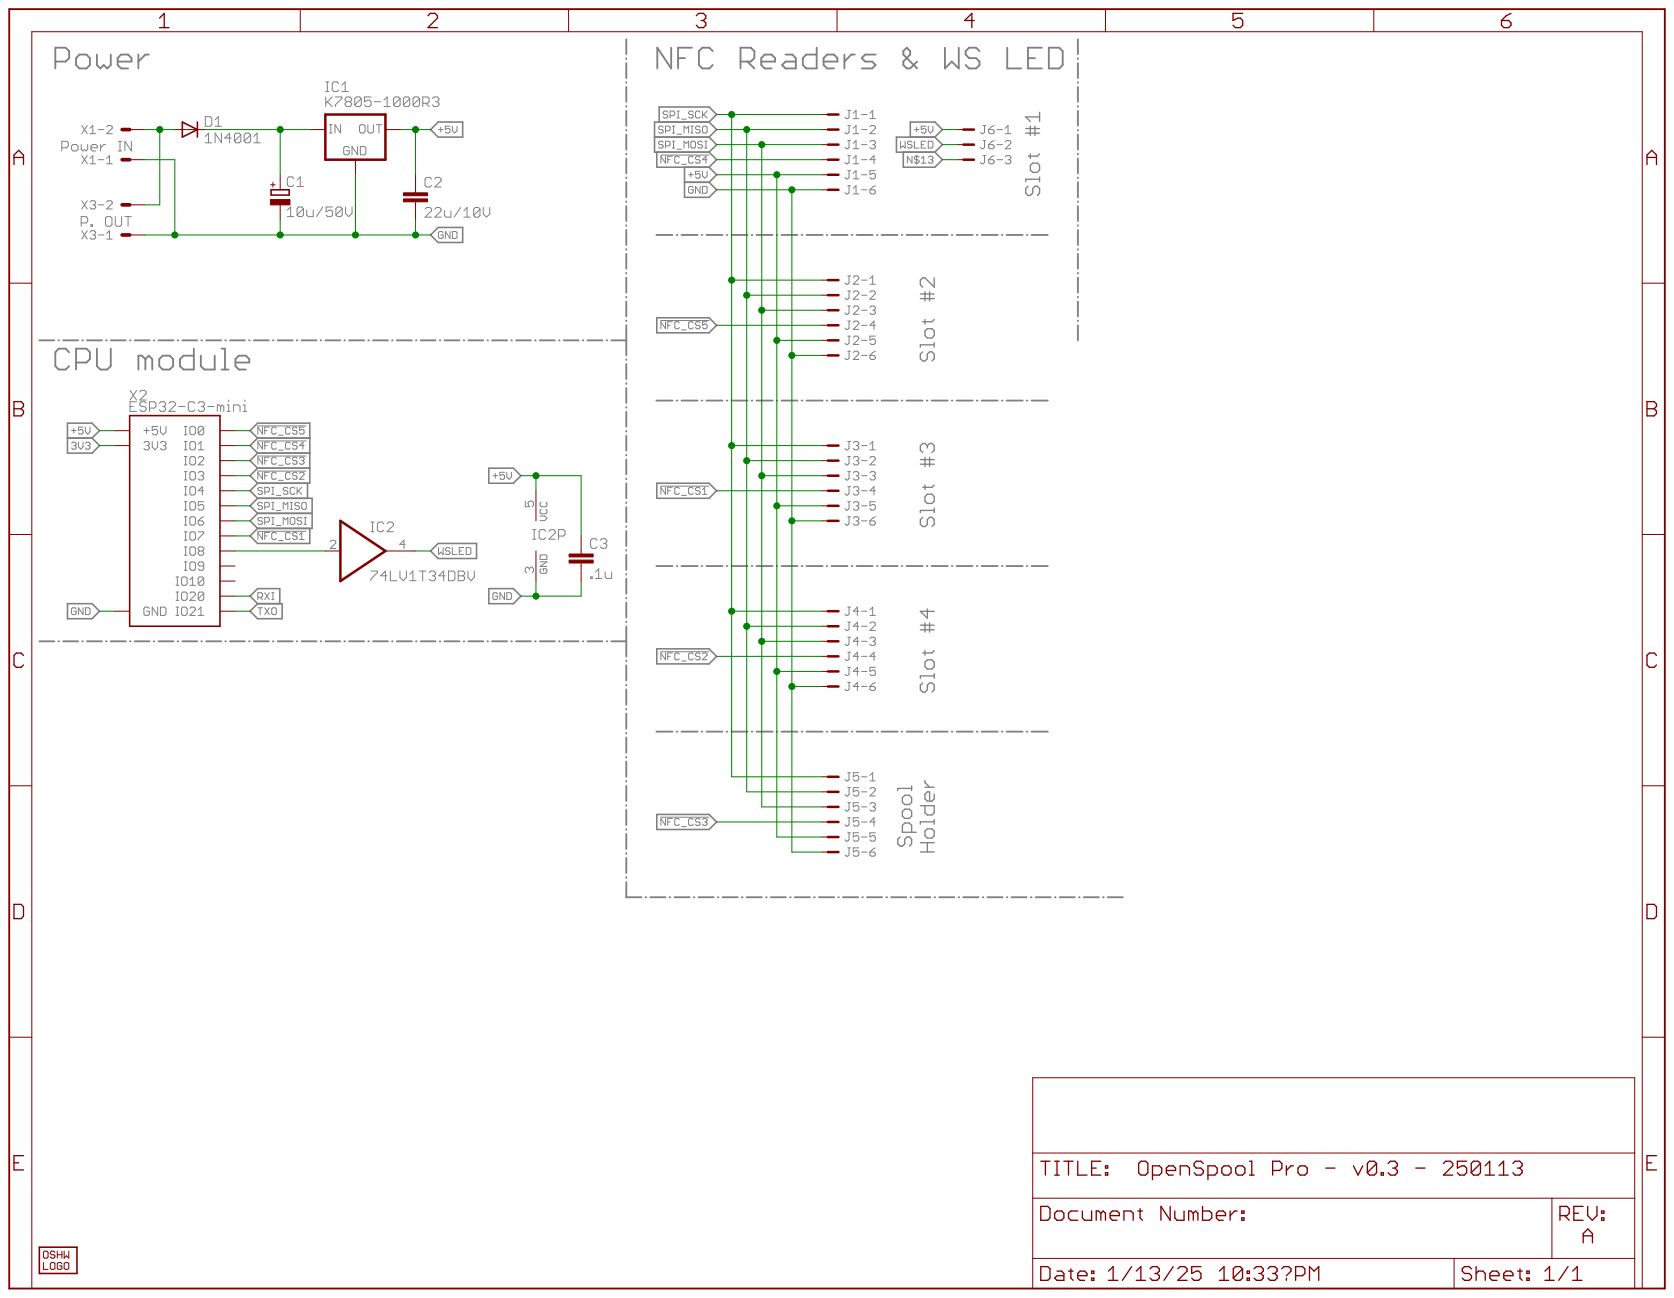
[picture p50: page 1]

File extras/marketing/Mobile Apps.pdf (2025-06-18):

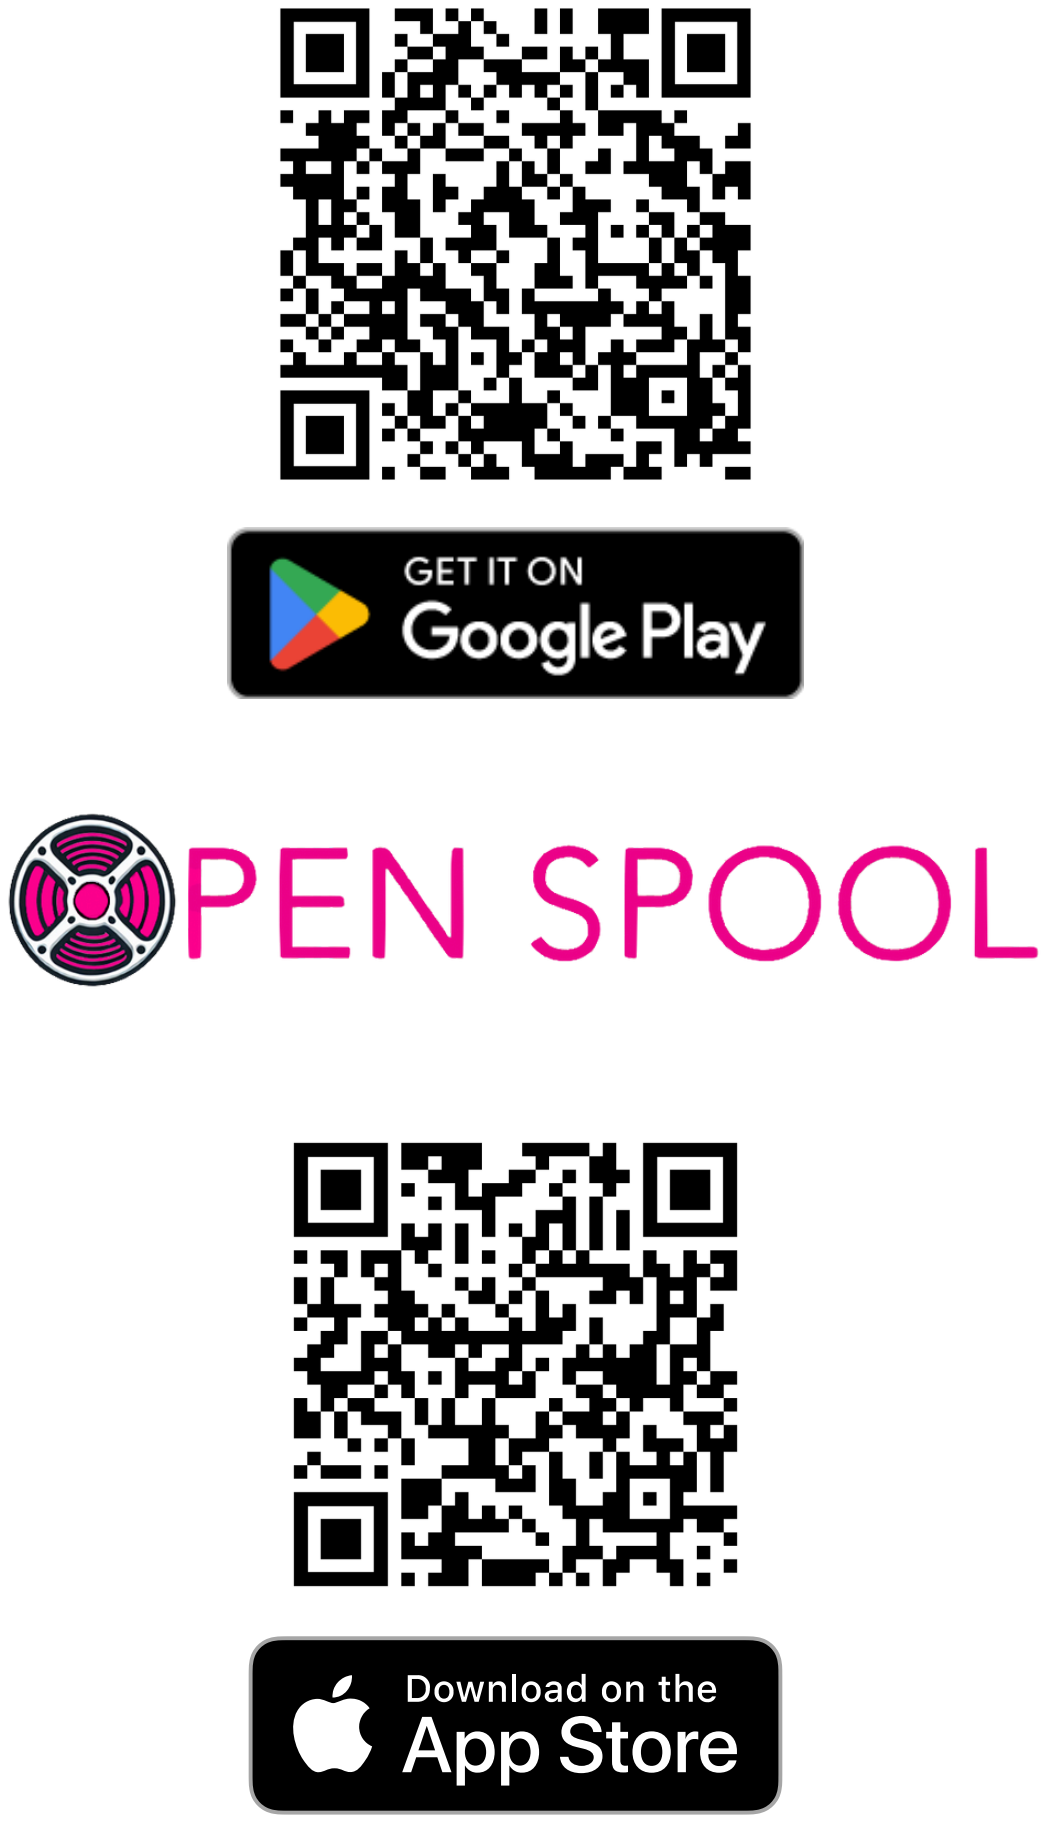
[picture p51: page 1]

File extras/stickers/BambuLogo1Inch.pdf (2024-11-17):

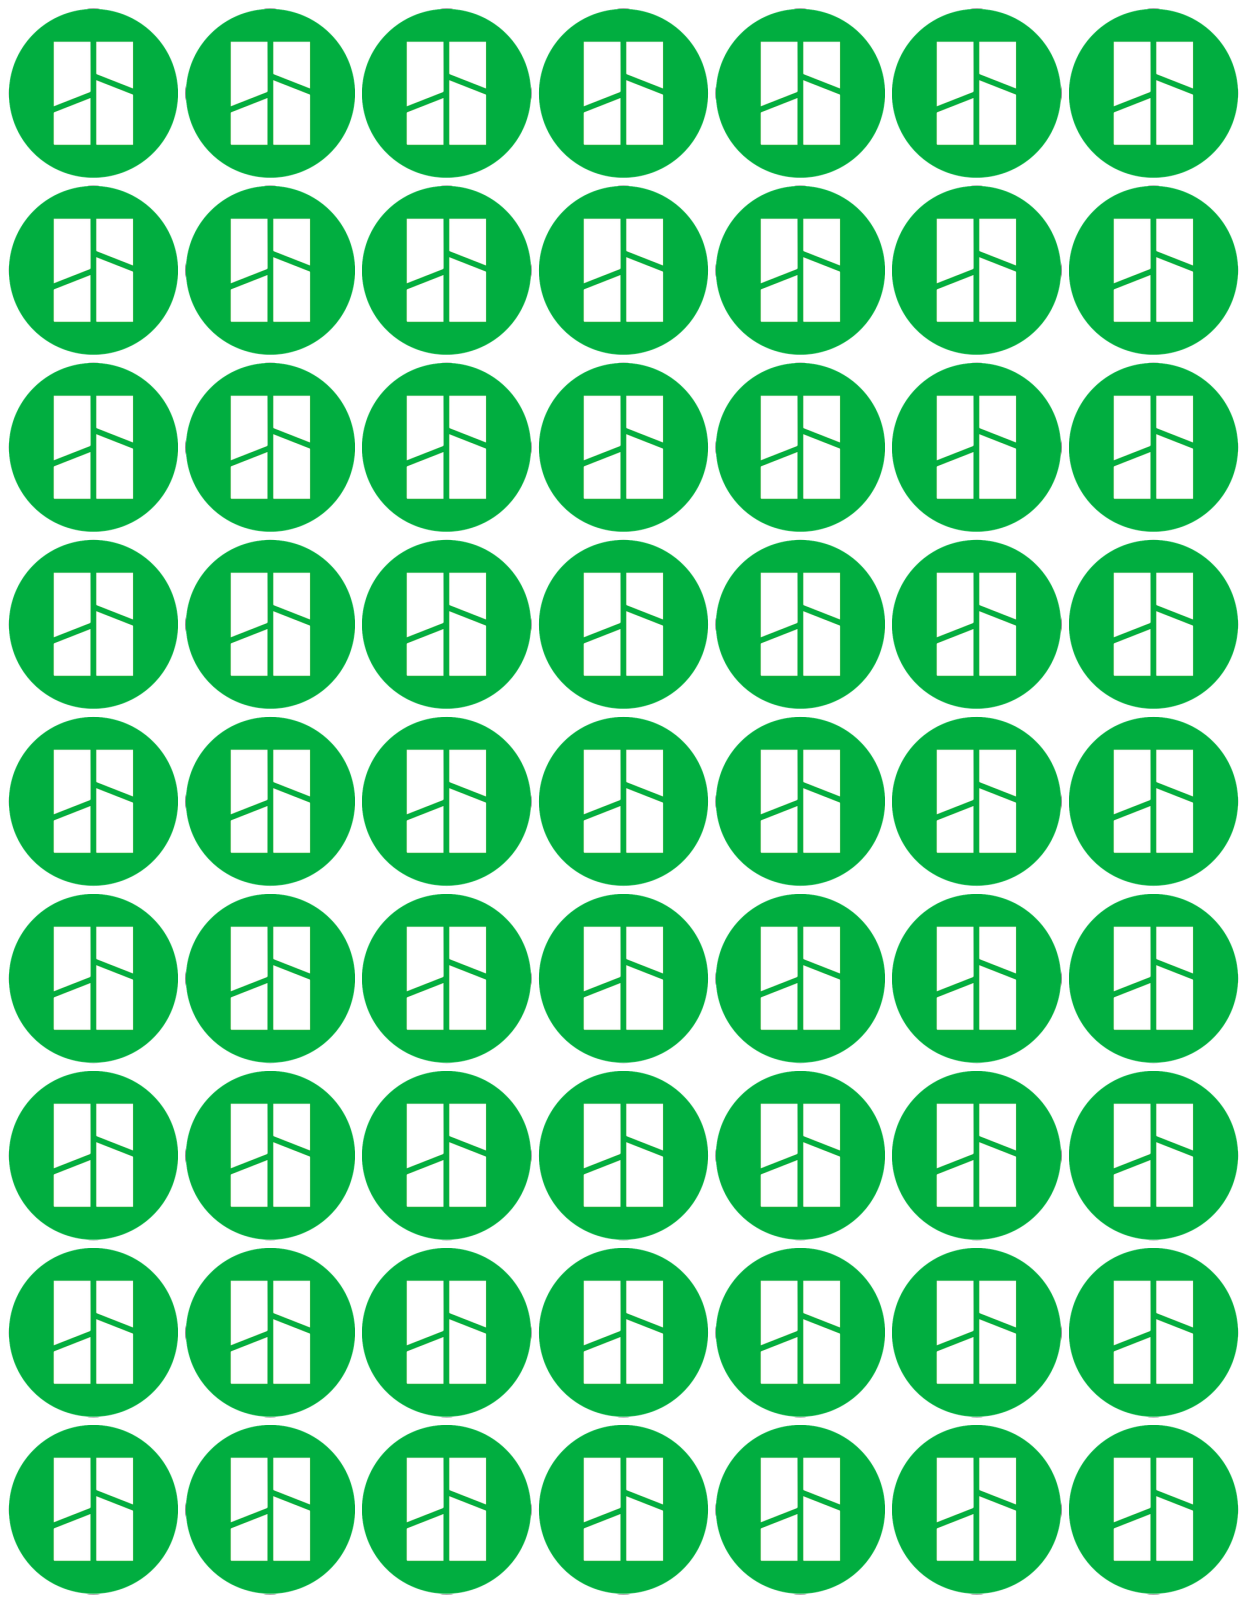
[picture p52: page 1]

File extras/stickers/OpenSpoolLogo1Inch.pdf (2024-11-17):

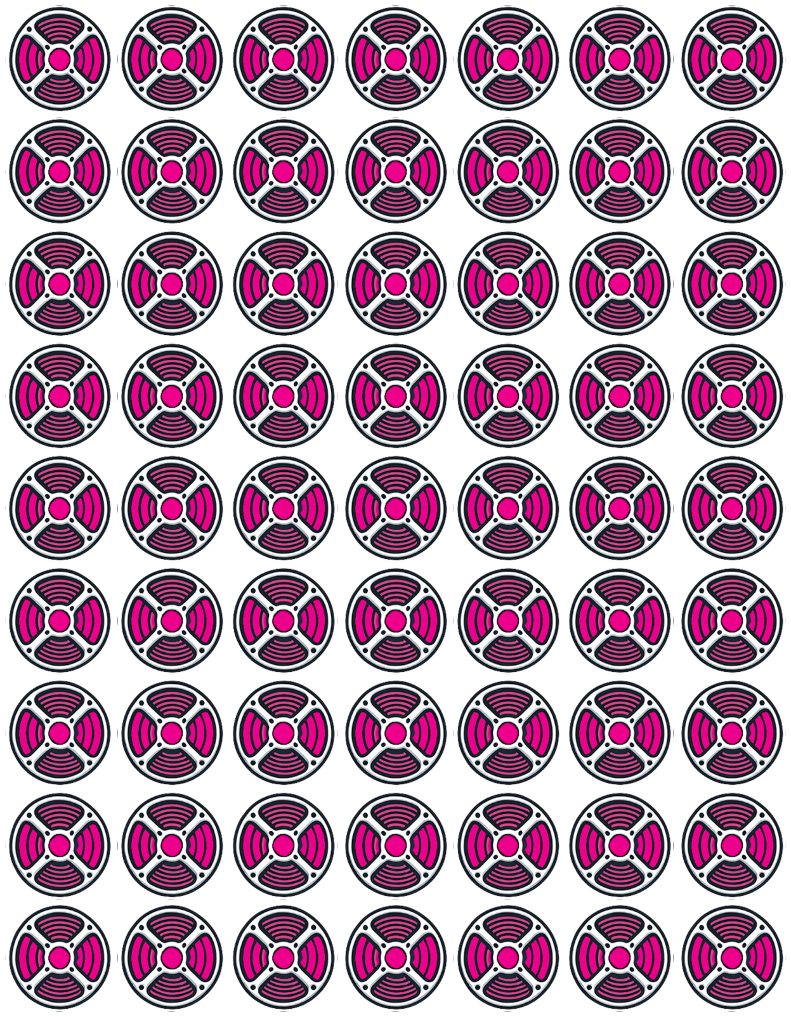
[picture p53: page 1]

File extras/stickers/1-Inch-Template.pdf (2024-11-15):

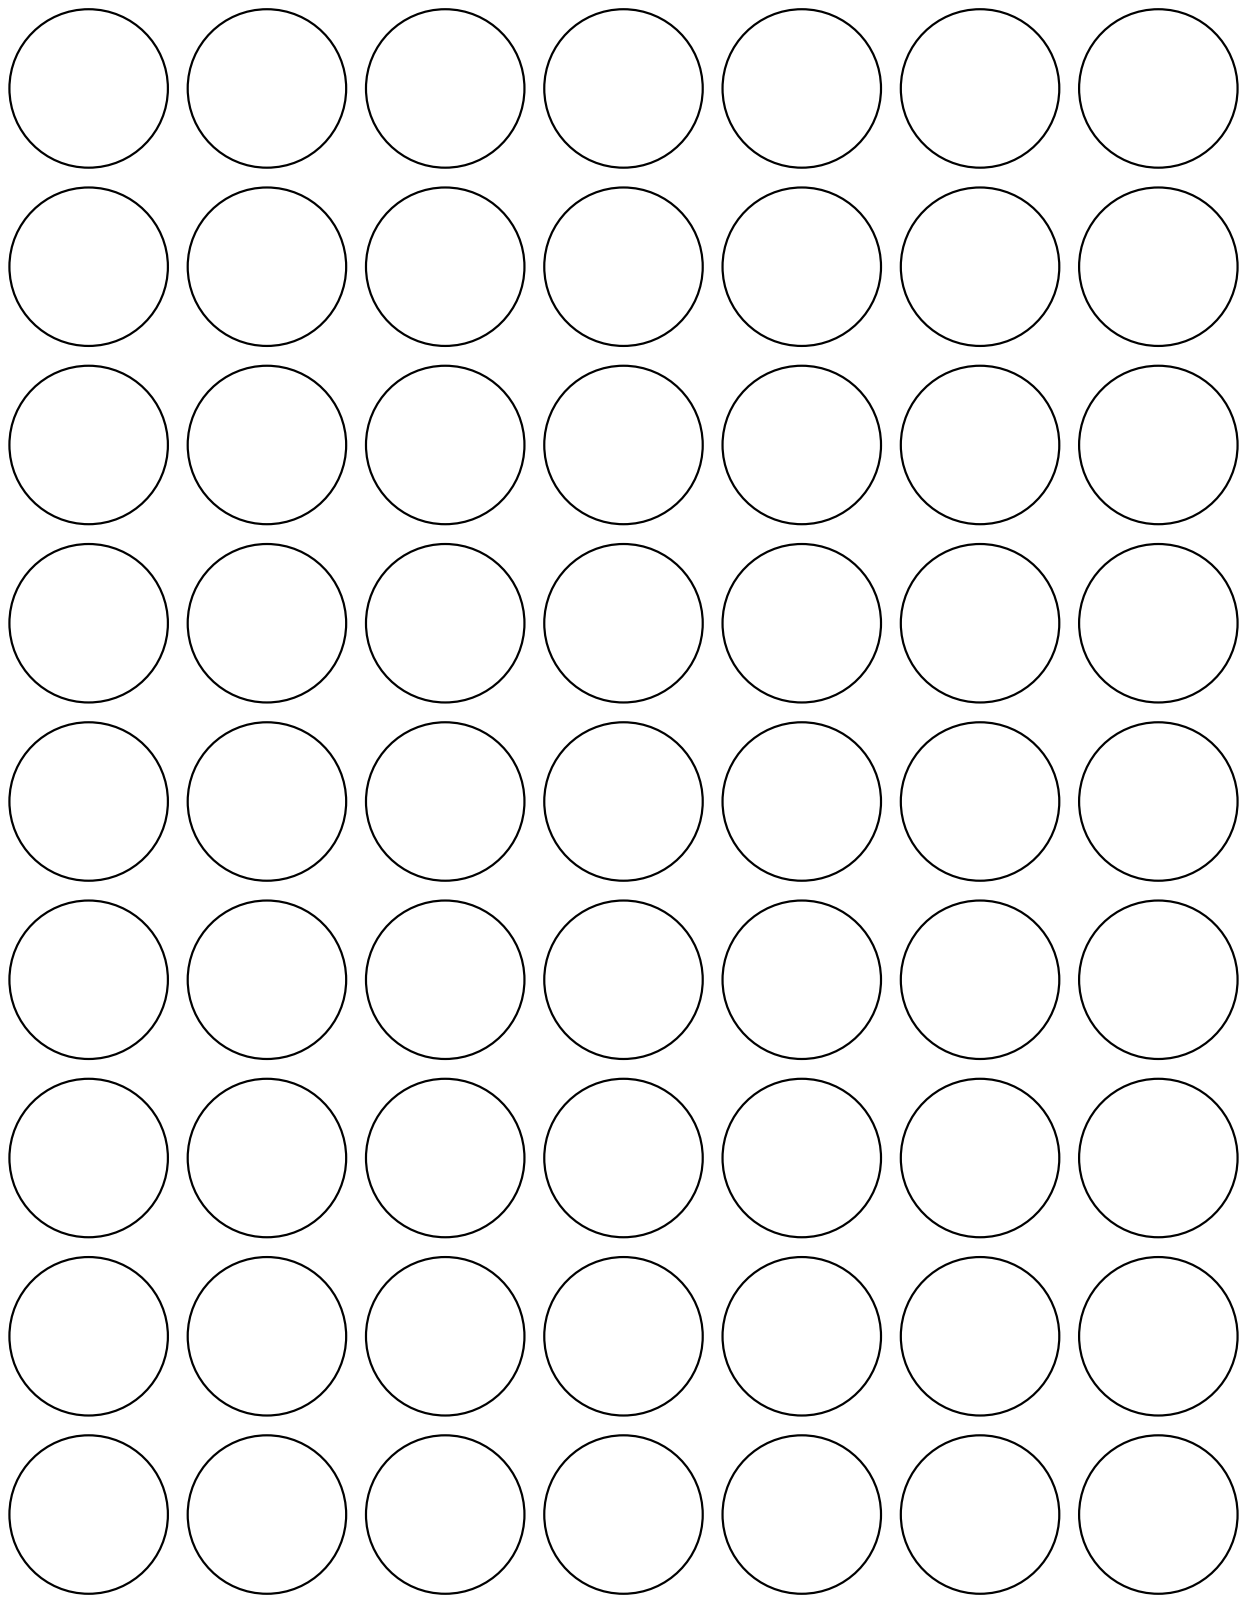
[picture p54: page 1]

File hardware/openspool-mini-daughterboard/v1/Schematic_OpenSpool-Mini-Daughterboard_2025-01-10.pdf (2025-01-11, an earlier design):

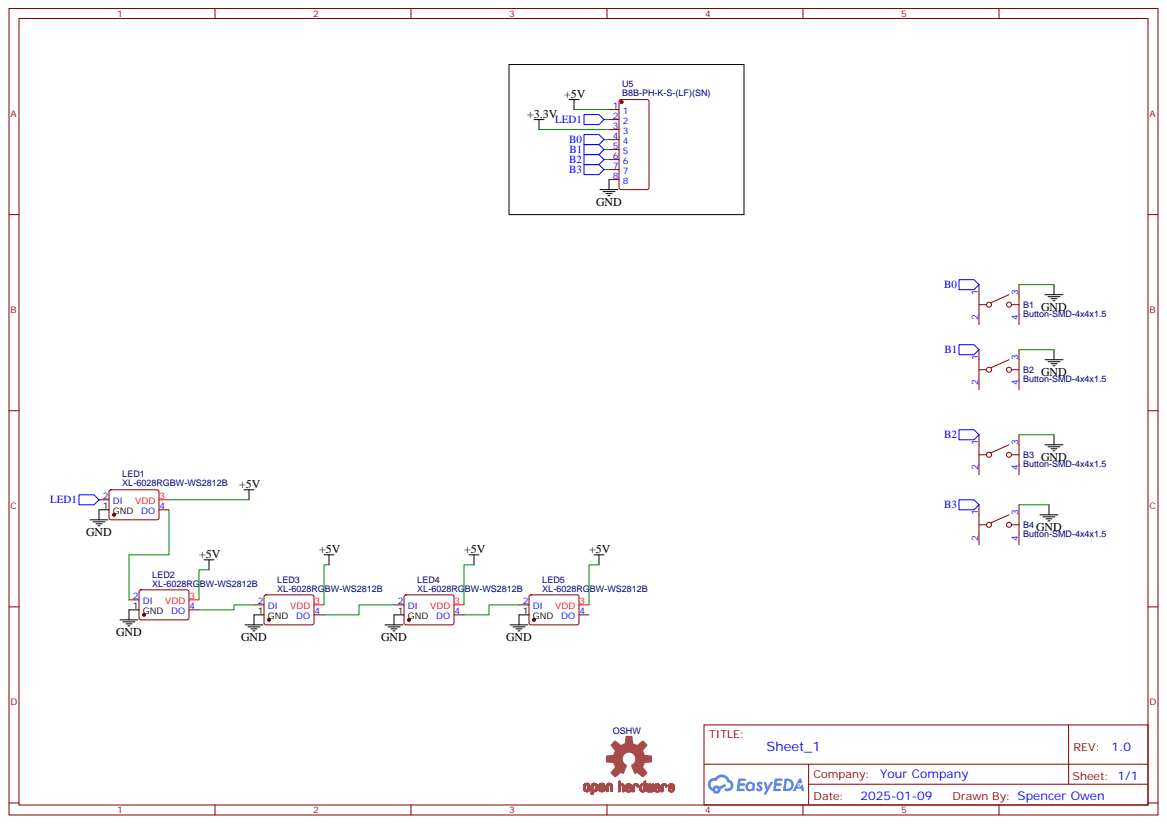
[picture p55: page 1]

Drawn By: Spencer Owen

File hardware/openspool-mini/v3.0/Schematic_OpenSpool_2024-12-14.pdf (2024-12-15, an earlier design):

## Logic Level Shifter

PN532 Header | DaughterBoard Header

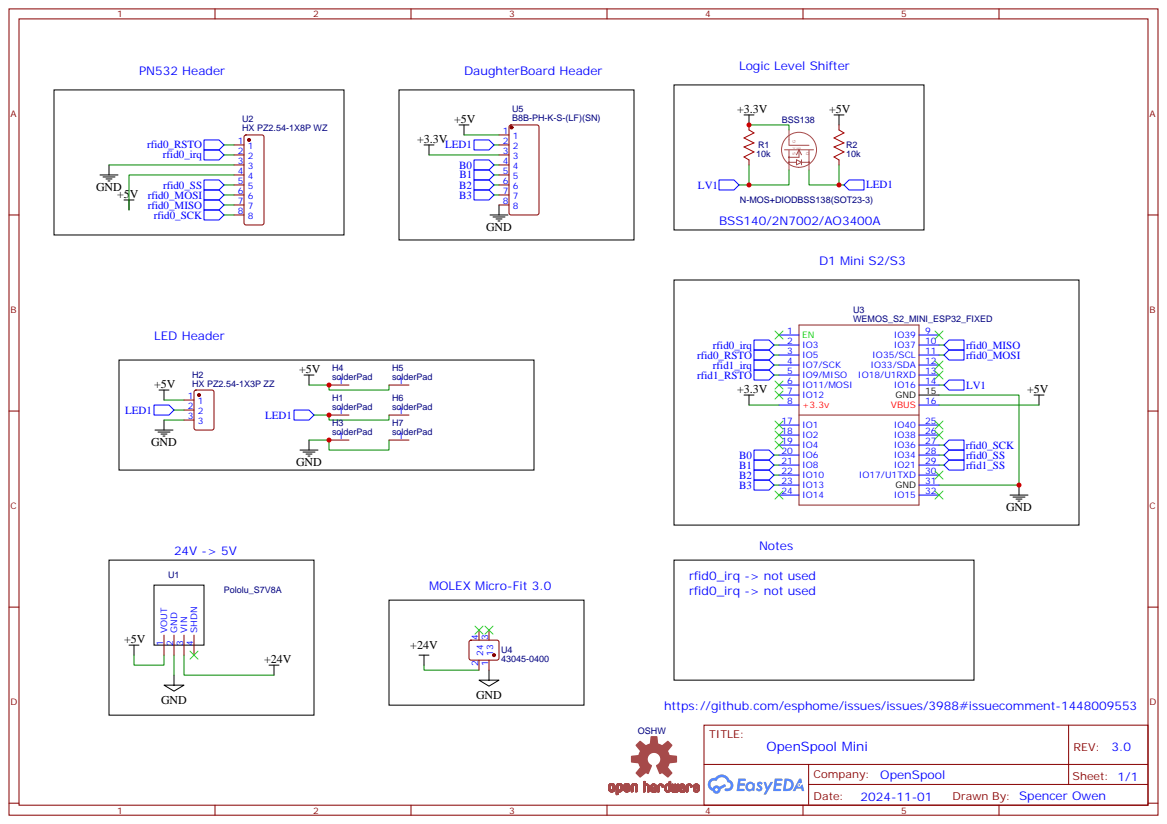
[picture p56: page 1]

https://github.com/esphome/issues/issues/3988#issuecomment-1448009553

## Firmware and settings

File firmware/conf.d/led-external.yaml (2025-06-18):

---
substitutions:
  led_count: '9'
light:
- platform: esp32_rmt_led_strip
  name: LEDs
  id: neopixel_light
  state_topic:
  pin: ${led_pin}
  num_leds: ${led_count}
  rgb_order: GRB
  chipset: WS2812
  default_transition_length: 0.4s
  restore_mode: RESTORE_DEFAULT_ON
  entity_category: diagnostic
  icon: mdi:led-strip
  effects:
  - addressable_rainbow:
      name: Rainbow
      speed: 25
      width: 15
  - addressable_lambda:
      name: Breathing Blue
      update_interval: 10ms
      lambda: |-
        static float b = 0;
        b = (sin(millis() / 500.0) + 1.0) / 2.0 * 0.6 + 0.4;
        auto color = esphome::light::ESPColor(0, 0, uint8_t(255 * b));
        it.all() = color;
  - addressable_lambda:
      name: Apple Breathing
      update_interval: 10ms
      lambda: |-
        const float PI = 3.14159265359;
        //TODO: 42.546 should be replaced by 83.333
        float t = millis() / 2000.0;
        float brightness_float = (exp(sin(t * PI)) - 0.368) * 42.546;
        uint8_t brightness = uint8_t(brightness_float);
        auto color = esphome::light::ESPColor(brightness, 0, 0);
        for (int i = 0; i < it.size(); ++i) {
          it[i] = color;
        }
      #   - strobe:
      #       name: "Data Upload"
      #       colors:
      #         - state: TRUE
      #           brightness: 100%
      #           duration: 50ms
      #           red: 0%
      #           green: 100%
      #           blue: 0%
      #         - state: FALSE
      #           duration: 50ms
script:
- id: set_led_red
  parameters:
    led_number: int8_t
  then:
  - light.addressable_set:
      id: neopixel_light
      color_brightness: 100%
      range_from: !lambda "return led_number < 0 ? 0 : led_number;"
      range_to: !lambda "return led_number < 0 ? ${led_count} : led_number;"
      red: 100%
      green: 0%
      blue: 0%
- id: set_led_green
  parameters:
    led_number: int8_t
  then:
  - light.addressable_set:
      id: neopixel_light
      color_brightness: 100%
      range_from: !lambda "return led_number < 0 ? 0 : led_number;"
      range_to: !lambda "return led_number < 0 ? ${led_count} : led_number;"
      red: 0%
      green: 100%
      blue: 0%
- id: set_led_blue
  parameters:
    led_number: int8_t
  then:
  - light.addressable_set:
      id: neopixel_light
      color_brightness: 100%
      range_from: !lambda "return led_number < 0 ? 0 : led_number;"
      range_to: !lambda "return led_number < 0 ? ${led_count} : led_number;"
      red: 0%
      green: 0%
      blue: 100%
- id: set_led_yellow
  parameters:
    led_number: int8_t
  then:
  - light.addressable_set:
      id: neopixel_light
      color_brightness: 100%
      range_from: !lambda "return led_number < 0 ? 0 : led_number;"
      range_to: !lambda "return led_number < 0 ? ${led_count} : led_number;"
      red: 100%
      green: 100%
      blue: 0%
- id: set_led_white
  parameters:
    led_number: int8_t
  then:
  - light.addressable_set:
      id: neopixel_light
      color_brightness: 50%
      range_from: !lambda "return led_number < 0 ? 0 : led_number;"
      range_to: !lambda "return led_number < 0 ? ${led_count} : led_number;"
      red: 100%
      green: 100%
      blue: 100%
- id: set_all_leds_white
  then:
  - light.turn_on:
      id: neopixel_light
      effect: none
      brightness: 50%
      red: 100%
      green: 100%
      blue: 100%
- id: set_led_off
  then:
  - light.turn_on:
      id: neopixel_light
      brightness: 0%
      red: 0%
      green: 0%
      blue: 0%
      effect: none
  - delay: 50ms
  - light.turn_off:
      id: neopixel_light
      transition_length: 0s
- id: set_led_rainbow
  then:
  - light.turn_on:
      id: neopixel_light
      effect: Rainbow
- id: set_led_breathing_blue
  then:
  - light.turn_on:
      id: neopixel_light
      effect: none
  - light.turn_on:
      id: neopixel_light
      effect: Breathing Blue
      brightness: 100%
- id: set_led_breathing_green
  then:
  - light.turn_on:
      id: neopixel_light
      effect: Breathing Green
      brightness: 100%
- id: set_led_apple_breathing
  then:
  - light.turn_on:
      id: neopixel_light
      effect: Apple Breathing
      brightness: 100%

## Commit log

2024-10-16 Working button dynamic lookup
2024-10-17 Add filament
2024-10-17 Show printer model
2024-10-17 Succesful switching using json builder
2024-10-18 Filament publish
2024-10-18 add button
2024-10-22 Change pins to allow leds
2024-10-26 Improve LED colors
2024-10-27 Cleanup leds
2024-10-27 Set LEd to white
2024-10-27 Fix bug "UnknownFF" in bambu filament color
2024-10-29 Add reset button
2024-10-30 Revert name to openspool, update leds, add improv
2024-10-31 Add LEDs to parts list
2024-10-31 Speed up LEDS, Add documentation for PN542 large
2024-11-01 Parameterize SPI pins for PCB
2024-11-02 Fix mappings of filament
2024-11-02 add exotic filaments
2024-11-03 Add variables for board
2024-11-04 Fix esp32 builds
2024-11-05 Correct wiring diagram
    [OpenSpool.fzz]
2024-11-06 Add pcb
    [OpenSpool.fzz]
2024-11-06 Scaffolding for multiple RFID Readers
    [OpenSpool.fzz]
2024-11-09 Increase leds
2024-11-09 Refactor to allow multipe rfid readers, rename esp32s2 to 'solo' in preparation for ams
    [OpenSpool.fzz]
2024-11-09 Fix deploy for esp32s2
2024-11-10 Working leds
2024-11-11 Add icons
    [Logo v11.step]
2024-11-14 Fix led flicker on boot
2024-11-16 Add fritzing Doc
    [OpenSpool-Mini.fzz]
2024-11-16 Add images
    [OpenSpool-Mini.fzz]
2024-11-17 Fix buttons in docs
2024-11-18 Change pins for AMS Add openspool URL sensor Reduce solo to single RFID reader, move to AMS Add 'extras' group to wifi
    [OpenSpool-AMS.fzz]
2024-11-18 Add i2c for legacy
2024-11-19 Add buttons to create shortcut tags
2024-11-20 Add v2 schematics Add mdi icon for led strip
2024-11-20 Add v2.1 of pcb
2024-11-20 Add pre-commit hook Replace v2.1 pcb image
2024-11-21 Improve boot led animations
2024-11-22 Add checks if mqtt is connected
    [OpenSpool.fzz]
2024-11-23 Add esp32s3
2024-11-25 Remove power_save_mode for wifi Disable wifi output power limits on esp32s3
2024-11-26 Update diagram
    [OpenSpool-Mini.fzz]
2024-11-26 Update wiring diagram
2024-11-26 Fix yellow wire in diagrams
    [OpenSpool-Mini.fzz]
2024-11-27 Reverse order of web_server print settings. Move Write NFC to the top Hide Filament Color Hex Bambu Make white color default
2024-11-27 Update fritzing
    [OpenSpool-Mini.fzz]
2024-11-28 Diagram fix for pcb
2024-11-30 Reduce brightness of white to reduce heat
2024-12-01 Add support for onboard neopixel led on s3, refactor includes for clarity
2024-12-01 Update license, add BOM
    [BOM.csv]
2024-12-04 Remove filament color hex bambu
2024-12-05 Add button back to s2
2024-12-05 Downgrade platform.io framework to stable
2024-12-08 Fix missing color when uploading using button
2024-12-09 Fix button.yaml on lolin_s3
2024-12-09 Add icon for internal led
2024-12-14 Add more Filament types and order type and color
2024-12-15 Add v3 pcb
    [BOM_OpenSpool_2024-12-14.csv, PickAndPlace_PCB_OpenSpool_2024-12-14.csv]
2024-12-25 Release version 3.1
    [BOM_OpenSpool_2024-12-24.csv, PCB_OpenSpool_2024-12-24.dxf]
2024-12-26 Fix silkscreen on 3.1 pcb
2025-01-07 rename hardware directory
    [BOM.csv, BOM_OpenSpool_2024-12-14.csv, BOM_OpenSpool_2024-12-24.csv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]
2025-01-11 add daughter board
    [BOM_OpenSpool-Mini-Daughterboard_2025-01-10.csv, PickAndPlace_PCB_OpenSpool-Mini-Daughterboard_2025-01-10.csv]
2025-01-12 Added sorting_weight to filament settings for web server.
2025-01-14 add pro hardware
    [OpenSpool Pro - v0.3 - 250113.f3d, OpenSpool-AMS.fzz]
2025-01-15 Disabled internal LED, fixed pin naming.
2025-01-16 fixed ss pin naming
2025-01-18 Allow tags with filament color alpha channel value
2025-01-26 Add image of PCB
2025-01-27 Allow creation of tags with filament color alpha channel value
2025-03-01 Pin esphome version
2025-04-07 Fixed Sunlu filaments and created LED feedback for write tag finished
2025-06-18 Add rmt symbols size to internal led (needed if using external led)
2025-06-18 add daughterboard
    [BOM_OpenSpool-Mini-Daughterboard_2025-06-16.csv, PickAndPlace_PCB_OpenSpool-Mini-Daughterboard_2025-06-16.csv]
2025-07-30 Update Fritzing file and wiring diagram
    Creates a modded version of the WS2812B strip part with just an individual LED.
    [OpenSpool-Mini.fzz]
2025-07-30 Update list of required hardware to mention custom PCB
2025-07-31 Add assembly instructions
2025-08-01 Mention to solder to top side of PN532
